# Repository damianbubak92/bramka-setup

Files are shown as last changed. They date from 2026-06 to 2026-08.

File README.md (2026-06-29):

# Bramka IoT - Setup & Development Repository

Repozytorium konfiguracji i kodu dla bramki IoT na AM62 SoC (SK-AM62B-P1 dev kit).

## Architektura

- **SoC**: TI AM62 (Cortex-A53 quad + Cortex-M4F + Cortex-R5F)
- **Linux**: Arago 2025.01 (kernel 6.18.13-ti, ARM64)
- **Komunikacja**: Linux ↔ M4F przez RPMsg (binary protocol z CRC16)
- **Język aplikacji Linux**: Go 1.23.x (instalowany przez `Gateway/Setup/modules/04-go.sh`)
- **Firmware M4F**: TI MCU+ SDK 12.00, NoRTOS

## Struktura repo

> Ten README opisuje **wczesny stan (sama bramka, RPMsg)**. Projekt urósł do
> **monorepo `SmartHome`** (engine M4F, CC1310 RF, nody, apka Android) — pełny
> aktualny stan, konwencje i Session Log w **`CLAUDE.md`**. (Repo na GitHub wciąż
> nazwany `bramka-setup`; może zostać przemianowany na `SmartHome`.)

```
SmartHome/                (zmigrowane z bramka-setup 2026-06-29)
├── Gateway/              # bramka (A53 Linux + M4F + CC1310 RF)
│   ├── Software/         #   Go: rpmsg-service (RPMsg bridge + HTTP/WS API, cgo)
│   ├── Firmware/         #   CCS: M4F (gateway_m4f) + CC1310 (gateway_cc1310)
│   ├── Setup/            #   setup.sh, modules/, systemd/, tools/, config.sh
│   └── Hardware/         #   carrier board (TODO)
├── Nodes/                # TempHumNode/{Firmware = temphum_node, Hardware}, Light/Solar (szkielety)
├── Apps/                 # MobileApp/AndroidApp/SmartHomeV2 (Android Studio); iOS/, WebApp/ (TODO)
├── Shared/               # Protocol/ (node_protocol.h, protocol.h, spi_frame.h — SINGLE SOURCE), KiCadLib/
└── Docs/
```

## Quick start

### 1. Instalacja bramki (od zera)
```bash
# 1. Świeży flash karty SD (Etcher)
# 2. SSH do bramki:
git clone https://github.com/damianbubak92/bramka-setup
cd bramka-setup/Gateway/Setup
sudo ./setup.sh    # network + tools + m4f firmware backup + GO INSTALL
reboot
# 3. Z laptopa:
Deploy-M4F                                            # custom M4F firmware
Deploy-Go -ServiceName rpmsg-service -Build           # build Go binary
Install-GoService -ServiceName rpmsg-service          # systemd unit
```

### 2. Workflow developerski

**M4F firmware** (z laptopa, PowerShell):
```powershell
# Build w CCS Theia (Ctrl+Shift+B)
Deploy-M4F                         # 5s logów
Deploy-M4F -LogForever             # logi do Ctrl+C
Deploy-M4F -NoLogs                 # bez logów
```
> `m4f-reload` (woła go `Deploy-M4F`) sam zatrzymuje `rpmsg-service` przed
> `echo stop` M4F i restartuje po starcie. Bez tego serwis wykryłby zniknięcie
> `/dev/rpmsg` jako PEER DEAD i zrobił reboot bramki w trakcie podmiany firmware.

**Go service** (z laptopa, PowerShell):
```powershell
Deploy-Go -ServiceName protocol-test -Build -Run
```

### 3. Monitor

```bash
ssh root@bramka-01
m4f-watch                          # live M4F trace
```

## Status (v5)

- ✅ Setup script (Linux configuration, network, tools, M4F firmware)
- ✅ M4F graceful shutdown handler (hot-swap firmware bez reboot)
- ✅ Go runtime (cgo działa, łączy się z shared C header)
- ✅ Binary protocol (CRC16-CCITT, packed wire format, big-endian)
- ✅ HELLO/HELLO_ACK exchange w binary protocol
- ✅ State machine: DISCONNECTED → HELLO_SENT → CONNECTED → DEAD
- ✅ Reliable DATA delivery (ACK + 3 retries z 1s timeout)
- ✅ Idempotency check (duplicate detection w M4F)
- ✅ EVENT (M4F→Linux autonomous events z ACK + retry)
- ✅ Bidirectional reliable messaging w pełni działa (~5ms RTT)
- ✅ **Warstwa A**: systemd watchdog dla Go service (`Restart=on-failure` + `StartLimitBurst=3`)
- ⏸️ **Warstwa B**: M4F self-watchdog (RTI) - skipped, do later
- ⏳ **Warstwa C**: M4F → Linux reset via DMSC
- ✅ **Warstwa D**: Linux HW watchdog (`/dev/watchdog` via systemd, `RuntimeWatchdogSec=30`) - konfigurowany przez `modules/05-watchdog.sh` (był zgubiony przy re-flashu, przywrócony 15.06.2026)
- ✅ **panic_on_oops=1** (`modules/06-kernel-panic.sh`): oops → pełny panic → łapie Warstwa D. Domyka lukę "oops kaleczy kernel ale systemd dalej klepie watchdog → nic nie łapie"
- ✅ **Boot accounting** (`modules/07-boot-accounting.sh`): licznik bootów + atrybucja przyczyny (breadcrumb Go / kernel panic / clean-shutdown / hard reset) + alarm reboot-storm (sparametryzowany `/etc/bramka/boot-accounting.conf`, default >3/24h). Persistent journald (50M). Podgląd: `bramka-reboots`
- ✅ **Non-root hardening** (`modules/08-hardening.sh`): `rpmsg-service` jako user `bramka` (zero capabilities). Device przez udev (grupa `bramka`), reboot przez path-unit (`bramka-reboot.path/.service`, bez roota/polkit). Binarka w `/opt/bramka` (Deploy-Go: cel `/opt/bramka`)
- ✅ **Heartbeat jednokierunkowy Linux→M4F**: Go pinguje M4F co 5s idle; brak odpowiedzi (~9s) = M4F martwy → **clean reboot** (`recoverByReboot`). M4F-initiated heartbeat usunięty (opcja A). Brak per-core reset M4F na AM62 - jedyna recovery to pełny reset SoC.
- ✅ **Cold-boot race fix**: serwis czeka na `/dev/rpmsg*` (`waitForM4FChrdev`) zamiast paść gdy M4F jeszcze się podnosi
- ⏳ Yocto build - later

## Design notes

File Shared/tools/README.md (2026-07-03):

# Shared/tools

Dev-laptop helpers (PowerShell), wersjonowane dla odtwarzalności / disaster-recovery.

## `Microsoft.PowerShell_profile.ps1`

Snapshot profilu PowerShell z laptopa deweloperskiego. **To kopia** — żywy plik
to `$PROFILE` (`C:\Users\<user>\Documents\WindowsPowerShell\Microsoft.PowerShell_profile.ps1`).
Po zmianach w profilu odśwież tę kopię (`cp $PROFILE Shared/tools/`).

Zawiera:
- **Bramka deploy helpers**: `Deploy-Go`, `Deploy-M4F`, `Install-GoService`,
  `Watch-M4F`, `Test-Rpmsg`, `Connect-Bramka`, `Get-M4FState` (`$BRAMKA_HOST = root@192.168.2.170`).
- **KiCad**: `Add-LcscPart` (alias `lcsc`) — pobiera część z LCSC przez
  `easyeda2kicad` i wpina do bibliotek `Shared/KiCadLib` (symbol z auto-footprintem,
  footprint → `SmartHome.pretty`, model 3D → `3dmodels`). Idempotentny
  (wykrywa po property `"LCSC Part"`); `lcsc <id> -Force` = odśwież.
  Wymaga `pip install easyeda2kicad`.

### Przywrócenie na nowym laptopie
```powershell
mkdir (Split-Path $PROFILE) -Force
Copy-Item Shared/tools/Microsoft.PowerShell_profile.ps1 $PROFILE -Force
pip install easyeda2kicad   # dla helpera KiCad
. $PROFILE
```

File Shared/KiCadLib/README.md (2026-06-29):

# Shared/KiCadLib — współdzielona biblioteka KiCad (SmartHome)

Wspólne **custom / vendor** symbole, footprinty i modele 3D dla wszystkich projektów
hardware w monorepo (`Gateway/Hardware`, `Nodes/*/Hardware`).

## Co tu trzymamy (a czego NIE)
- ✅ Części **niestandardowe / vendor / specyficzne**: CC1310 (QFN RGZ 7×7), balun,
  holder 18500, MCP73123 / TPS63900 / MCP3421, nietypowe złącza, antena.
- ❌ **Generyczne pasywy** (R/C/L SMD, diody ESD, generyczny QFN) — bierz z
  **wbudowanych bibliotek KiCada** (`Resistor_SMD`, `Capacitor_SMD`,
  `Package_DFN_QFN`…). Nie kopiuj ich tutaj — biblioteka ma być chuda.

## Struktura
```
Shared/KiCadLib/
├── SmartHome.pretty/      # footprinty (1 plik .kicad_mod = 1 footprint)
├── SmartHome.kicad_sym    # symbole (utwórz w Symbol Editor → New Library, gdy rysujesz własne)
└── 3dmodels/              # modele 3D (.step / .wrl)
```

## Rejestracja w KiCad (raz na maszynę)
1. **Preferences → Configure Paths** → dodaj zmienną:
   - `SMARTHOME_LIB` = `C:/SmartHome/Shared/KiCadLib`
2. **Preferences → Manage Footprint Libraries → Project Specific Libraries** → **Add**:
   - Nickname: `SmartHome`
   - Path: `${SMARTHOME_LIB}/SmartHome.pretty`
3. (Symbole, jeśli są) **Manage Symbol Libraries → Project Specific** → **Add**:
   - Nickname: `SmartHome`
   - Path: `${SMARTHOME_LIB}/SmartHome.kicad_sym`

> Zakładka **Project Specific** = tabela (`fp-lib-table` / `sym-lib-table`) jedzie z repo
> → odtwarzalne. Każda nowa maszyna ustawia tylko `SMARTHOME_LIB` (krok 1) i działa.
> Modele 3D w `.kicad_mod` referencjonuj przez `${SMARTHOME_LIB}/3dmodels/...`.

## Użycie
Przy przypisywaniu footprintu/symbolu wybierasz bibliotekę **`SmartHome:`**
(np. `SmartHome:CC1310_RGZ_VQFN48`).

## Git
- `.kicad_mod` / `.kicad_sym` / `.pretty` = tekst → commituj normalnie.
- `.step` / `.wrl` = binarne → commituj jeśli małe; duże/pobieralne lepiej pominąć.

## Uwaga RF (CC1310 QFN)
Sprawdź land-pattern z datasheet TI — **thermal pad + raster vias pod padem masy**
są krytyczne dla RF i termiki. Generyczny `QFN-48-1EP_7x7mm_P0.5mm` może wystarczyć,
ale porównaj z zaleceniem TI; jak się różni → zrób custom footprint tutaj.

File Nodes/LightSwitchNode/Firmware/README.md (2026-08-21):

## Example Summary

Application that toggles an LED(s) using a GPIO pin interrupt.

## Peripherals & Pin Assignments

When this project is built, the SysConfig tool will generate the TI-Driver
configurations into the __ti_drivers_config.c__ and __ti_drivers_config.h__
files. Information on pins and resources used is present in both generated
files. Additionally, the System Configuration file (\*.syscfg) present in the
project may be opened with SysConfig's graphical user interface to determine
pins and resources used.

* `CONFIG_GPIO_LED_0` - Indicates that the board was initialized within
  `mainThread()` also toggled by `CONFIG_GPIO_BUTTON_0`
* `CONFIG_GPIO_LED_1` - Toggled by `CONFIG_GPIO_BUTTON_1`
* `CONFIG_GPIO_BUTTON_0` - Toggles `CONFIG_GPIO_LED_0`
* `CONFIG_GPIO_BUTTON_1` - Toggles `CONFIG_GPIO_LED_1`

## BoosterPacks, Board Resources & Jumper Settings

For board specific jumper settings, resources and BoosterPack modifications,
refer to the __Board.html__ file.

> If you're using an IDE such as Code Composer Studio (CCS) or IAR, please
refer to Board.html in your project directory for resources used and
board-specific jumper settings.

The Board.html can also be found in your SDK installation:

```text
<SDK_INSTALL_DIR>/source/ti/boards/<BOARD>
```

## Example Usage

* Run the example. `CONFIG_GPIO_LED_0` turns ON to indicate driver
initialization is complete.

* `CONFIG_GPIO_LED_0` is toggled by pushing `CONFIG_GPIO_BUTTON_0`
* `CONFIG_GPIO_LED_1` is toggled by pushing `CONFIG_GPIO_BUTTON_1`

## Application Design Details

* The `gpioButtonFxn0`/`gpioButtonFxn1` functions are configured in the driver
  configuration file. These functions are called in the context of the GPIO
  interrupt.

* Not all boards have more than one button, so `CONFIG_GPIO_LED_1` may not be
toggled.

* There is no button de-bounce logic in the example.

TI-RTOS:

* When building in Code Composer Studio, the configuration project will be
imported along with the example. These projects can be found under
\<SDK_INSTALL_DIR>\/kernel/tirtos/builds/\<BOARD\>/(release|debug)/(ccs|gcc).
The configuration project is referenced by the example, so it
will be built first. The "release" configuration has many debug features
disabled. These features include assert checking, logging and runtime stack
checks. For a detailed difference between the "release" and "debug"
configurations, please refer to the TI-RTOS Kernel User's Guide.

FreeRTOS:

* Please view the `FreeRTOSConfig.h` header file for example configuration
information.

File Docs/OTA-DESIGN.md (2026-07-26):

# OTA-DESIGN.md — Over-The-Air updates (DESIGN, not yet implemented)

> **Status: ZAPROJEKTOWANE 2026-07-27, NIEzaimplementowane.** Wdrożyć gdy flota urośnie
> (dużo nodów, grupy tego samego typu — wtedy broadcast się opłaca). Ten plik trzyma
> pełny projekt na każdym poziomie. Powiązane: `NODE-MANAGEMENT.md` (§14 = kanał downlink),
> `CLAUDE.md` (long-term). [[nack-downlink-pending-commands]] [[near-term-roadmap]]

## 0. Zasady przekrojowe (każdy poziom)
- **A/B + rollback** wszędzie gdzie się da — nieudany update NIGDY nie brickuje, zwłaszcza zdalnego noda i bramki-huba.
- **Power-fail-safe + atomowo** — zapis do nieaktywnego slotu, atomowy flip wskaźnika.
- **Podpisane (ECDSA P-256)** — autentyczność; klucz prywatny na HSM, nigdy na urządzeniu.
- **Poufność end-to-end dla nodów** — obraz zaszyfrowany, deszyfrowany TYLKO wewnątrz noda → koniec sniffu RF → reverse-engineeringu.
- **Macierz kompatybilności** — protokół spina warstwy (§14 spina 4); bundle niesie wersje + reguły kolejności.
- **Bramka (Go) = orkiestrator** — ciągnie bundle, weryfikuje, aplikuje warstwa po warstwie.

---

## 1. OTA nodów (trudna część)

### 1.1 Układ: CC1312R (migracja z CC1310) — ZAKLEPANE
CC1310 (128 KB flash) **nie mieści A/B** (solar 73 KB, T&H 65 KB → 2×73 = 146 KB > 128 KB — zmierzone z map-plików). **CC1312R:** 352 KB flash, 80 KB RAM, Cortex-M4F, **HW AES-128/256 + ECC/RSA PKA + SHA2 + TRNG** (secure OAD w sprzęcie), **cap-sense + Sensor Controller** (idealne pod LightSwitch), **ten sam package 7×7 + layout RF** co CC1310, tańszy (~$3 vs $3.8), więcej stocku LCSC. Ten sam SimpleLink CC13x2 SDK; regeneracja `smartrf_settings` pod PHY bramki CC1310 → **mieszana flota** (CC1310 bramka + CC1310 stare nody + CC1312 nowe) gada. **R7 (704 KB) niepotrzebny** — R1 ma ogromny zapas. Nowe nody (switch, presence) = CC1312; stare CC1310 = bez field-OTA (rzadki reflash po kablu) albo rev na CC1312.

### 1.2 Layout flasha (352 KB)
`BIM (~30 KB, write-protected, root of trust)` + `Slot A (~130 KB)` + `Slot B (~130 KB)` + `NVS/metadata (~16 KB)` + `CCFG (ostatnia strona)`. ~306 KB użyte, ~46 KB zapasu.

### 1.3 Crypto + klucze
**Format obrazu (encrypt-then-sign):**
```
[ header: wersja, typ, rozmiar, flagi ]
[ ciphertext: AES-CCM(firmware) ]                        ← poufność + integralność per-blok
[ signature: ECDSA-P256(SHA256(header‖ciphertext)) ]     ← autentyczność producenta
```
Weryfikacja (ECDSA + hash) PRZED deszyfracją → fail-fast; weryfikator nie potrzebuje klucza deszyfrującego.

**Dwa klucze:**
- **Podpis (ECDSA):** para producenta. Publiczny wypalony w KAŻDYM nodzie (BIM). Prywatny na HSM, nigdy na urządzeniu.
- **Szyfr (AES): per-device root + klucz grupowy per-update** (wzorzec LoRaWAN FUOTA):
  - **Root per-device (stały):** `klucz = KDF(master_secret, factory_id)`. Master na HSM. Nod ma tylko swój; KDF jednokierunkowy → jedna kompromitacja ≠ master ≠ inne nody.
  - **Klucz GRUPOWY/sesji per-update (rotujący):** losowy na update, szyfruje broadcastowany obraz. Dostarczony każdemu nodowi **owinięty jego kluczem per-device** (malutki unicast). Nod odwija → deszyfruje broadcast.
  - Daje: broadcast (obraz raz) + rotujący klucz grupowy + bezpieczną rotację + ograniczoną szkodę. **Bramka trzyma ZERO sekretów** (relayuje ciphertext) → kompromitacja bramki nic nie wycieka.
- **Anti-rollback:** monotoniczny licznik wersji; nod odrzuca wersję ≤ aktualnej.

**Debug-lock (produkcja, OBOWIĄZKOWE — bez tego cała reszta fikcja):**
- CCFG: `CPU_DAP_ENABLE=0`, wszystkie test-TAP `=0`, `BOOTLOADER_ENABLE=0` → JTAG/cJTAG + ROM-bootloader zamknięte. Zablokowany chip: debugger nie odczyta, tylko mass-erase (kasuje sekret). Sektory BIM write-protected.
- **Uwaga:** CC13x2R = „secured MCU", NIE secure element. Zatrzymuje tanie ataki (JTAG dump, bootloader read). NIE zatrzymuje fault-injection / side-channel / decap-microprobe (flash niezaszyfrowany at-rest). Bardzo cenne IP → zewnętrzny SE (ATECC608/SE050). Per-device KDF ogranicza szkodę nawet fizycznego ataku (jeden nod, jeden update).

### 1.4 Transport (RF)
Trzy warstwy rozmiaru: chunk aplikacyjny (dowolny) / ramka RF (≤255 B, 1-bajtowa długość; realny limit z błędów bitowych + airtime) / ramka SPI (nasz wybór).
- **DECYZJA: podnieść ramkę SPI 128 B → 256 B** (stała) → RF (255 B) = SPI (256 B) **1:1** → M4F to czysty relay (bez składania), liczba ramek o połowę mniejsza (~325 vs 680 dla 73 KB). Koszt: +~1 ms SPI/mała wiadomość (pomijalne; podbić zegar SPI), **re-test stabilności collision-fixa**, +RAM. RF zostaje zmiennodługościowe (mała telemetria bez paddingu); tylko OAD używa pełnych 255 B.
- **ARQ: windowed broadcast** (burst okna ramek, bez ACK per ramka) + **poll każdego noda o bitmapę braków** (round-robin unicast, unika ACK-storm) + **retransmit UNII braków** + iteracja. Nod pisze każdą ramkę wprost do nieaktywnego slotu (flash = progres wznawiania). Deszyfracja per-blok AES-CCM przy odbiorze; **final ECDSA nad całym obrazem** przed swapem.
- **Broadcast floty:** obraz nadany RAZ dla N nodów tego typu → ~1,2-1,5× airtime jednego (nie N×). Maruder ze złym łączem → unicast-repair albo później.

### 1.5 Normy (EN 300 220, 868 MHz) — haczyk duty-cycle dla OAD
| Pasmo | Moc | Duty | TX/h |
|---|---|---|---|
| 868.0–868.6 (telemetria) | 25 mW | **1%** | ~36 s |
| **869.4–869.65 (OAD)** | **500 mW** | **10%** | **~360 s** |

OAD 73 KB = ~15-30 s TX bramki → **za ciasno na 1%** (wiele nodów/retry przekracza). **OAD → przełącz na 869.4-869.65 (10%)** — mieści się z zapasem. CC13xx przestraja trywialnie; „enter OAD" niesie kanał; retune → OAD → retune. Wymaga 2. `smartrf_settings` (kanał OAD). Alt: LBT+AFA. 500 mW wymaga **zewn. PA na bramce** (CC1312 sam = +14 dBm/25 mW) — opcjonalne (zasięg), nie konieczne dla 10% duty.

### 1.6 BIM + A/B (cykl życia per nod)
**BIM** = immutable root-of-trust (write-protected, **NIGDY nie OTA** — zrobić dobrze, zamrozić). Trzyma publiczny ECDSA + wybór slotu + verify. Na boocie: czyta nagłówki obu slotów, weryfikuje, wybiera valid+newest+confirmed, skacze (VTOR).
**Nagłówek slotu:** `{magic, wersja, rozmiar, SHA-256, podpis ECDSA, flagi VALID/CONFIRMED/PENDING, licznik prób}`.
**Cykl:** download→nieaktywny slot → verify (hash+podpis+wersja) → mark PENDING → reset → BIM bootuje PENDING (TRY, odnotowuje próbę) → nowy app self-check + **CONFIRM do bramki** → mark CONFIRMED → gotowe. Crash/no-confirm w oknie → **BIM wraca na drugi CONFIRMED slot**. Zero bricka.
**Uruchamianie z obu slotów:** (A) obraz relokowalny (BIM ustawia VTOR, jeden wariant) — elastyczne; lub **(B) dwa warianty A/B + lockstep** (broadcast wariantu pod nieaktywny slot, out-of-sync repair unicastem) — prostsze, pasuje do „flota update'owana razem". **Rekomendacja: B na teraz.**

### 1.7 Koordynacja broadcast + swap
Każdy nod swapuje **niezależnie** (jego BIM), ale bramka dyryguje w fazach:
1. **Dystrybucja:** broadcast + poll/retransmit aż WSZYSCY mają komplet (zweryfikowany, PENDING, nie zrebootowany).
2. **Commit:** bramka broadcastuje „commit/swap now" (ew. z timestampem) → wszyscy reboot ~razem → confirm.
3. **Maruderzy/porażki:** brak confirm → nod rolluje się sam (BIM); bramka retry indywidualnie albo zostawia na starym. **Rollback per-node.**
Nikt nie swapuje aż wszyscy MAJĄ obraz; minimalne okno mieszanych wersji; awaria jednego nie blokuje grupy.

---

## 2. OTA bramki (prostsza: osiągalna, zasobna, jedna sztuka)

### 2.1 Cała bramka = JEDNA jednostka RAUC
`rootfs + Go + M4F + gateway-CC1312` w JEDNYM podpisanym obrazie RAUC, po HTTPS (istniejąca infra + pinning). Swap całości (GB, ale download w tle w nocy). Bez broadcastu (jedna sztuka). Decyzje:
- **M4F: plik w rootfs, ładowany przez remoteproc** → jedzie z RAUC A/B. **Odrzucono OSPI A/B** (przerost formy; utrata niezależności M4F na zaplanowany reboot ~30-40 s (do 15-20 s po odchudzeniu) jest OK; recovery TI to i tak pełny reset).
- **Go: w rootfs** → A/B za darmo.
- Coupling Go↔M4F (`protocol.h`) rozwiązany: są w tym samym obrazie → atomowo.

### 2.2 RAUC A/B (rootfs)
Dwie partycje rootfs (A/B) + u-boot `bootcount`/`altbootcmd` (rollback). RAUC pisze nieaktywną → verify (hash+podpis) → try → reboot → zdrowy → `rauc mark-good` (health-check: Go serwuje, M4F żyje, CC RF up); N padów → `altbootcmd` wraca. **`/var/lib/bramka` (SQLite: config/nody/historia/klucze) na OSOBNEJ partycji** → przeżywa swap (NIE ruszać). Verdin: mechanizm Toradex (RAUC/Mender w BSP).

### 2.3 Gateway CC1312 — bundlowany, uproszczony (BIM + JEDEN slot, bez A/B)
W przeciwieństwie do zdalnych nodów, gateway CC jest **PO DRUCIE** (SPI z M4F) → **M4F jest jego recovery** (zawsze doflashuje) → **A/B niepotrzebne:**
- Gateway CC1312 = **BIM (immutable) + JEDEN slot app.** Golden image w rootfs (jak plik M4F) → wersja CC podąża za rootfs → **RAUC A/B na rootfs = rollback CC**.
- **Boot:** reboot w nowy rootfs → nowy M4F sprawdza wersję CC po SPI → mismatch → flashuje CC z golden w rootfs → CC BIM verify (podpis) → CC reboot → M4F confirm → serwuje → mark-good.
- **Rollback:** RAUC wraca na stary rootfs → stary M4F → CC mismatch → flashuje CC z powrotem na starą → spójny stary stack.
- **Power-fail w trakcie flashu CC:** slot app CC nieważny → BIM czeka → M4F doflashuje na następnym boocie. BIM immutable → brak bricka.
- **HW (carrier board): M4F GPIO → CC nRESET + boot-pin.**

### 2.4 Atomowy cutover
Stage wszystko (nowy rootfs z M4F+Go+CC-golden do nieaktywnej partycji, verify) → **jeden reboot flipuje cały stack** (u-boot → nowy rootfs → nowy M4F → flashuje CC pod siebie) → spójny nowy. Rollback flipuje wszystko z powrotem → spójny stary. **Bramka nigdy w niespójnym stanie protokołu.**

### 2.5 Poufność
Firmware bramki po HTTPS (szyfr w tranzycie) — **nie sniffowalny po RF** (obraz dla samej bramki, po IP). At-rest na eMMC opcjonalnie LUKS/dm-crypt (device-secret / AM62 key store) jeśli IP wrażliwe. Prościej niż nody. Ten sam podpis ECDSA weryfikuje bundle.

---

## 3. Orkiestracja + kolejność
Bramka (Go) dyryguje:
- **Stack bramki (rootfs+Go+M4F+gateway-CC) = jeden bundle RAUC, atomowy cutover.**
- **Nody = osobny RF OAD**, wg macierzy kompatybilności (bramka mówi wersją floty; wspiera N i N-1 podczas przejścia floty).
- Trigger: zaplanowany (noc) / z apki / auto z maintenance window.

---

## 4. Status + otwarte
- **Status: ZAPROJEKTOWANE, NIEzaimplementowane.** Wdrożyć gdy flota ma grupy same-type (broadcast się opłaca).
- **Otwarte decyzje (na czas implementacji):** relokowalny obraz vs dwa warianty (§1.6), rozmiar okna/bloku, dedykowany kanał OAD vs interleave, klucz-produktowy-MVP vs pełny per-device od startu (skłon: per-device), zewn. SE (tylko jeśli IP wymaga).
- **Prerekwizyt:** naprawa niezawodności radia CC1310/CC1312 („Kolizja/restart radia" backlog) — OAD amplifikuje problemy łącza.
- **Powiązany backlog:** szybki reset SAMEGO M4F (sekundy, bez pełnego reboota Linuxa) — optymalizacja na przyszłość, patrz CLAUDE.md.

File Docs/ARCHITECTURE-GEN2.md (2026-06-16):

# Architektura Gen2 — port silnika automatyzacji na AM62

> Żywy dokument projektowy. Bazuje na **sprawdzonej gen1** (CC3235 + CC1310, działa 2 lata
> bezawaryjnie). Gen2 przenosi role na AM62: silnik na M4F (RTOS), host/chmura/UI na A53/Linux,
> CC1310 zostaje jako radio sub-GHz. Kody gen1 (referencja): patrz pamięć `legacy-gateway-code`.

## 1. Podział ról

```
Node RF ──EasyLink──> CC1310 ──SPI──> M4F (RTOS)                 A53 / Linux
                       (radio)         ├─ NodesData (autorytatywny stan)
                                       ├─ ENGINE automatyzacji (deterministyczny)
                                       └─ akcje do nodów                ▲ RPMsg ▼
                                                                  ┌─────┴───────┐
                                                                  │ remote access (telefon/web)
                                                                  │ telemetria → chmura
                                                                  │ SQLite (config+reguły=źródło prawdy)
                                                                  │ NTP/czas
                                                                  └─────────────┘
```

- **CC1310** (slave SPI): koncentrator RF (EasyLink, ACK+retry). „Lean radiomodem" — buforuje pakiety, gada z M4F po SPI. RF bez zmian vs gen1.
- **M4F** (RTOS, SPI master): real-time hub. Odbiera dane nodów, trzyma `NodesData`, **ewaluuje reguły**, wysyła akcje. Raportuje w górę przez RPMsg. Trzyma aktywny zestaw reguł w RAM (cache).
- **A53 / Linux**: config/UI/chmura. SQLite = źródło prawdy (reguły+config). API dla telefonu (CRUD reguł, sterowanie, statystyki). Telemetria do chmury. NTP. **JSON parsowany TYLKO tutaj** — M4F dostaje reguły binarnie.

## 2. Decyzje architektoniczne (log)

| # | Decyzja | Uzasadnienie |
|---|---|---|
| D1 | Silnik na **M4F + RTOS** (FreeRTOS, MCU+ SDK) | Determinizm, brak round-tripa do Linuxa na każdą regułę. M4F = mocny dedykowany rdzeń. |
| D2 | **M4F = SPI master**, CC1310 = slave | Determinizm enginu (master włada timingiem; ISR od slave tylko flaguje), backpressure, multi-drop (drugi radiomodem na CS), lean CC1310. |
| D3 | **2 linie handshake** `MASTER_READY`/`SLAVE_READY` | Sterownik SPI wymaga uzbrojenia slave (`SPI_transfer`) ZANIM master taktuje. Sprawdzone w gen1 (zalecenie TI). |
| D4 | **JSON + persystencja na Linuxie**, M4F dostaje reguły binarnie przez RPMsg | M4F lean/deterministyczny; Linux ma zasoby na rosnące JSON-y i typy nodów (to powód gen2 — CC3235 by się zatkał). |
| D5 | Engine **event-driven** (nie polling 60s jak gen1) | Ewaluacja na napływ danych nodu + tick czasowy. Szybsza reakcja. |
| D6 | **Parytet najpierw**, generalizacja potem | `MessageStruct` jest domenowy (solar/bufor/pompa) — najpierw działać jak gen1, potem uogólnić model nodów. |
| D7 | `SPI FRAME_SIZE = 128 B` | Zapas na nowe typy nodów/pól. |
| D8 | `MAX_RULES = 100` | gen1=5 (limit FRAM). M4F RAM pozwala; realny smart-home. |
| D9 | Linux = źródło prawdy reguł; M4F = cache RAM, sync przez RPMsg | Atomic swap na M4F (wzór: FRAM dual-slot gen1). |

## 3. Protokół SPI — M4F (master) ↔ CC1310 (slave)

Mechanika identyczna jak gen1 (`spi_master_task.c` CC1310 + `spiTask.c` CC3235), role odwrócone.

### Linie GPIO (active-LOW, idle HIGH)
- `MASTER_READY`: M4F out → CC1310 in (IRQ falling) — „master chce nadać, slave uzbrój się".
- `SLAVE_READY`: CC1310 out → M4F in (IRQ falling) — „slave uzbroił `SPI_transfer()`, taktuj TERAZ" (uniwersalny sygnał *go*; też = request-to-send gdy CC1310 ma pakiet RF).

> Sedno (z kodu gen1): slave NAJPIERW woła `SPI_transfer()` (uzbraja bufory), DOPIERO POTEM ściąga
> `SLAVE_READY` w dół. Master taktuje na to zbocze. Bez `MASTER_READY` slave nie wie kiedy uzbroić
> się przy transferze inicjowanym przez mastera.

### Scenariusz A — M4F nadaje (komenda do nodu)
```
M4F:    assert MASTER_READY
CC1310: IRQ → SPI_transfer() [uzbroj] → assert SLAVE_READY
M4F:    IRQ na SLAVE_READY → SPI_transfer() [taktuje] → wymiana
oba:    deassert; M4F czeka na callback TRANSFER_DONE (timeout 300 ms)
```

### Scenariusz B — CC1310 ma pakiet RF (nadaje w górę)
```
CC1310: SPI_transfer() [uzbroj, TX=pakiet] → assert SLAVE_READY   (bez MASTER_READY)
M4F:    IRQ na SLAVE_READY → SPI_transfer() [taktuje] → odbiera pakiet → engine + RPMsg w górę
oba:    deassert
```

### Timeouty / retry (z gen1)
- Cykl: **300 ms**. Retry: **3×**. Potem zgłoszenie błędu (M4F → log/RPMsg).

### Ramka SPI (ulepszenie vs gen1: nagłówek + CRC + drenaż serii)
Stała ramka **128 B**:
```
[0]      magic 0xA5
[1]      type     (FRAME_NODE_DATA | FRAME_NODE_CMD | FRAME_ACK | FRAME_NOP)
[2]      seq
[3]      pending  ile JESZCZE ramek nadawca ma w kolejce → master drenuje aż 0
[4]      len      długość payloadu (≤ 120)
[5..6]   flags/reserved (0)
[7]      reserved (0)
[8..]    payload  (np. MessageStruct)
[126..127] CRC16-CCITT (jak w RPMsg, init 0xFFFF, poly 0x1021)
```
- `pending` rozwiązuje burst (wiele pakietów RF naraz) — kluczowe przy skalowaniu liczby nodów.
- CRC16 na poziomie ramki SPI — gen1 nie miał (polegał na CRC warstwy RF); to twardszy transport.

> **Parytet najpierw**: jak gen1, transfer traktujemy pół-dupleksowo per kierunek (strona „bierna"
> wysyła `FRAME_NOP`). Prawdziwy full-duplex piggyback (komenda M4F + pakiet CC1310 w jednej
> transakcji) = optymalizacja na później.

## 4. Protokół RPMsg — A53/Linux ↔ M4F

Rozszerza istniejący `shared/protocol.h` (sprawdzone: `[type][seq][len][payload][CRC16]` + ACK +
retry + heartbeat). Nowe typy (nie kolidują z 0x01–0x04, 0x10–0x11, 0x20, 0xF0–0xF1, 0xFF):

```c
/* Linux -> M4F (config / sterowanie) */
#define MSG_RULE_BEGIN     0x30u  /* payload: u16 ruleCount — start wgrywania zestawu */
#define MSG_RULE_ITEM      0x31u  /* payload: u16 index + AutomationRule (1 reguła/ramkę) */
#define MSG_RULE_COMMIT    0x32u  /* payload: u16 expectedCount + u32 crc32 — atomowy swap */
#define MSG_NODE_CMD       0x33u  /* payload: MessageStruct — komenda z telefonu → relay do nodu */

/* M4F -> Linux (telemetria / stany) */
#define MSG_NODE_TELEMETRY 0x40u  /* payload: MessageStruct — surowe dane nodu → chmura/DB */
#define MSG_NODE_STATE     0x41u  /* payload: NodesData snapshot — bieżące stany → telefon */
#define MSG_RULE_FIRED     0x42u  /* payload: u16 ruleIndex + RuleAction — audyt automatyzacji */
```
Reguła (~220 B) mieści się w jednej ramce RPMsg (`MAX_PAYLOAD_SIZE=480`). 1 reguła = 1 `RULE_ITEM`.

### Wgrywanie reguł (chunked, skalowalne, atomowe)
```
Linux: RULE_BEGIN(N) → RULE_ITEM(0) → … → RULE_ITEM(N-1) → RULE_COMMIT(N, crc32)
M4F:   buduje shadow-zestaw w RAM → na COMMIT (gdy count i crc32 OK) atomowy swap aktywnego zestawu
       → ACK. Częściowy/uszkodzony zestaw odrzucony (stary pozostaje aktywny).
```
Wzór niezawodności: gen1 FRAM dual-slot (nigdy nie zostajemy z połową zestawu).

### Synchronizacja przy starcie
Po `HELLO_ACK`: Linux czyta reguły z SQLite → `RULE_BEGIN..COMMIT` do M4F. **Linux = źródło prawdy**,
M4F = aktywny cache w RAM. (M4F po SoC reset wstaje szybciej niż Linux — czeka na push po HELLO.)

## 5. Struktury danych

Przeniesione z gen1 (`messageProtocol.h`, `automationRules.h`) — docelowo do `shared/` (wspólne dla
M4F C i Go cgo). **D6: parytet najpierw**, generalizacja modelu nodów później.

- `MessageStruct` (node↔gateway, ~49 B): `id, type, cmd, length, union{solarData|pumpData|buforData|textData}`.
- `NodesData` (snapshot stanów: T1..T4, Tin/Tout/Tcol, energyGain, flowRate, sBuforTemp, pumpState).
- `AutomationRule` (~220 B): `name[64], conditionCount, conditions[3], action`.
  - `RuleCondition`: TIME | PARAMETER (device.param OP threshold) | PARAMETER_DELTA (dev1.p1 − dev2.p2 OP delta). Do 3 warunków AND.
  - `RuleAction`: SET_RELAY (target, on/off) | SEND_MESSAGE (target, tekst).

## 6. Przepływy end-to-end

```
Telemetria:  node → RF → CC1310 → SPI(B) → M4F (NodesData+engine) → RPMsg NODE_TELEMETRY → Linux → chmura/SQLite
Automatyka:  M4F engine (event-driven: NODE_DATA + tick czasowy) → akcja → SPI(A) → CC1310 → RF → node
Edycja reguł: telefon → API Linux → SQLite → RPMsg RULE_BEGIN..COMMIT → M4F swap
Sterowanie:  telefon → API Linux → RPMsg NODE_CMD → M4F → SPI(A) → CC1310 → RF → node
```

## 7. Silnik na M4F (event-driven)

- Task RTOS „engine": czeka na (a) nowy `MessageStruct` z SPI (aktualizuje `NodesData`, ewaluuje),
  (b) tick czasowy (np. 1–10 s) dla warunków `CONDITION_TIME`.
- Ewaluator = port `evaluateAutomationRules()` (czysty C, bez zależności SDK). `getDeviceParameterValue()`
  czyta z `NodesData`. Czas z RTC M4F (źródło czasu TBD — z Linuxa przez RPMsg albo RTC na carrier).
- Akcja → `MessageStruct` → kolejka SPI do CC1310.
- Logika domenowa gen1 do zachowania (dedup pumpState, guard `sBuforTemp<0`) — przenieść lub uogólnić.

## 8. Mapowanie portu gen1 → gen2

| Gen1 (CC3235/CC1310) | Gen2 | Uwagi |
|---|---|---|
| `automationRules.c/.h` | **M4F** (RTOS task) | Port ~1:1, event-driven zamiast 60 s polling |
| `automationRulesJson.c/.h` | **Linux** | JSON tylko po stronie Linuxa |
| `coreTask.c` (orkiestracja) | **M4F** (routing nodów) + **Linux** (chmura/UI) | Rozdzielone |
| `spiTask.c` / `spi_master_task.c` | **M4F SPI master** + **CC1310 SPI slave** | Role odwrócone, mechanika gen1 |
| `wifiTask.c` (SimpleLink) | **Linux** (NetworkManager/wpa_supplicant lub modem) | Przepisać |
| `httpClientTask.c` (telemetria) | **Linux** | URL/api_key do refactoru (hardcoded gen1) |
| `httpsServerTask.c` (API telefonu) | **Linux** | Nowy stack remote access |
| `rulesFramStore.c` (FRAM) | **Linux SQLite** + M4F atomic swap | FRAM → DB; wzór dual-slot zostaje konceptualnie |
| `rtcControl.c` (NTP) | **Linux** (systemd-timesyncd) → czas do M4F | |
| `radio_task.c` / `rfWsnConcentrator.c` | **CC1310 bez zmian** | EasyLink RF zostaje |

## 9. Otwarte / przyszłość

- **Full-duplex piggyback SPI** — gdy ruch wzrośnie (na razie pół-duplex per kierunek, parytet).
- **Generalizacja modelu nodów** — `MessageStruct` domenowy → uogólniony (więcej typów nodów, pól).
- **Źródło czasu M4F** — RTC na carrier vs push z Linuxa przez RPMsg.
- **Warstwa C (DMSC reset)** — staje się realna, bo M4F trzyma żywe sterowanie (crash Linuxa nie może
  go zabić na ~70 s). Decyzja przy dojrzewaniu enginu.
- **Hardcoded gen1 do refactoru**: SSID/hasło Wi-Fi, URL+api_key chmury, auth token, adresy RF, strefa czasowa.
```

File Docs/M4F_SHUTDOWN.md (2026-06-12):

# M4F Graceful Shutdown Handler - REQUIRED for development workflow

## Why this matters

Linux remoteproc framework uses a handshake protocol to stop a remote core
(M4F in our case). When you run:

```bash
echo stop > /sys/class/remoteproc/remoteproc0/state
```

Linux:
1. Sends a mailbox notification (`IPC_NOTIFY_RP_MBOX_SHUTDOWN`) to M4F
2. Waits up to 10 seconds for M4F to send `IPC_NOTIFY_RP_MBOX_SHUTDOWN_ACK`
3. If no ACK arrives, returns `-EBUSY` (errno 16) and refuses to stop

**Without a shutdown handler in M4F firmware, every firmware deploy requires
a full system reboot.** This makes development painful and breaks OTA updates
in production.

## The bug we hit (and how we found the fix)

We initially tried the obvious order in our shutdown sequence:

```c
// WRONG ORDER - ACK never reaches Linux
Drivers_close();
IpcNotify_sendMsg(coreId, IPC_NOTIFY_CLIENT_ID_RP_MBOX,
                  IPC_NOTIFY_RP_MBOX_SHUTDOWN_ACK, 1u);
System_deinit();
__asm__ __volatile__ ("wfi" : : : "memory");
```

Result: M4F received shutdown notification, sent ACK, but Linux timed out
anyway. Mysterious - logs showed `Shutdown ACK sent to Linux` followed by
`notify_shutdown_rproc: timeout waiting for rproc completion event`.

The fix was found by reading the official SDK example
`ipc_rpmsg_echo_linux.c`. The correct order is:

```c
// CORRECT ORDER - matches SDK example
Drivers_close();
System_deinit();           // <-- BEFORE sending ACK
IpcNotify_sendMsg(coreId, IPC_NOTIFY_CLIENT_ID_RP_MBOX,
                  IPC_NOTIFY_RP_MBOX_SHUTDOWN_ACK, 1u);
__asm__ __volatile__ ("wfi" : : : "memory");
```

Hypothesis: `System_deinit()` resets internal SDK structures including
interrupt vectors and mailbox FIFO state. Sending ACK BEFORE deinit puts
the message into a buffer that subsequent cleanup might discard or route
incorrectly. Sending AFTER deinit ensures the message goes through the
"production" channel that Linux remoteproc is listening on.

This is undocumented but empirically verified.

## Required implementation in M4F firmware

### 1. Includes

```c
#include <drivers/ipc_notify.h>
#include <drivers/ipc_rpmsg.h>
#include <kernel/dpl/SystemP.h>
```

### 2. Shutdown state globals

```c
static volatile uint8_t gbShutdown = 0u;
static volatile uint8_t gbShutdownRemotecoreID = 0u;
```

### 3. Shutdown callback

Called by SDK when Linux sends shutdown notification.
**Keep it short** - it runs in interrupt context.

```c
static void ipc_rp_mbox_callback(uint16_t remoteCoreId, uint16_t clientId,
                                  uint32_t msgValue, void *args)
{
    if (clientId == IPC_NOTIFY_CLIENT_ID_RP_MBOX) {
        if (msgValue == IPC_NOTIFY_RP_MBOX_SHUTDOWN) {
            gbShutdown = 1u;
            gbShutdownRemotecoreID = (uint8_t)remoteCoreId;
            /* If using blocking RPMessage_recv elsewhere, call
             * RPMessage_unblock(&yourEndpoint) here to wake those tasks.
             * For callback-based RPMsg (no blocking recv), no unblock needed.
             */
        }
    }
}
```

### 4. Register callback (after `RPMessage_announce`)

```c
int32_t status = IpcNotify_registerClient(IPC_NOTIFY_CLIENT_ID_RP_MBOX,
                                           ipc_rp_mbox_callback,
                                           NULL);
DebugP_assert(status == SystemP_SUCCESS);
```

### 5. Modify main loop to exit on shutdown

```c
while (!gbShutdown) {
    /* your existing logic */
    ClockP_usleep(1000);
}

doShutdown();  /* never returns */
```

### 6. Shutdown sequence

**CRITICAL: order matters - System_deinit BEFORE sending ACK.**

```c
static void doShutdown(void)
{
    DebugP_log("[M4F] Shutdown requested by core %u\r\n",
                (unsigned int)gbShutdownRemotecoreID);
    DebugP_log("[M4F] Closing drivers, deinit system, sending ACK\r\n");
    
    Drivers_close();
    System_deinit();      /* MUST be before ACK send! */
    
    if (gbShutdownRemotecoreID != 0) {
        IpcNotify_sendMsg(gbShutdownRemotecoreID,
                          IPC_NOTIFY_CLIENT_ID_RP_MBOX,
                          IPC_NOTIFY_RP_MBOX_SHUTDOWN_ACK,
                          1u);
    }
    
    /* Halt CPU - wait for interrupt forever (none ever comes) */
    while (1) {
        __asm__ __volatile__ ("wfi" "\n\t": : : "memory");
    }
}
```

## Reference implementation

See `examples/m4f-baseline/ipc_rpmsg_echo.c` for a complete working firmware
with shutdown handler implemented correctly.

## Verifying shutdown handler works

After flashing firmware with shutdown handler, test by running deploy twice
without reboot:

```powershell
Deploy-M4F       # first deploy works (M4F was offline)
Deploy-M4F       # second deploy should ALSO work
Deploy-M4F       # and a third, fourth, etc.
```

If second deploy fails with `M4F won't stop (state: running)`, the firmware
lacks shutdown handler. Check the trace0 log:

```bash
cat /sys/kernel/debug/remoteproc/remoteproc0/trace0 | tail -10
```

You should see entries like:
```
[M4F] Shutdown requested by core 0
[M4F] Closing drivers, deinit system, sending ACK
```

If you see those but Linux still times out, check shutdown order - ACK must
come AFTER System_deinit, not before.

If you don't see those at all, the callback isn't being called - check
that `IpcNotify_registerClient` returned `SystemP_SUCCESS`.

## What NOT to do

### DON'T use unbind/bind as workaround

Tempting because it forces M4F to release without shutdown ACK:

```bash
# DON'T DO THIS
echo 5000000.m4fss > /sys/bus/platform/drivers/k3-m4-rproc/unbind
echo 5000000.m4fss > /sys/bus/platform/drivers/k3-m4-rproc/bind
```

**Problem**: Linux remoteproc never reuses numbers. After unbind/bind,
M4F moves from `remoteproc0` to `remoteproc4` (or higher). All scripts
hardcoding `remoteproc0` break, and the only way to restore is reboot.

### DON'T skip Drivers_close() / System_deinit()

If you skip these and just send ACK + WFI, the IPC infrastructure on M4F
isn't properly torn down. Next firmware load may inherit stale state and
crash mysteriously.

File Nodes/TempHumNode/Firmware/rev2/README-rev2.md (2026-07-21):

# rev-2 T&H sensor node — gen2 firmware

Firmware for the custom rev-2 climate sensor: **CC1310 + SHT35 (temp/hum) + MCP3421
(battery voltage → SoC) + LFP 18500 + USB charge**. A **sensor-only** gen2 node —
`capabilities = 0` (no actions; usable in automations only as a condition *source*,
e.g. feedback for a heating rule).

Reuses the proven gen2 mechanism from `SolarControllerNode` (JOIN / `'E'` frame /
factory_id / NVS address / ACK+retry). rev-1's SHT35 read is kept; **BQ35100 and
TPL5111 are gone** (rev-2 is rechargeable LFP with voltage-based SoC).

## Files here (add to the CCS project)

| File | Role |
|---|---|
| `node_identity.{c,h}` | FCFG factory_id + NVS address; `NODE_CAPABILITIES = 0` |
| `mcp3421.{c,h}` | MCP3421 18-bit ADC over I2C → battery µV/mV |
| `battery_soc.{c,h}` | LFP resting-voltage → SoC % LUT (**calibrate!**) |
| `th_sense.{c,h}` | I2C + PERIPH_EN facade: SHT35 + MCP3421 + SoC |
| `th_sensor_task.c` | app task: periodic sense + telemetry + JOIN downlinks |

Plus, **from `SolarControllerNode/Firmware`**, reuse: `rfEchoTx.c` (RF task), the
RF settings (`smartrf_settings`), the board file with the NVS internal region
(`Board_NVSINTERNAL`, `flashBuf @ 0x1A000`), and `main_tirtos.c`.

## Adapt `rfEchoTx.c` (3 edits)

1. **JOIN type** in `buttonCallback2`: `joinMsg.type = NODE_TH_SENSOR;` (6, not
   `SOLAR_CONTROLLER`). `joinData.capabilities = NODE_CAPABILITIES;` (already there;
   it resolves to 0 via this node's `node_identity.h`).
2. **Route RX to our task**: change the two externs it posts downlinks to —
   `solarControllerQueue → thNodeQueue`, `solarControllerEventHandle → thNodeEventHandle`
   (it already posts `EVENT_RECEIVE_CMD = (1<<1)`, which our task waits on).
3. Nothing else — the `'E'` framing, factory_id, ACK/retry and `PAYLOAD_LENGTH` are
   fine (thData telemetry is ~20 B, well under the frame).

`main_tirtos.c` order: `identity_init();` → RF task init → `thSensorTaskInit();`.

## Board file / SysConfig (rev-2 pin map — VERIFY against the final layout)

Schematic (2026-07-06): `SCL=DIO1, SDA=DIO2, UART_TX=DIO3, UART_RX=DIO4,
PERIPH_EN=DIO5, JOIN=DIO6, nCHRGSTAT=DIO7; JTAG TDO=DIO15, TDI=DIO16`.

- `Board_I2C0` → SDA/SCL (SHT35 `0x45`, MCP3421 `0x68`), 100 kHz.
- `Board_PERIPH_EN` (out) → DIO5 — gates the SHT35 rail (TPS22860) **and** the ADC
  divider MOSFET. Add to the GPIO table.
- `Board_nCHRGSTAT` (in, pull-up) → DIO7 — MCP73123 STAT (low = charging).
- `Board_GPTIMER2A` → the measure timer.
- `Board_NVSINTERNAL` → internal-flash region (already in the solar board file).
- JOIN button → DIO6 (rfEchoTx `buttonCallback2`; wake-from-standby later).

Bench-testing on a LaunchXL without the PERIPH_EN rail? Build with
`-DTH_NO_PERIPH_EN` (the gating calls become no-ops).

## Telemetry mapping (`thData`, type 6 — gateway already decodes this)

| field | rev-2 meaning |
|---|---|
| `temperature` | SHT35 °C |
| `humidity` | SHT35 %RH |
| `batt_mv` | LFP mV (MCP3421 × 1:2 divider × cal) |
| `soh_pct` | **repurposed as SoC %** (voltage LUT) |
| `acc_uah` | unused (0) |

Wire layout is unchanged, so the gateway decoder / DB / app need no changes. (A
dedicated `soc`/charging field can be added later if we want them distinct.)

## Bring-up plan (tomorrow)

1. Flash. On boot, unprovisioned → **silent** (no telemetry), only measuring.
   Check the UART log: `[TH] T=.. RH=..` each 60 s, `[TH] batt .. mV, SoC ..%`.
2. **Verify battery reading** against a multimeter on the cell. Adjust `MCP3421_CAL`
   (1-point cal) in `mcp3421.h` until `batt_mv` matches. Confirm the divider ratio.
3. **JOIN**: press the button → gateway shows a pending join (type 6, caps 0) → the
   app (or `approvejoin`) assigns an address → node adopts it (NVS), starts reporting.
   Confirm `node_param` gets temperature/humidity/batt_mv/soh_pct for the new node.
4. In the app, add an automation with a **condition** on this node (e.g.
   temperature < X) — it must appear as a condition source but **not** as an action
   target (caps 0).
5. **Calibrate the SoC LUT** (`battery_soc.c`): the table is a generic LFP curve.
   Replace with the real cell's resting points (coulomb-counted, not OCV-swept).

## Follow-ups (after telemetry is verified)

- Deep **standby**: RTC-wake period instead of a 60 s GPTimer awake loop; gate
  Display/UART; read battery pre-RF only. (Structure is already event-driven.)
- `TH_BATT_EVERY` is 5 for test convenience → raise for production (SoC moves slowly).
- Charging status (`th_sense_charging()`) is read but not yet sent — add a field if
  the app should show "charging".

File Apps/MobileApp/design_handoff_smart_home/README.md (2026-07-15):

# Handoff: Smart Home — Dashboard, System solarny, Czujnik klimatu

## Overview
Dashboard aplikacji do własnego systemu smart home (Android). Zawiera 3 okna:
1. **Dashboard** — ekran główny na żywo: szybkie sterowanie, kafle urządzeń „bez pokoju", pokoje, fotowoltaika.
2. **Czujnik klimatu** — szczegóły node'a bateryjnego mierzącego temperaturę i wilgotność (odczyty, wykresy 24 h / 7 dni / miesiąc / rok, ustawienie interwału pomiaru).
3. **System solarny** — schemat instalacji solarnej (kolektor + 2 zbiorniki + 2 pompy) z animacją pracy pomp oraz wykresy uzysku energii z zakresami dzień/miesiąc/rok/całkowite.

Docelowa platforma: **Android, Material Design**. Odbiorca: użytkownik domowy, każda grupa wiekowa.

## About the Design Files
Plik w tym pakiecie (`Smart Home App.dc.html`) to **referencja projektowa stworzona w HTML** — prototyp pokazujący docelowy wygląd i zachowanie, **a nie kod produkcyjny do skopiowania**. Zadaniem jest **odtworzenie tych ekranów w docelowym środowisku** (rekomendacja: Android + Jetpack Compose; alternatywnie Views/XML jeśli taka jest istniejąca apka) z użyciem natywnych komponentów i wzorców Material 3.

Mapa technologii (Compose): dolna nawigacja → `NavigationBar` + `NavHost`; karty → `Card`/`ElevatedCard` w `LazyColumn`/`LazyVerticalGrid`; wykresy → `Canvas` (opisane niżej — geometria gotowa) lub biblioteka typu Vico; schemat solarny → `Canvas` + animacja `rememberInfiniteTransition`; suwak → `Slider`; przełącznik → `Switch`; zapis ustawień → `DataStore`.

## Fidelity
**High-fidelity (hifi).** Finalne kolory, typografia, odstępy, animacje i interakcje. UI należy odtworzyć wiernie, używając bibliotek i wzorców docelowego kodu. Wartości liczbowe (temperatury, kWh, %) są przykładowe — docelowo pochodzą z bramki smart home / node'ów.

---

## Design Tokens

### Kolory — bazowe (ekran jasny / Dashboard)
| Rola | Hex |
|---|---|
| Tło aplikacji (ciepła biel) | `#F7F4EF` |
| Karta / powierzchnia | `#FFFFFF` |
| Tekst główny | `#201B13` |
| Tekst drugorzędny | `#6B675E` |
| Tekst wyciszony | `#8A857B` |
| Linia/separator | `#ECE6DA` |
| Aktywna pigułka nawigacji (tło) | `#FDECCB` |

### Kolory — semantyczne (kolor = charakter urządzenia)
| Domena | Akcent | Tło ikony (jasne) |
|---|---|---|
| System solarny / energia słońca | `#F6A21E` (głęboki `#E1850B`) | `#FDECCB` |
| Oświetlenie | `#C99400` (toggle ON `#E0A800`) | `#FBEFC7` |
| Ogrzewanie / termostat | `#D9542B` | `#FBE0D5` |
| Rolety | `#2F8F83` | `#D8ECE8` |
| Fotowoltaika (prąd) | `#2F6FB0` (na ciemnym `#6FA8DC`) | `#DCE9F6` |
| Klimat (temp+wilgotność) | `#0E7E95` | `#DBEEF4` |
| Status online / pompa pracuje | `#2E9E6B` | — |

### Kolory — ekrany szczegółów (pełny ekran, tekst biały `#FFFFFF`)
- **Czujnik klimatu**: tło jednolite `#0E7E95` (turkus). Kafel na dashboardzie: gradient `135deg, #22B0C6 → #0E7E95`.
- **System solarny**: tło jednolite `#E1850B` (pomarańcz). Kafel na dashboardzie: gradient `135deg, #F6A21E → #E1850B`.
- Na tych ekranach: separatory `rgba(255,255,255,.2)`; pigułka aktywna = białe tło + tekst w kolorze tła ekranu; elementy nieaktywne `rgba(255,255,255,.75)`; siatki wykresu `rgba(255,255,255,.16)`; etykiety osi `rgba(255,255,255,.7)`.

### Typografia
- Rodzina: **Roboto** (Google Font). Waga 200 i 300 dla dużych liczb, 400 tekst, 500/600 etykiety/nagłówki, 700 tytuły. `Roboto Mono` sporadycznie dla wartości technicznych.
- Duża wartość (np. `2,84 kW`, `21,8°C`): `font-weight 200`, `~46px`, `line-height 1`; jednostka `20px`, waga 400.
- Nagłówek ekranu (top bar): `500 20px`.
- Etykieta sekcji: `400 13px`, `opacity .8`.
- Wartość statystyki (runtime/yield): `300 26px`.
- Etykieta drugorzędna: `400 12–13px`.

### Promienie / cienie / odstępy
- Promienie: karty `20–26px`, mniejsze kafle `18–22px`, pigułki/taby `13–18px`, pełne pigułki/toggle `okrągłe`.
- Cień karty (jasny ekran): `0 2px 10px rgba(80,60,20,.06)`; hero/akcent: `0 14px 30px rgba(225,133,11,.32)` (solar) / `rgba(14,126,149,.30)` (klimat).
- Padding ekranu: `20–24px` po bokach. Odstępy między kartami: `12–14px`.
- Minimalny hit-target interaktywnych elementów: `44px`.

### Ramka urządzenia (tylko makieta)
Telefon: szerokość ekranu wewn. **398px**, wysokość **812px**, promień ~37px. Status bar: `20:34`, ikony + `51%`. Dolny pasek gestów (pigułka). W realnej apce to natywny chrome systemu — nie odwzorowywać.

---

## Screen 1 — Dashboard (ekran główny, tło `#F7F4EF`)

**Cel:** podgląd na żywo i szybkie sterowanie.

**Układ (pionowy scroll):**
1. **Nagłówek**: „Dzień dobry, Piotr" (`14px`, muted) + „Dom · Wszystko OK" (`500 26px`, `#201B13`); po prawej okrągły awatar 44px (tło `#EFE7D8`).
2. **Szybkie sterowanie** — 2 karty w rzędzie (`flex, gap 12`), każda białe tło, radius 22, padding 14:
   - **Światła**: ikona żarówki (`#C99400` na `#FBEFC7`, chip 40px r14), tytuł „Światła", podpis „3 włączone", **toggle ON** (tor `#E0A800`, 38×22).
   - **Rolety**: ikona (`#2F8F83` na `#D8ECE8`), „Rolety", „Otwarte 60%", **toggle OFF** (tor `#D9D3C7`).
3. **Sekcja „BEZ POKOJU"** (etykieta uppercase, muted) — urządzenia nieprzypisane do pokoju:
   - **Kafel „System solarny"** — gradient amber, biały tekst; badge „Sieć" (ikona wtyczki, tło `rgba(255,255,255,.2)`); duża wartość `23,7 kWh` + „Uzysk dzienny"; mini-wykres słupkowy (8 słupków, biały); wiersz: `73,2°C Zbiornik T4 · 62,3°C Bufor · 10h34 Praca pompy`. **Klik → ekran System solarny.**
   - **Kafel „Temperatura i wilgotność"** — gradient turkus, biały tekst; ikona termometr+kropla; badge baterii `87%`; dwie wartości: `21,8°C Temperatura`, `48% Wilgotność`; stopka „Pomiar 2 min temu · interwał 5 min". **Klik → ekran Czujnik klimatu.**
4. **„Pokoje"** — nagłówek + link „Wszystkie" (`#E1850B`); grid 2 kolumny:
   - **Salon**: ikona termostatu `#D9542B`, `22,4°`, „Grzeje · 3 światła".
   - **Sypialnia**: ikona termostatu `#D9542B`, `19,8°`, „Eco · rolety zam.".
5. **Pasek Fotowoltaiki** — ciemna karta (`#201B13`, radius 20): ikona pioruna `#6FA8DC` na `rgba(47,111,176,.20)`, „Fotowoltaika / Produkcja teraz"; po prawej `2,84 kW` (`#6FA8DC`) + „z 6,0 kWp".
6. **Dolna nawigacja** (białe tło, górna linia `#ECE6DA`): **Dashboard** (aktywny — ikona domu, pigułka `#FDECCB`), **Automatyzacje** (ikona pioruna), **Urządzenia** (ikona monitora). Etykiety `11px`. Pod nią pigułka gestów.

> Uwaga: „Automatyzacje" i „Urządzenia" to kolejne destynacje nawigacji (istnieją w prototypie, poza zakresem tego handoffu — do dokumentacji w następnej iteracji).

---

## Screen 2 — Czujnik klimatu (pełny ekran, tło `#0E7E95`, tekst biały)

Otwierany z kafla „Temperatura i wilgotność". Górny pasek: strzałka wstecz (←) + ikona termometr+kropla + „Czujnik klimatu" (`500 20px`). Status bar biały. Trzy sekcje oddzielone liniami `rgba(255,255,255,.2)`:

**Sekcja 1 — Aktualny pomiar**
- Etykieta „Aktualny pomiar" (`400 13px`, opacity .8); po prawej badge baterii `87%`.
- Dwie duże wartości obok siebie: `21,8°C` i `48%` (`font-weight 200, 46px`), pod nimi „Temperatura" / „Wilgotność".
- Stopka z ikoną zegara: „Pomiar 2 min temu · interwał {N} min" (N = aktualny zapisany interwał).

**Sekcja 2 — Dane historyczne**
- Segmentowany przełącznik metryki: **Temperatura | Wilgotność** (aktywny: białe tło, tekst `#0E7E95`).
- Pigułki zakresu: **24 h · 7 dni · Miesiąc · Rok** (aktywna biała).
- Wykres liniowy z wypełnieniem (area `rgba(255,255,255,.14)`, linia biała `2.5px`):
  - Oś Y: 3 etykiety (góra/środek/dół) z jednostką `°C` (temperatura) lub `%` (wilgotność).
  - Dla **temperatury**: pozioma **linia przerywana „zadana 22°C"** (`rgba(255,255,255,.55)`, dash `5 4`). Dla wilgotności ukryta.
  - Oś X: etykiety zależne od zakresu — 24 h: `0:00, 3:00 … 24:00`; 7 dni: `Pn…Nd`; miesiąc: `1,5,10…30`; rok: `Sty,Kwi,Lip,Paź,Gru`.
- Dane wykresu (przykładowe serie hardkodowane w prototypie): patrz `CH_DATA` w pliku.

**Sekcja 3 — Interwał pomiaru**
- Etykieta „Interwał pomiaru" + opis „Ustaw jak często dokonywać pomiaru".
- Duża wartość `{N}` + „min" (`200 44px`).
- **Slider** 1–5, krok 1 (biały uchwyt r14, tor białe wypełnienie do wartości, reszta `rgba(255,255,255,.28)`). Pod nim znaczniki `1 2 3 4 5`.
- **Przycisk „Zapisz interwał"** (białe tło, tekst `#0E7E95`) — **widoczny tylko gdy wartość zmieniona** względem zapisanej.
- Po zapisaniu: przycisk znika, pojawia się potwierdzenie „**Zapisano ✓**" (tło `rgba(255,255,255,.18)`), które **samo znika po ~2,6 s** z animacją fade (`@keyframes`: 0% opacity0/translateY6px → 12% widoczne → 78% widoczne → 100% opacity0).
- Wartość jest **trwała** (w prototypie `localStorage['climateInterval']`; docelowo `DataStore`).

---

## Screen 3 — System solarny (pełny ekran, tło `#E1850B`, tekst biały)

Otwierany z kafla „System solarny". Górny pasek: ← + ikona słońca + „System solarny". Dwie sekcje.

**Sekcja 1 — Aktualnie generowana moc + schemat**
- Wiersz: po lewej etykieta „Aktualnie generowana moc" + duża `2,84 kW` (`200 46px`); po prawej kolumna: podpis „Pompa dodatkowa", pod nim etykieta stanu **`ON`/`OFF`** (`600 14px`) + **duży przełącznik** (tor 64×36, uchwyt 28px; ON: biały tor + uchwyt `#E1850B`; OFF: tor `rgba(255,255,255,.30)` + biały uchwyt). Steruje drugą pompą (kolektor↔zbiornik / sBuf).
- **Schemat instalacji** (SVG, białe elementy na pomarańczowym). Układ poziomy, lewa→prawa:
  - **Kolektor słoneczny (heat-pipe)**: górny kolektor zbiorczy (belka), pod nią 10 pionowych rurek próżniowych, cienka dolna poprzeczka. Nad kolektorem wartość **Tcol `71,2°C`**, pod spodem podpis „Kolektor".
  - **Zbiornik główny** (duży, wyższy): 4 wartości temperatur od góry: `73,2°C, 64,1°C, 58,1°C, 51,5°C` (bez etykiet T1–T4 — pozycja = poziom). Podpis „Zbiornik główny".
  - **Zbiornik dodatkowy** (mniejszy): wartość `62,3°C`. Podpis „Zbiornik dodatkowy".
  - **Rury**: między kolektorem a zbiornikiem głównym oraz między głównym a dodatkowym — **po dwie rury** (górna „gorąca" = oś na wysokości kolektora zbiorczego; dolna „powrót" = oś na wysokości dolnej poprzeczki). Grubość ~5px, `rgba(255,255,255,.4)`.
  - **Pompy** (na górnych rurach): symbol inżynierski **trójkąt w kółku** (białe kółko, pomarańczowy trójkąt wpisany). **Praca = trójkąt obraca się wokół środka ciężkości** (`@keyframes spin`, ~1.15 s, `transform-box: fill-box`, `transform-origin` w centroidzie). Pompa kolektora: podpis „78%" (pompa o zmiennej prędkości), zawsze pracuje w tym stanie. Pompa dodatkowa: pracuje/stoi zależnie od przełącznika (stój = trójkąt nieruchomy, przygaszony `#C77D3A`).
  - Geometria SVG (viewBox `0 0 344 224`) jest w metodzie `buildSolarSchema()` — do przeniesienia na `Canvas`.

**Sekcja 2 — Uzyski energii**
- Etykieta sekcji „Uzyski energii".
- **Taby (wyśrodkowane)**: **Dzień · Miesiąc · Rok · Całkowite** (aktywny: biała pigułka, tekst `#E1850B`).
- **Nawigator okresu**: `‹` [etykieta okresu, np. „12 lip 2026"] `›` (okrągłe przyciski `rgba(255,255,255,.14)`). Zmienia oglądany dzień/miesiąc/rok w obrębie wybranego zakresu.
- **Wykres słupkowy** (słupki kremowe/białe `rgba(255,255,255,.72)`, najwyższy `#fff`; oś Y z jednostką kWh; oś X zależna od zakresu).
- **Podsumowanie** (górna linia separatora): po lewej „Czas pracy pompy" + wartość (`300 26px`); po prawej **wyrównane do prawej** „Uzysk energii" + wartość. **Oba synchronizują się z wybranym okresem** i zmieniają przy zmianie tabu/nawigacji.
- Dane per okres (przykładowe): patrz `SOLAR` w pliku (`day/month/year/total`, każdy z `bars`, `label`, `run`, `yield`).

---

## Interactions & Behavior
- **Nawigacja**: kafle „System solarny" i „Temperatura i wilgotność" na dashboardzie otwierają pełnoekranowe szczegóły; strzałka wstecz wraca. Dolna nawigacja przełącza Dashboard / Automatyzacje / Urządzenia (na ekranach szczegółów status bar jest biały, dolna nawigacja ukryta).
- **Toggle Pompa dodatkowa**: natychmiast zmienia stan pompy na schemacie (obrót/stop + kolor + etykieta ON/OFF).
- **Czujnik klimatu**: zmiana metryki/zakresu przerysowuje wykres; slider zmienia wartość na żywo; „Zapisz" pojawia się tylko po zmianie; po zapisie toast „Zapisano ✓" z auto-zanikiem ~2,6 s; wartość trwała.
- **System solarny**: taby + nawigator zmieniają wykres oraz zsynchronizowane „Czas pracy pompy" i „Uzysk energii".
- **Animacje**: obrót trójkątów pomp (spin, liniowy, ciągły); fade toastu; przejścia toggle/slider (`transition .2s`).

## State Management (stan potrzebny w apce)
- `activeTab`: dashboard | automatyzacje | urządzenia
- `openDetail`: none | climate | solar (który pełny ekran otwarty)
- Klimat: `metric` (temp|hum), `range` (24h|7d|month|year), `interval` (1–5), `savedInterval`, `toastVisible`
- Solar: `solarTab` (day|month|year|total), `periodIndex` (nawigator okresu), `sbufPumpOn` (bool)
- Dane realne (docelowo z bramki): temperatury zbiorników/kolektora, stany i % pomp, generowana moc, serie historyczne temp/wilgotności i uzysku, czas pracy pompy, uzysk per okres, stan baterii node'a i timestamp pomiaru.

## Assets
Brak plików graficznych. Wszystkie ikony i wykresy są rysowane inline (SVG/ścieżki) — w apce użyć **Material Symbols** / `Icons` i natywnego rysowania (`Canvas`). Ikony użyte: dom, piorun (PV/automatyzacje), monitor (urządzenia), żarówka, rolety, termometr, termometr+kropla, słońce, wtyczka, zegar, bateria, chevrony.

## Files
- `Smart Home App.dc.html` — kompletny prototyp wszystkich ekranów (+ nawigacja). Logika (dane wykresów `CH_DATA`, `SOLAR`, geometria schematu `buildSolarSchema`, wykresy `buildChart`/`buildBar`, automatyzacje `A_RULES`/`buildAuto`, urządzenia `A_DEVLIST`/`DEV_TYPES`/`buildDevices`) znajduje się w bloku `<script data-dc-script>` na końcu pliku — to najlepsze źródło dokładnych danych i geometrii.
- `NEXT_STEPS.md` — plan kolejnych iteracji (eksperyment z jednolitym motywem, stany puste, potwierdzanie usuwania).

---

## Screen 4 — Automatyzacje (lista, tło `#F7F4EF`)

Trzeci filar nawigacji. **Chrome neutralny (grafit `#201B13`)**; kolor akcentu dziedziczy się z **typu urządzenia docelowego** reguły.

**Lista:**
- Nagłówek „Automatyzacje" + wiersz statusu połączenia: **zielona kropka = „Połączono na żywo · N reguł, M aktywne"**, czerwona = „Brak połączenia z bramką" (dotknięcie w prototypie przełącza stan — realnie steruje tym WebSocket).
- Karta reguły: ikona akcji (kolor typu urządzenia docelowego), nazwa, streszczenie warunków, chip akcji „Urządzenie · Przekaźnik ON/OFF", przełącznik aktywności (**zielony = aktywna**, wyłączona = wyszarzona karta), akcje Edytuj / Usuń.
- Stan synchronizacji per reguła: spinner „Zapisywanie do bramki…" po zmianie; „Niezsynchronizowana · Ponów" (czerwony) gdy offline.
- **FAB „Nowa"** (grafit) → edytor.

**Model danych (3 typy warunków + 1 typ akcji, rozszerzalny):**
- Warunek **time**: `{ start, end }` (HH:MM).
- Warunek **param**: `{ device, param, op: gt|lt, value }`.
- Warunek **delta**: `{ device1, param1, device2, param2, op, min }` (różnica dwóch parametrów).
- Akcja: `{ target (urządzenie), type: relay, value: 0|1 }` (Ustaw przekaźnik ON/OFF).
- Reguła = wiele warunków połączonych logicznym **ORAZ** (wszystkie muszą być spełnione).

**Synchronizacja (WebSocket, realtime):** auto-zapis po zatwierdzeniu w edytorze i po przełączeniu — bez osobnego „Wyślij". Cykl: mutacja → `syncing`; ACK z bramki → `ok`; timeout/rozłączenie → `error`; reconnect → automatyczny retry wszystkich `error`. Optimistic UI.

## Screen 5 — Edytor automatyzacji (tło `#F7F4EF`)

- **Nazwa** (pole tekstowe).
- **Warunki** — lista kart, każda z segmentowanym przełącznikiem typu **Czas / Parametr / Delta** (aktywny = grafit); pola zależne od typu (time-pickery; wybory urządzenia/parametru przez bottom-sheet; operator Większe/Mniejsze niż; wartość/różnica liczbowa). Dodawanie/usuwanie warunków.
- **Walidacja**: błędny warunek → czerwona ramka + komunikat (pusta/niepoprawna wartość, ujemna różnica, identyczne parametry w Delcie, te same godziny). Zapis zablokowany (przycisk wyszarzony) dopóki są błędy.
- **Podgląd reguły** — jasna karta z osią **JEŚLI → TO**: warunki (z etykietą „ORAZ") i akcja z kolorową ikoną urządzenia + plakietka „Przekaźnik ON/OFF". Aktualizuje się na żywo.
- **Akcja**: urządzenie docelowe (bottom-sheet), typ „Ustaw przekaźnik", stan ON/OFF (segment).
- Footer: Anuluj / Zapisz.

## Screen 6 — Urządzenia (menadżer, tło `#F7F4EF`)

- Nagłówek + licznik „N urządzeń · M online".
- **Chipy filtra pokoi** (Wszystkie + istniejące pokoje; aktywny = grafit).
- Lista **pogrupowana po pokojach**; wiersz urządzenia: ikona w kolorze typu, nazwa, „Typ · online/offline", kropka statusu (zielona/czerwona), strzałka. Ten sam stan synchronizacji co reguły.
- **Dodawanie = przez JOIN**, nie z aplikacji: użytkownik wciska JOIN na urządzeniu → bramka przez WebSocket wypycha zdarzenie → aplikacja **sama otwiera edytor** z **typem wypełnionym i zablokowanym** (wykryty automatycznie, z kłódką). Użytkownik ustala tylko **nazwę** i opcjonalnie **pokój**; Zapisz / Odrzuć. (W prototypie odpala to przycisk „Symuluj urządzenie w trybie parowania (JOIN)".)
- **Edytor urządzenia**: podgląd ikony w kolorze typu, nazwa, typ (zablokowany), pokój (bottom-sheet), Usuń urządzenie (przy edycji).
- **Zarządzanie pokojami** — w bottom-sheet „Pokój": kosz przy każdym pokoju (poza stałym „Bez pokoju"), pole „Nazwa nowego pokoju" + „Dodaj". Usunięcie pokoju przenosi jego urządzenia do „Bez pokoju". Urządzenie „Bez pokoju" pokazuje się na Dashboardzie; przypisane do pokoju widać po wejściu w pokój.

## Typy urządzeń i kolory (semantyczne)
> **Aktualizacja motywu (najnowsza wersja):** apka używa **ciepłego** motywu — grafit = chrome (FAB, „Zapisz"), pomarańcz `#E1850B` oszczędnie na akcentach (aktywna pigułka nawigacji `#FDECCB`, aktywne segmenty tab-view = biała uniesiona pastylka z cieniem na torze `#E8E1D4`, segmenty ON/OFF), zielony `#2E9E6B` = przełączniki/status online. Karty reguł i podgląd czytają regułę jako pigułki: **JEŚLI** (Czas neutralny, parametry w kolorze urządzenia) „ORAZ" … **TO** pigułka akcji. Szczegóły i warianty (pomarańcz/turkus/grafit) w `NEXT_STEPS.md`.

Kolor = typ urządzenia (stała mapa w kodzie: `A_COLORS`):
- solar `#E1850B`, buffer `#A15C2B`, pv `#C0392B`, climate `#0E7E95`, light `#C99400`, blind `#2F8F83`, heating `#D9542B`, hub `#2E9E6B`.
Baza aplikacji: grafit `#201B13` (chrome/nawigacja/FAB/przyciski), zielony `#2E9E6B` (stany włącz/wyłącz, status online).

## Uwaga o kierunku wizualnym
Obecnie: **grafit = chrome, zielony = stany, kolor = typ urządzenia**. Pełnoekranowe ekrany szczegółów (Solar/Klimat) używają **motywu urządzenia** (całe tło w kolorze tożsamości, biała treść) — nazywane „color-flooded / device-themed surface" (NIE „hero"). Planowany eksperyment (patrz `NEXT_STEPS.md`): wariant z jednolitym motywem marki (pomarańcz lub turkus) do porównania.

## Nowy stan aplikacji (poza wcześniejszym)
- Auto: `rules[]` (z `_sync`), `autoView` (list|editor), `editing`, `picker`, `online`.
- Urządzenia: `devices[]` (z `_sync`), `rooms[]`, `devView` (list|editor), `devEditing`, `devFilter`.
- Wspólny: `confirm` (dialog usuwania: `{ title, msg, label, onOk }`).

## Stany puste (empty states)
- **Automatyzacje** — gdy brak reguł: ikona pioruna (bursztyn) + „Brak automatyzacji" + opis + przycisk „Nowa automatyzacja" (grafit).
- **Urządzenia** — gdy brak urządzeń: ikona + „Brak urządzeń" + podpowiedź o dodawaniu przez JOIN. Osobny stan gdy aktywny filtr pokoju nie ma urządzeń: „Brak urządzeń w tym pokoju" + „Pokaż wszystkie".

## Potwierdzanie usuwania (dialog)
Wspólny modal (backdrop `rgba(32,27,19,.45)` + biała karta wyśrodkowana): ikona kosza, tytuł, opis z nazwą obiektu, przyciski **Anuluj** (outline) / **Usuń** (czerwony `#C0392B`). Kliknięcie w tło = anuluj. Używany przy usuwaniu reguły automatyzacji (z listy) i urządzenia (z edytora). Usunięcie urządzenia ostrzega, że powiązane automatyzacje mogą przestać działać.

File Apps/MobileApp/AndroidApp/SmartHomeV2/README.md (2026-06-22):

# android-app — mirror apki sterującej (gen2)

Lustro **istotnych plików** aplikacji Android `GatewayCommunicatorGen2`. Tak jak
`cc1310-*firmware/` są kopią źródeł budowanych w CCS, tak ten katalog jest kopią
projektu Android Studio budowanego POZA repo:

```
C:\Users\damia\AndroidStudioProjects\GatewayCommunicatorGen2
```

To jest miejsce prawdy do **budowania** apki; tutaj trzymamy wersjonowane źródła
do przeglądu/historii. Po zmianach w Android Studio kopiujemy istotne pliki tutaj
(jak przy firmware).

## Co to za apka
Telefon ↔ bramka gen2 (AM62). `applicationId` / `namespace` =
`com.example.gatewaycommunicatorgen2` (w pełni oddzielone od gen1
`com.example.gatewaycommunicator`, żeby launcher ich nie mylił — patrz historia).
Transport: HTTPS **:9443** (POST komend) + **WebSocket `/ws`** (live), oba na tym
samym **pinningu cert + tokenie**.

## Kluczowe pliki
- `NetworkClient.java` — HTTP komendy (PUMP_ON/OFF, get/setrules, listjoins,
  approvejoin, listnodes, removenode) + wybór LAN/WAN + `baseWsUrl()`.
- `CertPin.java` — pinning leaf-certa po SHA-256 (factory + trust manager dla OkHttp).
- `GatewayWs.java` — singleton klient **WebSocket** (OkHttp + pinning), reconnect,
  parsuje zdarzenia `join_pending` / `node_status` / `telemetry`.
- `GatewayApp.java` — łączy/rozłącza WS wg foreground/background apki.
- `DevicesActivity.java` — ekran „Zarządzaj urządzeniami": lista nodów (live),
  provisioning event-driven (JOIN → okienko само), usuwanie (tap → dialog).
- `AutomationRules*` / `RulesAdapter` — CRUD reguł automatyzacji.
- `MainActivity.java` — ekran główny (pompa, reguły, urządzenia).

## Czego TU NIE MA (świadomie)
- `build/`, `.gradle/`, `.idea/`, `local.properties` (ścieżka SDK lokalna),
  Gradle wrapper (`gradlew*`, `gradle/wrapper/`).
- **`app/src/main/res/raw/cert.pem`** — cert pinowany przez apkę; dostarczany
  out-of-band (ten sam co `/etc/bramka/tls/cert.pem` na bramce). Zgodnie z
  `.gitignore` (`*.pem`) trzymany poza repo.
- `test/` / `androidTest/` (boilerplate).

## Build z tego mirrora (gdyby trzeba odtworzyć)
Skopiować do świeżego projektu AS, dodać Gradle wrapper, `local.properties` z
`sdk.dir`, oraz `app/src/main/res/raw/cert.pem`. Normalnie budujemy z katalogu
off-repo powyżej.

Kontrakt HTTP/WS po stronie bramki: `go-services/rpmsg-service/` (`httpapi.go`,
`wshub.go`, `nodecmd.go`).

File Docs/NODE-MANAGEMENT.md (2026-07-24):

# Zarządzanie nodami gen2 — model danych + kontrakt drutu

> Status: **SPEC ZATWIERDZONY** (19.07.2026, 5 decyzji przyklepane — §11). Kontrakt, na którym opieramy
> Go, firmware i apkę. Nic jeszcze nie zaimplementowane.
> Kolejność wdrożenia: (1) data model + migracja Go, (2) kontrakt drutu → firmware, (3) apka.

## 1. Cel i zasady

Profesjonalny cykl życia noda odporny na realne scenariusze: dodawanie, wymiana zepsutego chipa
z zachowaniem historii, usuwanie z możliwością odzysku, oraz „ożywający trup" nie robiący bałaganu
w eterze. Trzy zasady, z których wszystko wynika:

1. **Tożsamość logiczna ≠ adres ≠ chip.** Trzy osobne pojęcia (§2). Historia i automatyzacje wiszą
   na tożsamości logicznej, nie na adresie.
2. **Egzekwowanie tożsamości jest REAKTYWNE.** Bramka waliduje `(adres, factory_id)` przy KAŻDEJ
   telemetrii; nieznane wiązanie → odsyła „wypisz się i zamilcz". Poprawność nie zależy od dostarczenia
   żadnej komendy remove — system sam się leczy, gdy nod się odezwie.
3. **Kasowanie jest odwracalne w oknie czasu, ale tylko czasowo.** Bramka kasuje twardo (czysto),
   serwer trzyma w „koszu" przez retencję; trwałe usunięcie robi wyłącznie upływ czasu (żadnego
   ręcznego „opróżnij kosz" — dziecko z telefonem nie skasuje klientowi lat historii).

## 2. Tożsamość: `id` / `address` / `factory_id`

| pojęcie | co to | zmienność | gdzie |
|---|---|---|---|
| **`id`** | tożsamość LOGICZNA noda (kotwica historii i reguł) | **stała, NIGDY nie reużywana** (`AUTOINCREMENT`) | tylko baza bramki + mirror; **NIE na drucie** |
| **`address`** | adres RF do routingu (co leci na antenie) | reużywalny, może się zmienić, może być `NULL` (odłączony) | druk + baza |
| **`factory_id`** | aktualny fizyczny chip (CC1310 IEEE MAC z FCFG, 8B, globalnie unikalny) | zmienia się przy wymianie chipa, może być `NULL` | druk + baza |

**Dlaczego rozdzielone:** przywrócony z kosza nod czeka „bez adresu i bez chipa", a przy re-parowaniu
dostaje nowy wolny adres i nowy factory_id — historia trzyma się po `id`. Adresy zwalniają się od razu
przy kasowaniu (pula się nie zamraża). Automatyzacje po `id` przeżywają zmianę adresu.

**Limit `id`:** `INTEGER PRIMARY KEY AUTOINCREMENT` = 64-bit → max ~9,2×10¹⁸. Per bramka; w całym życiu
urządzenia zarejestrujesz setki nodów — granicy nie da się dojść. `AUTOINCREMENT` (nie goły rowid) jest
OBOWIĄZKOWY: gwarantuje, że id skasowanego noda nie wróci do nowego (inaczej kosz/restore by się rozsypał).

## 3. Schemat `node` + statusy

```sql
CREATE TABLE node (
  id             INTEGER PRIMARY KEY AUTOINCREMENT,  -- tożsamość logiczna, stała
  address        INTEGER,          -- 0x10-0xEF, NULL = odłączony; reużywalny
  factory_id     TEXT,             -- hex 8B, NULL = odłączony; unikalny wśród aktywnych
  node_type      INTEGER NOT NULL,
  name           TEXT,
  room           TEXT,
  status         TEXT NOT NULL,    -- pending_join | active | detached
  provisioned_at INTEGER,
  last_seen      INTEGER
);
-- adres i factory_id unikalne TAM GDZIE nie-NULL (nod może mieć naraz jeden adres/chip):
CREATE UNIQUE INDEX ux_node_addr    ON node(address)    WHERE address    IS NOT NULL;
CREATE UNIQUE INDEX ux_node_factory ON node(factory_id) WHERE factory_id IS NOT NULL;
```

**Statusy:**
- `pending_join` — przydzielono adres, czekamy aż nod potwierdzi (pierwsza telemetria pod nowym adresem+factory_id).
- `active` — potwierdzony, żywy (ma adres + factory_id).
- `detached` — przywrócony z kosza: ma `id` + historię, ale `address = NULL`, `factory_id = NULL`; czeka na sparowanie.
- `legacy` — nod gen1 podsłuchiwany (sniff), poza nowym modelem tożsamości — patrz §13. Też ma `factory_id = NULL`,
  ale to co innego niż `detached` (dlatego jawny status).

`pending_remove` **znika** — w modelu reaktywnym kasowanie jest natychmiastowe (hard-delete lokalnie + kosz
na serwerze), nie trzymamy wiersza czekając na potwierdzenie noda.

## 4. Kluczowanie historii i automatyzacji po `id`

Wszystkie tabele danych (`node_param`, `solar_history`, `solar_hourly/daily/monthly`, przyszłe per-typ)
kluczowane kolumną `node_id` = **`node.id`** (tożsamość logiczna), NIE adresem. Jeden komplet tabel per TYP,
wiele nodów tego typu współdzieli je przez `node_id` (nie per-node tabele — patrz decyzja niżej). Kasowanie
noda = `DELETE ... WHERE node_id = <id>` (kompaktowo, przez `dropSolarNode` uogólnione na wszystkie typy).

Reguły automatyzacji odwołują się do **`id`**. Silnik na M4F pracuje na ADRESACH (bo to jest na drucie);
Go mapuje `id → aktualny address` przy pushu reguł do M4F. Zmiana adresu (re-parowanie) → Go re-pushuje reguły
z nowym adresem → automatyzacja działa dalej bez ingerencji klienta.

## 5. Kontrakt drutu

### 5.1 factory_id w każdej ramce

Dziś ramka legitymuje się tylko adresem. **Dodajemy `factory_id[8]` na poziomie ramki** (poza
MessageStruct, żeby MessageStruct został 44B). Znaczenie: „nod, którego dotyczy ta ramka" —
nadawca przy uplinku (nod→bramka), adresat przy downlinku (bramka→nod).

Proponowana ramka (finalny layout dopinasz w firmware):
```
[ addr:1 ][ factory_id:8 ][ type:1 ][ MessageStruct:44 ][ seq:1 ][ crc:1 ]   // było bez factory_id
```
Koszt: +8B/ramkę. Dla noda co 2 min — airtime bez znaczenia; CC1310 sub-GHz mieści z zapasem.
(Rozważana lżejsza alternatywa — 1-bajtowy `epoch` per adres — ODRZUCONA: factory_id jest autorytatywny
i już istnieje, nie wymyślamy własnego licznika.)

### 5.2 Walidacja

- **Uplink (telemetria/JOIN/potwierdzenia):** bramka przyjmuje ramkę tylko gdy `(addr, factory_id)`
  = zarejestrowane aktywne wiązanie. Inaczej → `MSG_UNREGISTERED` w dół (§5.3). JOIN (addr=0xFF) jest
  wyjątkiem — zawsze akceptowany do rejestru pending (niesie factory_id w payloadzie, jak dziś). **Ramki
  legacy gen1** (stary format, bez factory_id) są zwolnione z tej walidacji — patrz §13.
- **Downlink (komendy):** nod wykonuje komendę tylko gdy `factory_id` w ramce = JEGO własne FCFG
  (nie sam adres). To zabija groźny przypadek: stary chip na reużytym adresie NIE wykona cudzej komendy.

### 5.3 Nowa komenda `MSG_UNREGISTERED` (bramka→nod)

Znaczenie: „nie jesteś zarejestrowany pod `(addr, factory_id)` — wykasuj przydzielony adres z NVS, wróć
do stanu fabrycznego, **zamilcz** i czekaj na JOIN". Zachowanie noda:
- Kasuje adres w NVS **raz** (idempotentnie), przechodzi w stan unprovisioned (adres 0xFF).
- **Przestaje nadawać telemetrię.** Nadaje wyłącznie JOIN po wciśnięciu przycisku.
- Gdyby komunikat zginął — nod ponowi telemetrię, dostanie `MSG_UNREGISTERED` znów (self-heal).

To utrzymuje porządek w eterze: żaden „trup" ani skasowany nod nie zapycha pasma niechcianymi danymi.

## 6. Przepływy cyklu życia

### 6.1 Dodaj nowe urządzenie
1. Przycisk JOIN na nodzie → `JOIN_REQUEST` (addr=0xFF, factory_id + typ w payloadzie).
2. Bramka → rejestr pending → apka: okienko „Dodaj nowe / Wymień istniejące".
3. User: **Utwórz nowe** → nazwa + pokój.
4. Bramka: nowy `node` (nowy `id`, `allocAddr`, `factory_id`=chip, `status=pending_join`) → `JOIN_ACCEPT`
   (target=factory_id, assigned address).
5. Nod: waliduje, że JOIN_ACCEPT jest dla jego factory_id → zapisuje adres w NVS → potwierdza (1. telemetria).
6. Bramka: na 1. poprawnej telemetrii → `status=active`.

### 6.2 Podepnij do istniejącego (= wymiana LUB re-parowanie przywróconego)
Jeden mechanizm, dwa wejścia. Apka ma DOKŁADNIE dwie opcje po JOIN: **„Utwórz nowe"** i **„Wymień istniejące"**.
„Wymień istniejące" → dropdown **kompatybilnych (ten sam typ) nodów logicznych**: aktywne (wymiana chipa)
ORAZ odłączone/`detached` (re-parowanie po restore). Pokazujemy nazwę + pokój + „ostatnio widziany".
1. Nowy chip → JOIN → apka „Wymień istniejące" → wybór noda `N`.
2. Bramka: `factory_id = nowy`; adres — jeśli `N` był aktywny, zostaje jego adres; jeśli `detached`,
   `allocAddr` nadaje nowy. `status=pending_join`. `JOIN_ACCEPT` (target=nowy factory_id, address).
3. Nowy chip potwierdza → `active`. **Historia pod `id` = `N` kontynuowana.**
4. Stary chip (jeśli żył): jego `(addr, stary factory_id)` ≠ wiązanie → `MSG_UNREGISTERED` → milknie.

### 6.3 Usuń urządzenie → kosz
1. Apka: „Usuń" → **twarde potwierdzenie** („to trwale usunie [nazwa] i X historii — wpisz nazwę").
2. Bramka: hard-delete `node` + jego historię lokalnie; **adres OD RAZU wolny** (`allocAddr` go odzyska).
   Do mirrora: `archive_node` (ustaw `archived_at`, **NIE kasuj** — kosz).
3. (Opcjonalnie best-effort) `MSG_UNREGISTERED` na ostatni adres `N`, żeby żywy chip zamilkł natychmiast.
4. Jak chip żywy a komunikat nie doszedł: odezwie się → `MSG_UNREGISTERED` → milknie (reaktywnie).

### 6.4 Przywróć z kosza
1. Apka: „Kosz" → lista archived w oknie retencji (nazwa, typ, „usunięto N dni temu", „trwałe za M dni").
2. „Przywróć" → bramka ściąga z mirrora dane noda (`id` + historia) → wstawia lokalnie z `address=NULL`,
   `factory_id=NULL`, `status=detached`. Mirror: czyści `archived_at`.
3. Nod widoczny w Urządzeniach jako „czeka na sparowanie".
4. Sparowanie: jak §6.2 (re-parowanie odłączonego) — nowy chip, nowy adres, historia dalej pod tym `id`.

### 6.5 Reaktywne „unregistered" (rdzeń odporności)
Każda telemetria z `(addr, factory_id)` nie pasującym do aktywnego wiązania → bramka odsyła
`MSG_UNREGISTERED` → nod kasuje adres, milknie. Pokrywa: ożywionego trupa, skasowanego offline-noda,
starego chipa po wymianie.

## 7. Alokacja adresów
`allocAddr` = najniższy wolny w puli 0x10-0xEF; „wolny" = brak `node` z tym `address` (nie-NULL).
Zwalniany OD RAZU przy kasowaniu (nod idzie do kosza z `id`, nie z adresem). `detached` mają `address=NULL`
→ nie trzymają adresu. Więc pula nie zamraża się przez kosz — twój kluczowy postulat.

## 8. Kosz, retencja, przywracanie (serwer)
- `gw_node` dostaje `archived_at BIGINT NULL`.
- `archive_node` (z bramki przy kasowaniu): `UPDATE gw_node SET archived_at=now WHERE id=?`. Historia
  (po `node_id`=id) zostaje — idzie za nodem.
- „Żywy" mirror = `archived_at IS NULL`. Przywracanie = bramka czyta archived noda → serwer czyści `archived_at`.
- **Cron na serwerze** kasuje fizycznie `node` + historię gdzie `archived_at < now - RETENCJA`
  (**60 dni**). **Wyłącznie czasowo**, zero ręcznego „opróżnij kosz".

## 9. Backup/mirror — zmiany
- Klucz mirrora `node_id` = `node.id` (stały) zamiast adresu. Triggery i restore bez zmian koncepcyjnie.
- Nowy kind `archive_node` (soft-delete) zamiast twardego `purge_node`. Trwały purge robi cron serwera.
- **Restore pojedynczego noda** (odzysk z kosza) — nowy endpoint/tryb: pull archived noda z mirrora do bramki.
- Pełny restore bramki (§disaster recovery) bez zmian — zaciąga aktywne nody (archived pomija).

## 10. Migracja z obecnego modelu (`node_id` = adres)
Dziś `node.node_id` = adres, historia kluczowana adresem. Jednorazowa migracja Go:
1. `node`: dodaj kolumny `id` (autoincrement), `address`; dla każdego istniejącego wiersza `address = stary
   node_id`, `id = kolejny autoincrement`.
2. Re-key historii: dla każdego noda `UPDATE <tabele> SET node_id = <new id> WHERE node_id = <stary adres>`.
3. Kilka nodów → trywialne. Mirror analogicznie (jednorazowy re-key albo świeży seed).

## 11. Decyzje — ZATWIERDZONE (19.07)
1. **Layout ramki**: `factory_id[8]` w **nagłówku ramki** (poza MessageStruct, zostaje 44B). Powód: zaraz po
   „wejściu" ramki do noda, potrzebne do sprawdzenia zgodności chipa przed dalszą obróbką. ✅
2. **Retencja kosza**: **60 dni**. ✅
3. **`pending_remove` usunięty** — kasowanie natychmiastowe + reaktywne. ✅
4. **Dokładnie dwie opcje w apce**: „Utwórz nowe" / „Wymień istniejące" (wymiana i re-parowanie pod jedną). ✅
5. **`MSG_UNREGISTERED` przy kasowaniu best-effort** (żywy chip milknie od razu) + reaktywny jako gwarancja. ✅

## 12. Kolejność wdrożenia
1. **Go + data model**: refaktor `node_id`→`id`+`address`, migracja, statusy, `allocAddr`, kosz/retencja/restore.
2. **Kontrakt drutu → firmware**: factory_id w ramce, walidacja, `MSG_UNREGISTERED`, zachowanie noda.
   (Node robisz raz — dlatego kontrakt PRZED firmware.)
3. **Apka**: dialog dodaj/wymień, dropdown kompatybilnych, kosz+przywracanie, confirm na usuwaniu.

## 13. Współistnienie z podsłuchem gen1 (legacy) — sniff ZOSTAJE

Nody gen1 (solar 0xF1, bufor 0xF2) są dalej podsłuchiwane (sniff bez ACK, [[provisioning-model]]) — nowy model
je **grandfathering'uje**, NIE wypadają z niego. Dlaczego się nie gryzą i jak to obsłużyć:

- **Rozłączność z natury**: adresy gen1 (0xF0+) są POZA pulą gen2 (0x10-0xEF); ramki gen1→0xF0, gen2→0x00;
  CC1310 rozróżnia je filtrem adresu (stąd log `SNIFF gen1`). gen2 pozostaje PASYWNY wobec gen1 (nie ACK-uje,
  nie odzywa się). Zero kolizji adresów, zero interakcji.
- **Ramki gen1 są w STARYM formacie — bez `factory_id`.** Więc ingest się rozgałęzia po obecności factory_id:
  - **Ramka legacy gen1** (bez factory_id) → routing po stałym adresie do noda `legacy`, zapis historii,
    **BEZ walidacji `(addr, factory_id)`, BEZ `MSG_UNREGISTERED`** (pasywnie, jak dziś).
  - **Ramka gen2** (z factory_id) → pełny nowy model (§5.2, §6.5).
- **W data modelu**: legacy nody = `id`(autoincrement) + `address`(0xF1/0xF2) + `factory_id = NULL` +
  **`status = legacy`**. Jawny status odróżnia je od `detached` (który też ma factory_id NULL, ale to
  przywrócony gen2 czekający na chip — co innego). Legacy nie przechodzą JOIN, nie są walidowane, nie dostają
  `MSG_UNREGISTERED`.
- **Reszta działa tak samo**: historia/agregaty/backup/restore po `id` (nody 241/242 już tak jadą).
- **Wygaszenie**: gdy user zdecyduje reflashować solar/bufor na firmware gen2 → JOIN → stają się pełnymi
  nodami gen2 (z factory_id) → sniff dla nich wypada. Do tego czasu współistnieją bezterminowo.

**Dla implementacji §12.1**: dodać status `legacy` do schematu; gałąź „legacy vs gen2" po obecności factory_id
w ramce (CC1310 taguje przy sniffie). Nie ruszać ścieżki sniff w `radio_task.c` — działa.

Powiązane: [[provisioning-model]], [[gen2-backup-mirror]], [[solar-aggregation-model]], `Docs/ARCHITECTURE-GEN2.md`.

## 14. Downlink przez NACK — dostarczanie komend nodom (pending-command) — DO IMPLEMENTACJI (zaprojektowane 24.07)

> **To DOPRECYZOWUJE dostarczanie z §5.3 / §6.4-6.5.** Wcześniejszy plan zakładał bezpośredni downlink
> `MSG_UNREGISTERED` na adres noda — ale **nod bateryjny śpi w STANDBY** (a always-on mógł być bez prądu),
> więc bezpośredni downlink trafia w próżnię. Rozwiązanie: bramka **nie pushuje** komendy — trzyma ją i
> **doręcza w odpowiedzi na najbliższy uplink noda**, w oknie ACK, jako **NACK niosący komendę**.
> **Uniwersalne dla WSZYSTKICH nodów** (śpioch / always-on / zombie / po reboocie bramki) — bez rozróżniania typu.

### 14.1 Dlaczego NACK (a nie osobne okno RX u noda)
CC1310 **ACK-uje autonomicznie na warstwie RF** (`radio_task.c`: buduje `[src]['A'][0x00][crc]` i `RF_postCmd`
NATYCHMIAST po odbiorze, DOPIERO POTEM forwarduje ramkę po SPI do M4F). Więc Go dowiaduje się o telemetrii długo
po zamknięciu ~50 ms okna ACK noda → **decyzja ACK-vs-NACK MUSI zapaść w CC1310**. Node i tak czeka na ACK po
każdym uplinku → doręczamy komendę w tym samym oknie = **zero dodatkowego poboru noda** (nie otwieramy nowego RX).

### 14.2 Mechanizm (pending-command z potwierdzeniem)
1. **CC1310 trzyma tabelę `{factory_id → cmd}`** (volatile RAM, ~16 wpisów). Klucz = **`factory_id`** (chip), NIE
   adres — adres jest reużywalny, więc kluczowanie po nim jest kruche (nowy nod na tym samym adresie dostałby cudzy
   NACK). Chip jest unikalny → nowy chip = inny factory_id → nigdy nie trafi w cudzy wpis.
2. Node (już `'E'`, z factory_id) wysyła uplink → CC1310: `factory_id` w tabeli?
   - **jest, a `msg.cmd == pending`** → to **confirm**: normalny ACK + **usuń wpis** (rozrywa pętlę „confirm też NACK") + forward do Go.
   - **jest, a `msg.cmd ≠ pending`** (zwykła telemetria) → **NACK** `[src]['N'][0x00][cmd]` zamiast ACK + forward.
   - **brak** → normalny ACK + forward.
3. Node w oknie ACK rozpoznaje `'N'` vs `'A'`, czyta `cmd` z bajtu [3] → **wykonuje** (np. `CMD_UNREGISTERED`: czyść
   NVS → shelf) → **odsyła confirm** (`'E'` z `cmd`=wykonana komenda) → Go dropuje wpis.
4. **Brak confirm** (przegapiony NACK / zgubiony confirm) → wpis zostaje → **kolejny uplink → kolejny NACK** → retry. Idempotentnie.

### 14.3 Dwupoziomowa odporność (rdzeń kuloodporności)
- **Tabela CC1310 = szybki cache (volatile).** Go uzbraja ją **proaktywnie** przy usunięciu → NACK już na PIERWSZEJ telemetrii (~4 min).
- **Rejestr Go (SQLite) = źródło prawdy durable.** Go uzbraja też **REAKTYWNIE**: każdy uplink `'E'`, którego
  `(addr, factory_id)` **nie pasuje do aktywnego bindingu** (usunięty / mismatch §5.2 / **ożywiony zombie**) → arm.
- **Reboot bramki / brak prądu**: tabela CC1310 (RAM) ginie — **nieważne**, bo po powrocie nod nada telemetrię, Go
  zobaczy „unregistered `factory_id`" w rejestrze → **znów uzbroi CC1310** → NACK przy najbliższej telemetrii (~4 min).
  **Nie persystujemy tabeli CC1310.**
- **Wniosek**: reaktywna ścieżka GWARANTUJE poprawność sama; proaktywne uzbrojenie to tylko przyspieszenie. Zastępuje
  to bezpośredni `SendRemove`/`SendUnregister` (który trafiał w próżnię do śpiącego noda) — **jedna droga: arm → NACK → confirm → drop.**

### 14.4 Kontrakt drutu (do dodania w `node_protocol.h` / `spi_frame.h`)
- **Odpowiedź RF** (4 B): `ACK=[src]['A'][0x00][echoed_crc]` (bez zmian) / **`NACK=[src]['N'][0x00][cmd]`** (nowa).
  `RF_REPLY_ACK 'A'`, `RF_REPLY_NACK 'N'`.
- **Telemetria T&H: `'D'` → `'E'`** (dokłada `factory_id[8]`). Bez tego CC1310 nie zna chipa nadawcy. Bonus: włącza §5.2 dla T&H.
- **Confirm**: zwykły uplink `'E'` z `msg.cmd` = wykonana komenda (np. `CMD_UNREGISTERED`).
- **Control-plane arm/disarm** (Go→M4F→CC1310):
  ```c
  #define SPI_FRAME_CTRL  0x04u   /* M4F -> CC1310: zarządzaj tabelą pending (payload = PendingCtrl) */
  #define CTRL_OP_ARM     1u
  #define CTRL_OP_DISARM  2u
  typedef struct {                 /* 10 B, bajtowo. RPMsg MSG_ARM_PENDING(0x35) i SPI_FRAME_CTRL */
      uint8_t op;                              /* CTRL_OP_* */
      uint8_t cmd;                             /* CMD_* do wysłania w NACK (ARM); 0 na DISARM */
      uint8_t factory_id[NODE_FACTORY_ID_LEN]; /* którego chipa dotyczy */
  } PendingCtrl;
  ```
  Nowy RPMsg `MSG_ARM_PENDING 0x35` (0x34=TIME_SYNC zajęty). ABI nietknięte: `MessageStruct`=44, `NodeFrame`=52, `PendingCtrl`=10.
- **CC1310**: `factory_id` już ekstrahowany (offset 3 w `'E'`), `msg.cmd` z offsetu 13 (dest+tag+src+factory_id[8]+2).

### 14.5 Uogólnienie na przyszłość (zakładka „Ustawienia")
Ten sam kanał doręcza **dowolną komendę** do noda, nie tylko unregister. Np. **interwał pomiaru**: apka → Go → arm
`{factory_id → SET_INTERVAL(X)}` → NACK przy najbliższej telemetrii → nod ustawia + confirm → drop. Dla komend
stanowych (nod dalej nadaje) confirm jest konieczny (inaczej Go re-armuje w kółko); dla unregister „ucichnięcie"
i tak potwierdza, ale jawny confirm zostaje dla jednolitości.

### 14.6 Kolejność implementacji (5 warstw)
1. **Protokół** (`node_protocol.h` + `spi_frame.h`): `'N'`/`'A'`, `PendingCtrl`, `SPI_FRAME_CTRL`, `MSG_ARM_PENDING`.
2. **Go**: arm proaktywny (remove) + reaktywny (uplink bez bindingu) + drop na confirm; `MSG_ARM_PENDING` po RPMsg; disarm przy (re)provisioningu chipa.
3. **M4F**: relay `MSG_ARM_PENDING` (RPMsg) → `SPI_FRAME_CTRL` (SPI).
4. **CC1310**: tabela `{factory_id→cmd}` + gałąź NACK/confirm w miejscu ACK-a.
5. **Node** (`radio.c`/`rfWsnNode.c`): telemetria `'E'`; rozpoznanie `'N'`+cmd w oknie ACK → wykonaj + confirm; `nvs_clear` → shelf.

Powiązane: [[provisioning-model]], [[rev2-th-node-bringup]], §5.3, §6.5.

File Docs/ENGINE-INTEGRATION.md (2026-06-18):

# Engine integration (M4F) — gen2 (FreeRTOS)

> Jak zbudować firmware M4F z silnikiem automatyzacji na **FreeRTOS** (MCU+ SDK
> 12.00). Bazuje na `docs/ARCHITECTURE-GEN2.md`. Decyzja: idziemy od razu na
> FreeRTOS + taski/kolejki (nie NoRTOS), żeby bieżące testy były adekwatne do
> docelowej architektury i nie było reworku przy wejściu SPI.

## Pliki i zależności

```
engine.c/.h         rdzeń: NodesData + ewaluator (port gen1) + atomic swap reguł.
                    RTOS-AGNOSTYCZNY (zero SDK/RTOS/RPMsg/SPI). Wspólny dla M4F i
                    Go (Go używa go automation.h przez cgo do enkodera reguł).
engine_rpmsg.c/.h   glue RPMsg: dekoduje RULE_*/NODE_CMD, reportery NODE_*/RULE_FIRED.
                    Decoupled wskaźnikami funkcji (tx_event / reply / tx_node).
ipc_rpmsg_echo.c    COMMS task + ENGINE task + kolejki (FreeRTOS). Setup, recovery,
                    heartbeat, retry — bez zmian względem zweryfikowanej wersji.
shared/automation.h     AutomationRule (196 B), warunki, akcje (kody jako #define).
shared/node_protocol.h  MessageStruct (44 B), NodesData (44 B).
shared/protocol.h       framing RPMsg + MSG_RULE_*/MSG_NODE_* (0x30–0x42).
```

**Do projektu CCS skopiuj płasko**: `engine.c/.h`, `engine_rpmsg.c/.h`,
`ipc_rpmsg_echo.c` + `shared/{automation.h,node_protocol.h,protocol.h}`.
(`m4f-firmware/protocol.h` to mirror `shared/protocol.h` — trzymaj zsynchronizowane.)

**Projekt musi być wariantem FreeRTOS** MCU+ SDK (kernel FreeRTOS w SysConfig).
Wymagane: `configSUPPORT_STATIC_ALLOCATION = 1` (używamy `xTaskCreateStatic` /
`xQueueCreateStatic` — bez sterty). Punkty do strojenia w `ipc_rpmsg_echo.c`:
`ENGINE_TASK_STACK_WORDS`, `ENGINE_TASK_PRIORITY` (ma być **niższy** niż task
comms, żeby RX/heartbeat/recovery nie były głodzone), `OUTBOX_DEPTH`, `NODEIN_DEPTH`.

### Dwie zmiany w projekcie CCS (zweryfikowane buildem 17.06)

1. **`linker.cmd` — zestaw reguł do DDR.** `g_rules[2][MAX_RULES]` to ~39 KB
   (MAX_RULES=100), a M4F DRAM ma tylko 64 KB → `.bss` się nie mieści. `g_rules`
   jest w sekcji `.bss.engine_rules` (atrybut w `engine.c`); dodaj do `SECTIONS`
   w `linker.cmd` mapowanie do DDR (obok `.bss.ipcctrl`):
   ```
   .bss.engine_rules (NOLOAD) : {} palign(8) > M4F_DDR
   ```
   Po zmianie (zweryfikowane): M4F_DRAM 46.5/64 KB, M4F_DDR 55.5/64 KB — z zapasem.
   ⚠️ Reguły są w DDR (czytane przez engine co ~1 s) — dla tej kadencji bez
   znaczenia; gdyby kiedyś trzeba twardego determinizmu, zmniejsz MAX_RULES i wróć
   do DRAM. Ten sam SoC w produkcji (Verdin AM62) → ten sam limit 64 KB DRAM.

2. **Debug UART w trybie CALLBACK.** Świeży `example.syscfg` ustawia
   `debug_log.uartLog.readCallbackFxn = "uart_echo_read_callback"`, więc
   `ti_drivers_open_close.c` odwołuje się do tego symbolu. `ipc_rpmsg_echo.c`
   dostarcza no-op stub (UART input nieużywany) — link się rozwiązuje. (Alternatywa:
   zmienić readMode na BLOCKING w SysConfig.)

### Build CLI (weryfikacja bez IDE)
Po skopiowaniu plików + `Refresh` w CCS makefile’e znają `engine.c`/`engine_rpmsg.c`.
Pełny link można sprawdzić z konsoli:
```
cd Debug && "C:/ti/ccs2051/ccs/utils/bin/gmake.exe" -j 8 all
```
Sukces → `Debug/*.appimage.hs_fs` ("Done !!!").

Lint lokalny (przenośne TU, bez CCS) — TI ARM clang z CCS:
```
tiarmclang -mcpu=cortex-m4 -mfloat-abi=hard -mfpu=fpv4-sp-d16 \
  -fsyntax-only -Wall -Wextra -I shared -I m4f-firmware engine.c engine_rpmsg.c
```
(`ipc_rpmsg_echo.c` ma zależności SDK+FreeRTOS — lint dopiero w CCS.)

## Architektura tasków (lock-free, wzór kolejek z gen1 coreTask)

```
                 RPMessage recvCallback (kontekst IPC RX)
                          | gRxBuffer.pending
                          v
   +----------------- COMMS task (= ipc_rpmsg_echo_main) -----------------+
   | JEDYNY właściciel RPMessage_send + gPendingAcks                      |
   |  - handleLinuxMessage(): HELLO/DATA/ACK/PING + engine_rpmsg_dispatch |
   |  - drainEngineOutbox(): report_rule_fired/telemetry + nodeTxSink     |
   |  - processEventRetries(), doPeriodicTick()                           |
   +----------^-------------------------------------------+--------------+
              | gOutboxQueue (engine->comms)              | gNodeInQueue (SPI->engine; pusta do czasu SPI)
              |                                           v
   +----------+---------------- ENGINE task -------------------------------+
   |  loop: xQueueReceive(qNodeIn, timeout=do najbliższej :00)            |
   |    dane nodu  -> engine_update_node + outbox(TELEMETRY)              |
   |               -> engine_evaluate(ENGINE_EVAL_NODE)  [reguły danych]  |
   |    timeout    -> engine_evaluate(ENGINE_EVAL_TIME)  [reguły czasowe] |
   |  akcja reguły -> engineActionSink -> outbox(RULE_FIRED)   (bez send!)|
   +---------------------------------------------------------------------+
```

## Kadencja ewaluacji (hybryda)

Reguły są **kubełkowane po warunkach** — każdy trigger dotyka tylko reguł, na
które może wpłynąć (bez marnowania CPU):

- **Reguły czasowe** (`COND_TIME`, też puste „always") → ewaluacja na **tick
  minutowy wyrównany do `:00`**. Timeout `xQueueReceive` liczony jako
  `engine_ms_to_next_minute()` (w **milisekundach**, sub-sekundowo — całe sekundy
  jitterują na granicy minuty: tik o włos przed `:00` → mikro-sen 1s → podwójny
  fire), przeliczany co pętlę → wiadomość od noda w pół minuty NIE przesuwa ticku
  (determinizm `:00`).
- **Reguły danych** (`COND_PARAMETER`/`_DELTA`) → ewaluacja **event-driven** na
  napływ danych nodu z `gNodeInQueue`.
- Reguła z czasem **i** danymi jest w obu kubełkach.

**Level-trigger, nie edge**: reguła odpala co przebieg dopóki warunek prawdziwy.
Anty-spam = **sprzężenie zwrotne ze stanu noda** (akcja pomijana, gdy node już
raportuje pożądany stan — guard solar `pumpState`), NIE zatrzask zboczowy: zgubiona
pierwsza komenda jest retransmitowana aż node potwierdzi. Uogólnienie feedbacku na
inne akcje stanowe ląduje z SPI (jedyny realny stan dziś to `pumpState`).
`SEND_MESSAGE` nie ma stanu noda → na razie leci co tick (decyzja odłożona do
remote-access — realne alerty będą param-driven).

**Zegar M4F**: `engine_set_time(h,m,s)` (z `MSG_TIME_SYNC`) ustawia ścianę czasu;
engine **dolicza** upływ z monotonicznego `EngineClockFn` (`ClockP_getTimeUsec`),
więc `COND_TIME` jest dokładny między syncami i tick trzyma się `:00`. Dryf
koryguje okresowy re-sync z Linuxa (NTP — remote-access).

**Wybudzanie przy time-syncu**: COMMS task po `MSG_TIME_SYNC` wrzuca na `gNodeInQueue`
sentinel `ENGINE_NODEIN_TIME_RESYNC` (wartość poza zakresem `NODE_*`, nigdy na drucie).
ENGINE task budzi się, robi `EVAL_TIME` od razu i **przelicza timeout z nowego zegara
→ wyrównanie do `:00` natychmiast** (bez sentinela pierwszy tick po syncu byłby skośny:
czekałby do końca trwającego snu). Dotyczy też re-syncu dryfu.

**Dlaczego bez mutexów** (jak w CC3235): jedyne kanały między taskami to kolejki.
- `RPMessage_send` + `gPendingAcks` dotyka **wyłącznie** COMMS task. ENGINE task
  nigdy nie woła send — wrzuca `outbox_item_t` na `gOutboxQueue`, comms drenuje.
- Aktywny zestaw reguł: lock-free przez konstrukcję — `engine_rules_commit()`
  podmienia indeks aktywnego bufora atomowo, a `engine_evaluate()` czyta go raz
  do lokalnej zmiennej → push w trakcie ewaluacji nie psuje bieżącego przebiegu.
- `gNodeInQueue` / `gOutboxQueue`: pojedynczy producent/konsument przez kolejkę.

## Przepływ wiadomości

```
Linux -> M4F (RULE_*/NODE_CMD):  COMMS recvCallback -> handleLinuxMessage
                                 -> engine_rpmsg_dispatch -> engine_rules_*/nodeTxSink
                                 -> reply MSG_ACK lub MSG_ERROR (echo seq)
Reguła fired (ENGINE):           engineActionSink -> gOutboxQueue
                                 -> COMMS drainEngineOutbox -> report_rule_fired
                                    (audyt do Linuxa) + nodeTxSink (SPI TODO)
Dane nodu (SPI, później):        SPI ISR/task -> gNodeInQueue -> ENGINE
                                 -> engine_update_node + outbox(TELEMETRY)
                                 -> COMMS -> report_telemetry (do Linuxa/chmury)
```

## Sygnalizacja wyniku rule-push (ważne)

- Sukces RULE_BEGIN/ITEM/COMMIT → M4F `sendReply(MSG_ACK, seq)` (echo seq).
- Odrzucenie (zły count/CRC/za duże/za wcześnie) → `sendReply(MSG_ERROR, seq)`.
  Go koreluje po seq i **natychmiast** zwraca błąd (bez czekania na retry/giveup).
  MSG_ERROR jest fire-and-forget (bez retry), echo-seq odrzuconej wiadomości.
- COMMIT robi atomic swap tylko gdy count i CRC32 się zgadzają; inaczej stary
  zestaw zostaje aktywny (wzór gen1 FRAM dual-slot).

## Strona Go (Linux) — enkoder rule-push

`go-services/rpmsg-service/rules.go`:
- Model reguł (Rule/Condition/Action) + `encodeRule()` budujący **bajtowo
  identyczny** obraz `AutomationRule` przez **cgo** (layout własności kompilatora
  C z `automation.h` — zero ryzyka rozjazdu offsetów Go↔C).
- `PushRules()`: `RULE_BEGIN(N)` → `RULE_ITEM(0..N-1)` → `RULE_COMMIT(N, crc32_ieee)`
  (każda reliable, ACK+retry). CRC32 = `hash/crc32.ChecksumIEEE` po obrazach reguł
  w kolejności indeksów = `crc32_calc` na M4F po tablicy shadow.
- `init()` sprawdza rozmiary ABI (`unsafe.Sizeof(C.AutomationRule)` == 196 itd.);
  rozjazd → `abiOK=false` → `PushRules` odmawia (korupcja gorsza niż brak funkcji).
- Test: `rpmsg-service -test push-rules` (przykładowe reguły = gen1 initExampleRules).

⚠️ **Deploy-Go musi kopiować `automation.h`** (poza dotychczasowym `protocol.h`) —
inaczej cgo w `rules.go` się nie zbuduje na bramce. `node_protocol.h` dorzuć, gdy
Go zacznie parsować payloady `NODE_*`.

## Co jest STUB / TODO

- **SPI → CC1310**: `nodeTxSink` tylko loguje; `gNodeInQueue` nikt nie zasila.
  Realne: SPI task (master + 2-linie handshake, ARCHITECTURE-GEN2 §3) →
  `gNodeInQueue` (dane nodu) i drenaż akcji do nodów (`qNodeOut`). Odblokowuje
  realne reguły danych + uogólnione sprzężenie zwrotne dla akcji stanowych.
- **Źródło czasu**: `MSG_TIME_SYNC` (h,m,s) → `engine_set_time` działa. Produkcyjnie:
  okresowy re-sync z NTP Linuxa (korekta dryfu) lub RTC carrier — §9 architektury.

## Testowalny milestone DZIŚ (bez SPI/CC1310)

1. CCS: projekt FreeRTOS z powyższymi plikami → build → `Deploy-M4F`.
   M4F log po starcie: `Engine initialized (0 rules); engine task spawned` +
   `Engine task started`.
2. Linux: `Deploy-Go -Build` (z `automation.h` w kopiowaniu!) →
   `rpmsg-service -test push-rules`.
3. Oczekiwane: każda `RULE_*` z ACK; `RULE_COMMIT` → atomic swap → ACK;
   `[rules] pushed 3 rules ... M4F committed`. `m4f-watch` pokazuje dispatch.
   - Firing reguł `COND_TIME`: `rpmsg-service -test fire-smoke` — time-sync
     12:00:50 + reguła w oknie 10–14h → pierwsze `RULE_FIRED` ~10s (wyrównanie
     do `:00`), potem co minutę. Reguły danych czekają na SPI (`gNodeInQueue`).

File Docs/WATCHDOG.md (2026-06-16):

# Watchdog Architecture

Bramka ma wielowarstwowy stack watchdog dla maksymalnej niezawodności
24/7 production. Każda warstwa łapie inny typ awarii.

## Stack overview

| Warstwa | Mechanizm | Wykrywa | Reakcja | Status |
|---|---|---|---|---|
| **A** | systemd Type=notify + WatchdogSec | Go service crash/hang | Auto-restart procesu (~2-3s) | ✅ |
| **B** | M4F RTI peripheral | M4F infinite loop/fault | Reset M4F core, remoteproc reload | ⏸️ |
| **C** | M4F→DMSC reset | Linux kernel hang (no kicks) | Reset main domain | ⏳ |
| **D** | Linux RTI HW watchdog | Total system freeze | HW reset całego SoC (60s timeout) | ✅ |

## Warstwa A: systemd watchdog (Go service)

### Mechanizm

Go service używa systemd protocol `sd_notify` przez `$NOTIFY_SOCKET`.

- Wysyła `READY=1` po starcie
- Wysyła `WATCHDOG=1` co `WATCHDOG_USEC/2` (5s w naszym przypadku)
- Wysyła `STOPPING=1` przed shutdown

systemd unit:
- `Type=notify` - czeka na `READY=1`
- `WatchdogSec=10s` - kill po brak 2 kicks
- `Restart=on-failure` - auto-restart po crash/timeout (NIGDY `always` - patrz CLAUDE.md NEVER VIOLATE)
- `RestartSec=2s` - opóźnienie między restartami
- `StartLimitBurst=3` / `StartLimitIntervalSec=60` - safety net przed restart-loop

### Detection

| Awaria | Detection method | Time to detect |
|---|---|---|
| `kill -9` | Process exit signal | ~natychmiast |
| segfault/panic | Process exit | ~natychmiast |
| Hang/deadlock | Brak `WATCHDOG=1` przez 10s | 10s |

### Recovery

systemd SIGABRT (dla watchdog timeout) lub kontekst exit (dla crash),
potem `Restart=always` triggers nowy start.

End-to-end: ~2-3s (RestartSec=2 + bootup time).

### Implementacja

- `systemd_notify.go` - minimalna sd_notify implementation
- `watchdogKicker()` goroutine w main.go - klepie co 5s
- `debugDisableWatchdog` flag dla testing (test mode `hang`)

## Warstwa D: Linux HW watchdog (/dev/watchdog)

### Mechanizm

Kernel driver `ti,j7-rti-wdt` exposes `/dev/watchdog0` jako character device.
Hardware peripheral counts down. systemd (PID 1) pisze do device co 30s,
reset countdown. Jeśli przestanie - po 60s **sprzętowy reset całego SoC**.

### Konfiguracja

W `/etc/systemd/system.conf`:
RuntimeWatchdogSec=30
Bez tego, `/dev/watchdog` jest aktywny po boot (kernel auto-start)
ale **nikt nie klepie** → bramka resetuje się co 60s!

**Konfigurowane automatycznie** przez `modules/05-watchdog.sh` w `setup.sh`
(idempotentne). Aktywacja wymaga reboota - PID 1 otwiera `/dev/watchdog0`
przy starcie. UWAGA (15.06.2026): wcześniej `system/configure-watchdog.sh`
nie był wołany przez setup → świeży obraz miał Warstwę D WYŁĄCZONĄ. Naprawione
modułem 05.

### Detection

| Awaria | Detection method | Time to detect |
|---|---|---|
| Kernel panic | systemd nie żyje, brak kick | ~60s |
| Total freeze | Brak jakichkolwiek kick | ~60s |
| systemd crash (PID 1) | Brak kick | ~60s |

### Recovery

**Hardware reset całego SoC**. U-Boot ładuje kernel od nowa,
systemd startuje, services wstają, M4F firmware loaded.

End-to-end: ~60-90s (60s timeout + 30s boot).

### Test verification

```bash
# Sprawdź czy systemd trzyma watchdog:
lsof /dev/watchdog0
# Powinno pokazać: systemd PID 1

# Symulacja kernel panic (UWAGA: resetuje bramkę!):
echo c > /proc/sysrq-trigger
# Czekaj ~60s, bramka się zrestartuje automatycznie
```

### panic_on_oops=1 — domknięcie luki "oops bez panic"

Warstwa D łapie tylko sytuacje, w których systemd PRZESTAJE klepać watchdog
(pełny panic, total freeze). Ale kernel **oops** (NULL deref, BUG()) domyślnie
(`panic_on_oops=0`) NIE jest pełnym panic - kernel ubija winny wątek i jedzie
dalej, często w niespójnym stanie. systemd żyje → dalej klepie /dev/watchdog0
→ **Warstwa D nie zadziała**, a bramka jest "żywa" ale faktycznie pokaleczona.

`modules/06-kernel-panic.sh` ustawia `kernel.panic_on_oops=1` (drop-in
`/etc/sysctl.d/60-bramka-panic.conf`), więc każdy oops → pełny panic → łapie
Warstwa D. Fail-fast: lepiej szybko paść i wstać niż cicho gnić.

NIE ruszamy `kernel.panic` (delay auto-reboota po panic) - recovery jest
zweryfikowane na ścieżce panic→HW watchdog (panic=0). Opcja na przyszłość:
`kernel.panic = 10` w tym samym drop-inie (szybszy reboot, HW watchdog backup).

## Recovery śmierci M4F: clean reboot (nie remoteproc stop!)

Osobny od warstw watchdog: gdy **M4F umrze/zawiesi się**, Go wykrywa to przez
heartbeat (PING co 5s idle, brak ACK po retry = ~9s) i emituje PEER DEAD.

**Akcja recovery = clean `reboot`** (`recoverByReboot` w `main.go`):
`syscall.Sync()` + `systemctl reboot` (fallback: kernel reboot). NIE robimy
`remoteproc stop/start`.

### Dlaczego nie remoteproc reload?

Test `silent-hang` (15.06.2026) udowodnił: na AM62 **nie ma per-core reset
M4F**. Zapis `stop` do `/sys/class/remoteproc/remoteproc0/state` na zawieszonym
M4F (interrupts disabled) **wiesza cały SoC** - bramka nieosiągalna, wymaga
ręcznego power cycle. Jedyna poprawna reakcja na martwy M4F to **pełny reset
SoC**. Clean reboot jest SD-friendly (robi sync); Warstwa D to backup gdyby
reboot się zawiesił.

(crash-m4f to inna ścieżka: M4F sam robi `SOC_generateSwWarmResetMcuDomain` w
hardfault handlerze - czysty reset TI, bez udziału Linuxa.)

## Lessons learned

### `nowayout` = nie ma odwrotu

AM62 watchdog ma flag `nowayout` w kernel - po starcie nie można
zatrzymać. Plus device jest tworzony automatycznie przy boot
(`/dev/watchdog0`). Czyli:

1. Bramka boot up
2. Watchdog hardware countdown rozpoczyna (60s)
3. **Jeśli nikt nie klepie → reset za 60s**

To powodowało nasze losowe reboot'y które wcześniej obwinialiśmy
o "niestabilność" - to był po prostu **właściwie działający
watchdog bez kicker'a**.

### systemd ma wbudowany kicker

Wystarczy `RuntimeWatchdogSec=N` w `/etc/systemd/system.conf`.
PID 1 sam klepie /dev/watchdog0. **Zero kodu** do napisania.

Bonus: jeśli PID 1 (systemd) padnie, watchdog wybucha → reset SoC.
Ostatnia linia obrony.

### Layered defense - dlaczego nie jedna warstwa

Każda warstwa wykrywa **inną klasę** awarii:

- Go service hang (deadlock, infinite loop) - **A wykrywa**, D nie
  (bo Linux żyje, klepie watchdog, ale aplikacja zawiesiła się)
- Linux kernel panic - **D wykrywa**, A nie (bo systemd też nie żyje)
- M4F infinite loop / death - **Go heartbeat wykrywa** (~9s) → clean reboot
  (`recoverByReboot`). Warstwa B (M4F RTI) to przyszła redundancja.

Warstwy są ortogonalne - razem dają ~95% pokrycia.

### Watchdog MUSI być w setup (nie ad-hoc)

15.06.2026: Warstwa D była skonfigurowana ad-hoc w jednej sesji, ale nie w
`setup.sh`. Po re-flashu karty SD + `setup.sh` watchdog **nie został włączony**
→ silent-hang położył bramkę bez ostatniej linii obrony. Lekcja: każda warstwa
niezawodności musi być w idempotentnym module setup (`modules/05-watchdog.sh`),
inaczej znika przy disaster recovery. To samo dotyczy każdej konfiguracji
robionej "ręcznie na żywo".

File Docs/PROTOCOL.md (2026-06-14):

# Binary Protocol - Linux ↔ M4F Communication

## Cel

Niezawodna komunikacja między userspace na Linux (Go service) a firmware M4F
(NoRTOS) przez RPMsg. Single source of truth: `shared/protocol.h`.

## Wire format

Każda wiadomość ma stałe nagłówki, payload zmiennej długości, CRC16 na końcu:
[1 byte: TYPE] [2 bytes: SEQ] [2 bytes: PAYLOAD_LEN] [N bytes: PAYLOAD] [2 bytes: CRC16]

Wszystkie pola wielobajtowe w **big-endian** (network byte order).
Header struct ma `__attribute__((packed))` — zero padding.
Total overhead: 7 bajtów (5 header + 2 CRC).
Max total message: 487 bajtów (480 payload + 7 overhead).

## CRC16

Polynomial: `0x1021` (CRC16-CCITT, XMODEM variant)
Initial value: `0xFFFF`
Bez reflection, bez xorout.
Pokrywa **header + payload** (nie CRC field).

Test vector: `crc16("123456789") == 0x29B1`.

## Typy wiadomości

| Hex | Nazwa | Kierunek | ACK? | Opis |
|-----|---|---|---|---|
| 0x01 | HELLO | L→M | TAK | Connection request |
| 0x02 | HELLO_ACK | M→L | NIE | Connection accepted |
| 0x03 | PING | Bidir | NIE | Heartbeat probe |
| 0x04 | PONG | Bidir | NIE | Heartbeat reply |
| 0x10 | DATA | Bidir | TAK | Application data |
| 0x11 | ACK | Bidir | NIE | Acknowledge DATA seq=N |
| 0x20 | EVENT | M→L | TAK | Async event from M4F |
| 0xFF | ERROR | Bidir | NIE | Protocol error notification |

## Limity i timeouty

- `MAX_PAYLOAD_SIZE`: 480 bajtów
- `MAX_PENDING_ACKS`: 8 (per direction)
- `MAX_RETRIES`: 3
- `ACK_TIMEOUT_MS`: 1000ms
- `HEARTBEAT_IDLE_MS`: 5000ms (wyślij PING jeśli idle)
- `HEARTBEAT_DEAD_MS`: 15000ms (uznaj connection dead)

## Connection lifecycle
Linux startuje                      M4F już lecący
|                                   |
| --- HELLO(seq=1) -----------►     |
|   "Linux v1 ready"                |
|                                   |
|   ◄---- HELLO_ACK(seq=1) ----     |
|        "M4F v1 ready"             |
|                                   |
| === CONNECTED ===                 |
|                                   |
| --- DATA(seq=2, payload) -----►   |
|   ◄---- ACK(seq=2) ----           |
|                                   |
|   ◄---- EVENT(seq=42, ...) ----   |
| --- ACK(seq=42) -----►            |

## Sequence numbers

- Każda strona ma swój counter (mySeq) - osobny dla TX i RX
- Wrap-around: po 0xFFFF wraca do 0x0001 (0x0000 reserved jako "invalid")
- Idempotency: jeśli RX seq <= lastSeq, ponowny ACK bez re-process

## Smart heartbeat (keepalive on idle)

- Każda wiadomość (DATA, ACK, EVENT, etc.) **resetuje** idle timer
- Jeśli idle > 5s → wyślij PING
- Jeśli idle > 15s (3 missed heartbeats) → mark connection DEAD
- Reconnect: nowy HELLO

## Implementacja

### Single source of truth: `shared/protocol.h`

Plik zawiera:
- Stałe (typy, limity, timeouty)
- `msg_header_t` struct (packed)
- `protocol_crc16()` inline function
- `protocol_encode()` inline function
- `protocol_decode()` inline function
- Big-endian helpers
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

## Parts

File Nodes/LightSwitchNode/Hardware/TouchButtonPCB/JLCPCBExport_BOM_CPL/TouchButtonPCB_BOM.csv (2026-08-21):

Comment | Designator | Footprint | LCSC Part #
0.1uF | C4,C5,C16,C18,C20,C21 | SmartHome:C_0402 | C60474
100pF | C6,C13 | SmartHome:C_0402 | C77177
3pF | C7 | SmartHome:C_0402 | C88891
6.2pF | C8 | SmartHome:C_0402 | C41744
12pF | C9,C14 | SmartHome:C_0402 | C76948
2.7pF | C10 | SmartHome:C_0402 | C76963
3.6pF | C11,C12 | SmartHome:C_0402 | C913745
1uF | C15 | SmartHome:C_0402 | C29266
22uF | C17,C19 | SmartHome:C_0603 | C86295
2.2nF 50V | C25 | SmartHome:C_0402 | C106861
XL-3806SURUBC | D1 | SmartHome:LED-SMD_4P-L3.8-W1.0_XL-3806RGBC-4L | C5349972
BX-PZ2.0-2-3PUW | H1 | SmartHome:HDR-SMD_6P-P2.00-V-M-R2-C3-LS6.5 | C49326165
CC1312R1F3RGZR | IC1 | SmartHome:CC1310_VQFN-48 | C543014
TPD6E004RSER | IC2 | SmartHome:TPD6E004RSER | C1973052
U.FL-R-SMT-1 | JP1 | SmartHome:RF-SMD_FRF05002-JSS103M | C88374
6.8nH | L3,L4 | SmartHome:L_Polarized_0402 | C77110
7.5nH | L5,L7 | SmartHome:L_Polarized_0402 | C98001
27nH | L6 | SmartHome:L_Polarized_0402 | C12669
BLM18HE152SN1D | L8 | SmartHome:L0603 | C82155
MLZ2012N6R8LT000 | L11 | SmartHome:IND-SMD_L2.0-W1.3 | C82157
BC847B_C181140 | Q1,Q2,Q3 | SmartHome:SOT-23-3_L2.9-W1.3-P1.90-LS2.4-TL | C181140
0 | R1,R2 | SmartHome:R_0402 | C106231
220 | R4 | SmartHome:R_0805 | C843981
2k | R5 | SmartHome:R_0402 | C114762
10k | R6 | SmartHome:R_0402 | C60490
20k | R8 | SmartHome:R_0402 | C93942
2k | R9,R10,R11,R12 | SmartHome:R_0402 | C60488
47.5k | R13 | SmartHome:R_0402 | C25896
1.2M | R14 | SmartHome:R_0402 | C60488
48.0000MHZ | U7 | SmartHome:CRYSTAL-SMD_4P-L3.2-W2.5-BL | C6732653
FC-135R | X1 | SmartHome:OSC-SMD_L3.2-W1.5 | C94276

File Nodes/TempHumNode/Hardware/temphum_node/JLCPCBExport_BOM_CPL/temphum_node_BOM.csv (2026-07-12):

Comment | Designator | Footprint | LCSC Part #
2.2nF | C1 | SmartHome:C_0603 | C86023
4.7uF | C2,C23 | SmartHome:C_0603 | C86016
100nF | C3,C27,C28 | SmartHome:C_0402 | C60474
0.1uF | C4,C5,C16,C18,C20,C21 | SmartHome:C_0402 | C60474
100pF | C6,C13 | SmartHome:C_0402 | C77177
3pF | C7 | SmartHome:C_0402 | C88891
6.2pF | C8 | SmartHome:C_0402 | C41744
12pF | C9,C14 | SmartHome:C_0402 | C76948
2.7pF | C10 | SmartHome:C_0402 | C76963
3.6pF | C11,C12 | SmartHome:C_0402 | C913745
1uF | C15 | SmartHome:C_0402 | C29266
22uF | C17,C19,C26 | SmartHome:C_0603 | C86295
100nF | C22 | SmartHome:C_0603 | C1591
10uF | C24 | SmartHome:C_0603 | C91606
2.2nF 50V | C25 | SmartHome:C_0402 | C106861
10nF | C29 | SmartHome:C_0402 | C77019
USBLC6-2SC6 | D1 | SmartHome:SOT-23-6_L2.9-W1.6-P0.95-LS2.8-BL | C7519
RED | D2 | SmartHome:LED0603-RD_RED | C965799
CC1310F128RGZR | IC1 | SmartHome:CC1310_VQFN-48 | C84353
TPD6E004RSER | IC2 | SmartHome:TPD6E004RSER | C1973052
TL3301AF160QG | KEY1 | SmartHome:KEY-SMD_4P-L6.0-W6.0-P4.50-LS10.0 | C273519
8.2nH | L1 | SmartHome:L_Polarized_0402 | C98003
6.8nH | L2,L3,L4 | SmartHome:L_Polarized_0402 | C77110
7.5nH | L5,L7 | SmartHome:L_Polarized_0402 | C98001
27nH | L6 | SmartHome:L_Polarized_0402 | C12669
BLM18HE152SN1D | L8 | SmartHome:L0603 | C82155
DFE252012PD | L10 | SmartHome:L1008 | C237482
MLZ2012N6R8LT000 | L11 | SmartHome:IND-SMD_L2.0-W1.3 | C82157
47,5k | R1 | SmartHome:R_0603 | C23061
5.1k | R2,R6 | SmartHome:R_0603 | C2907044
10k | R3,R4,R5 | SmartHome:R_0603 | C844918
3k | R7 | SmartHome:R_0603 | C2907033
100k | R8 | SmartHome:R_0603 | C2906980
1k | R9 | SmartHome:R_0603 | C2907002
36.5k | R10 | SmartHome:R_0603 | C23029
1M 0.1% | R11,R12 | SmartHome:R_0603 | C4250208
47.5k | R13 | SmartHome:R_0402 | C25896
MCP73123-22SI/MF | U1 | SmartHome:DFN-10_L3.0-W3.0-P0.50-BL-EP | C88544
SHT35-DIS-B | U2 | SmartHome:DFN-8_L2.5-W2.5-P0.50-TL-EP | C90161
TPS22860DBVR | U3,U6 | SmartHome:SOT-23-6_L2.9-W1.6-P0.95-LS2.8-BR | C132005
TPS63900DSKR | U4 | SmartHome:WSON-10_L2.5-W2.5-W0.50-TL-EP | C1518762
MCP3421A0T-E/CH | U5 | SmartHome:SOT-23-6_L2.9-W1.6-P0.95-LS2.8-BR | C29454
ECS-240-9-33B-CWN-TR | U7 | SmartHome:CRYSTAL-SMD_4P-L3.2-W2.5-BL | C2450735
TYPE-C 16PIN 2MD | USB1 | SmartHome:USB-C-SMD_TYPE-C-16PIN-2MD-073 | C2765186
FC-135R | X1 | SmartHome:OSC-SMD_L3.2-W1.5 | C94276

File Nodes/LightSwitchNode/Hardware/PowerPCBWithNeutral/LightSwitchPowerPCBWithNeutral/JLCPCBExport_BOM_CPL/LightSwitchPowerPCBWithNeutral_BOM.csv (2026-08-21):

Comment | Designator | Footprint | LCSC Part #
1uF | C1,C2 | SmartHome:C0805 | C28323
330 | R2,R3 | SmartHome:R1206 | C2078683
TPS7A2033PDBVR | U1 | SmartHome:SOT-23-5_L2.9-W1.6-P0.95-LS2.8-BR | C2862740
IRM-01-5 | U2 | SmartHome:PWRM-TH_L33.7-W22.2_IRM-01-12 | C5656515
BX-PM2.0-2-3PUW | U3 | SmartHome:HDR-SMD_6P-P2.00-V-F-R2-C3-S6.5 | C49326122
MOC3063S-TA1 | U4 | SmartHome:SMD-6_L7.3-W6.5-P2.54-LS10.2-BL | C77950

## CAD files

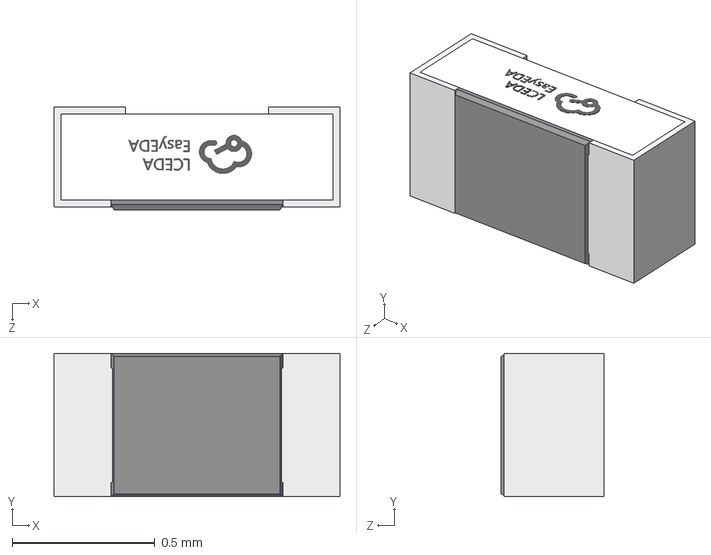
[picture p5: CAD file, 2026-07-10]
Shared/KiCadLib/3dmodels/R0402_L1.0-W0.5-H0.4.step
1.00 x 0.501 x 0.36 mm

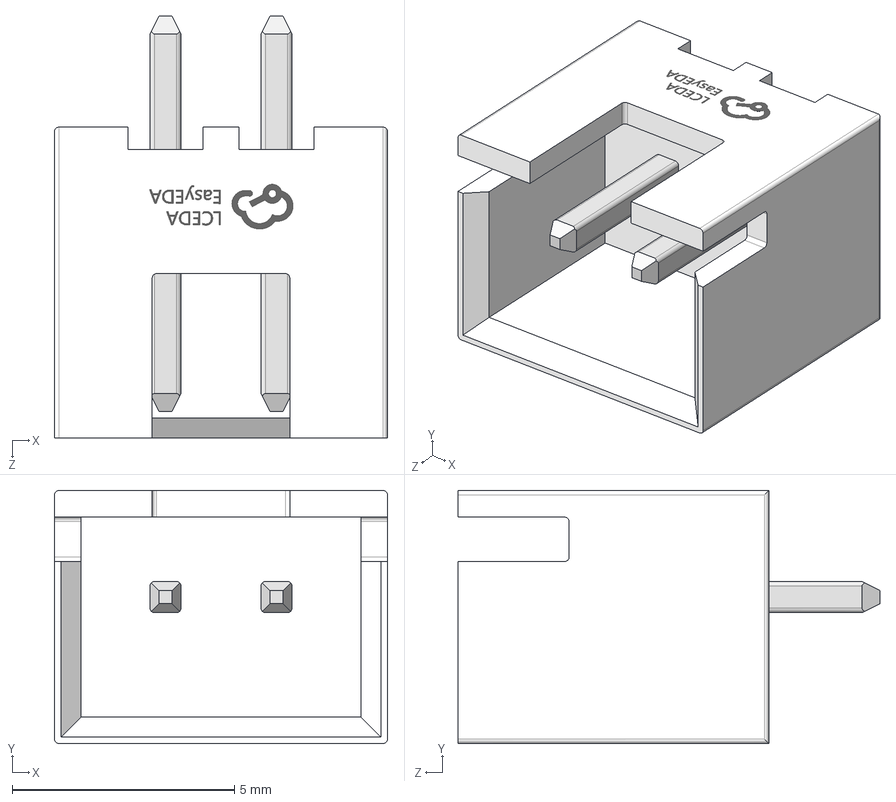
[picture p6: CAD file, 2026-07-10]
Shared/KiCadLib/3dmodels/XH2.5-2A.step
7.50 x 5.70 x 9.50 mm

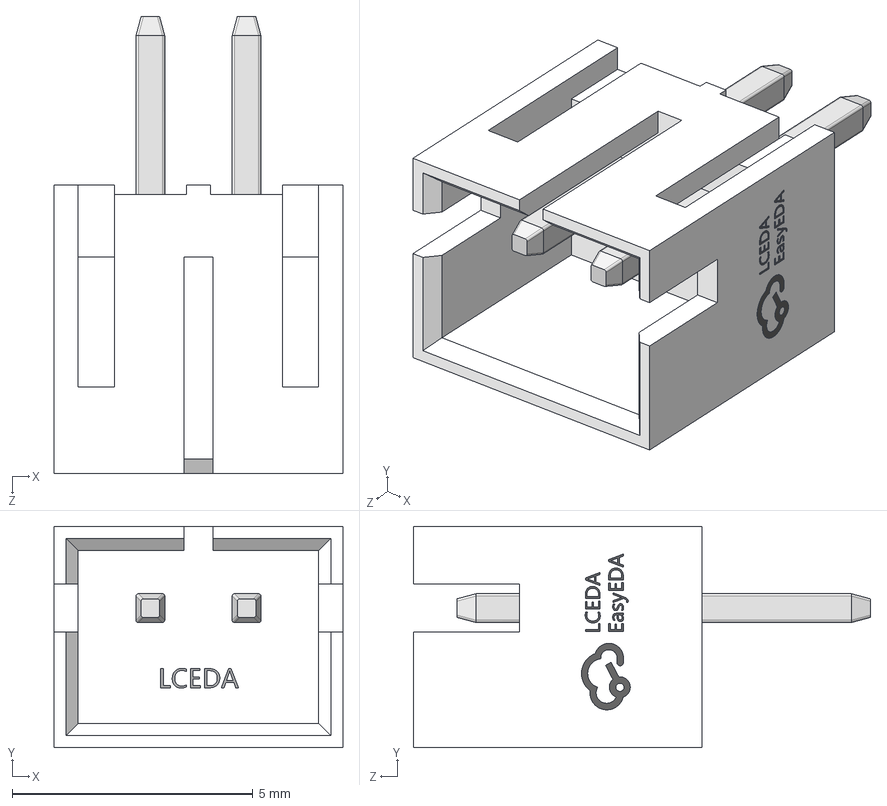
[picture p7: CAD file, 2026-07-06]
Shared/KiCadLib/3dmodels/CONN-TH_PH2.00-LI-2P.step
6.00 x 4.60 x 9.50 mm

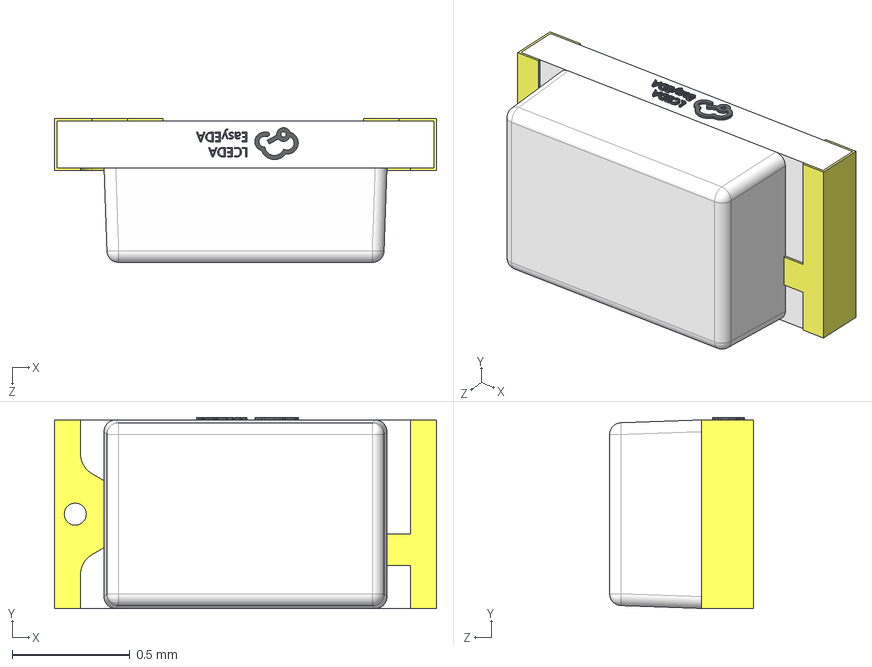
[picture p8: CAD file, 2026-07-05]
Shared/KiCadLib/3dmodels/LED0603-RD_RED.step
1.62 x 0.81 x 0.61 mm

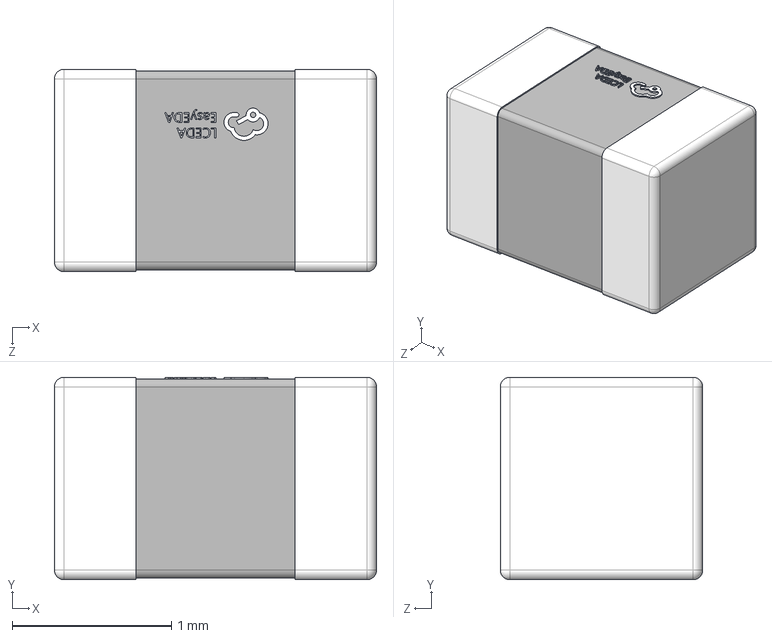
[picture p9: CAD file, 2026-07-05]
Shared/KiCadLib/3dmodels/C0805-SMD_L2.0-W1.25.step
2.02 x 1.27 x 1.27 mm

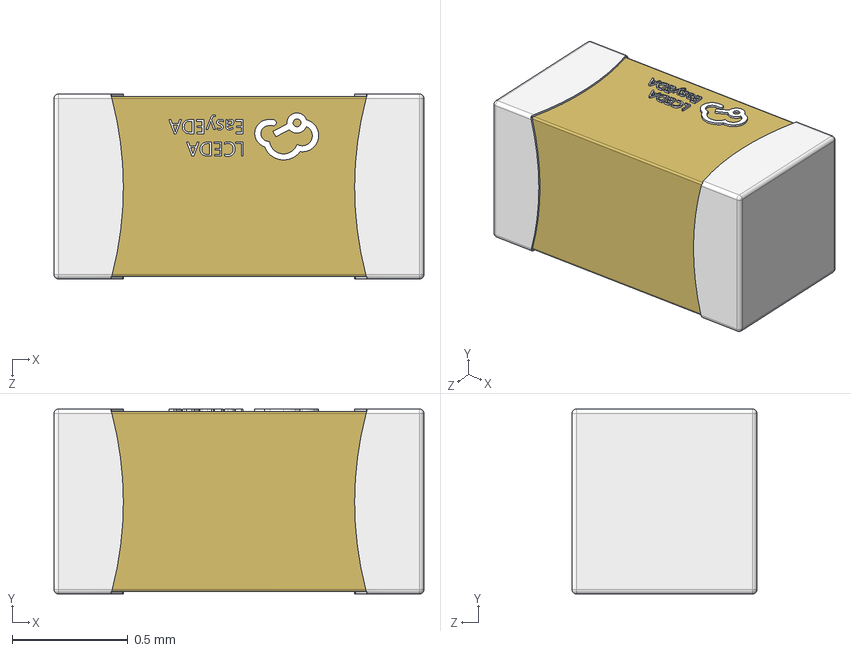
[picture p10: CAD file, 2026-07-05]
Shared/KiCadLib/3dmodels/C0603_L1.6-W0.8-H0.8.step
1.60 x 0.8 x 0.8 mm

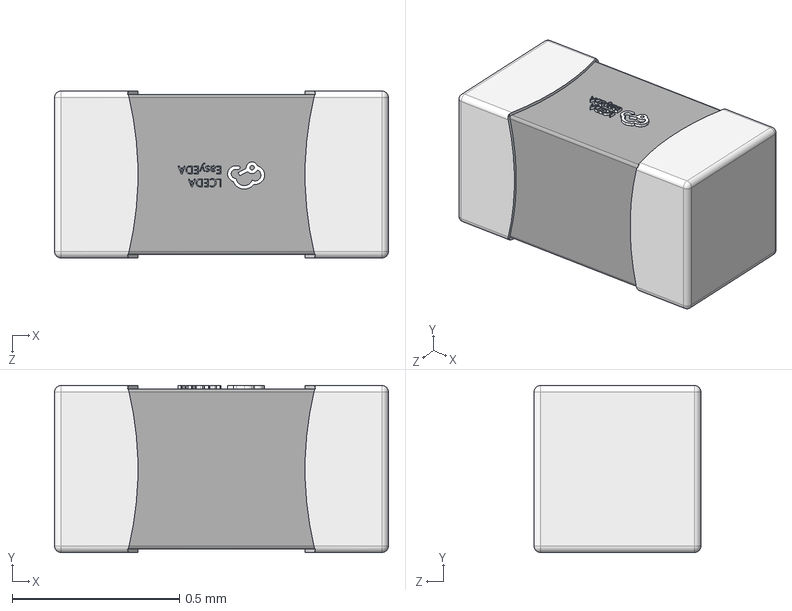
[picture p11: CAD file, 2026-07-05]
Shared/KiCadLib/3dmodels/L0402_L1.0-W0.5-H0.5_BEAD.step
1.00 x 0.5 x 0.5 mm

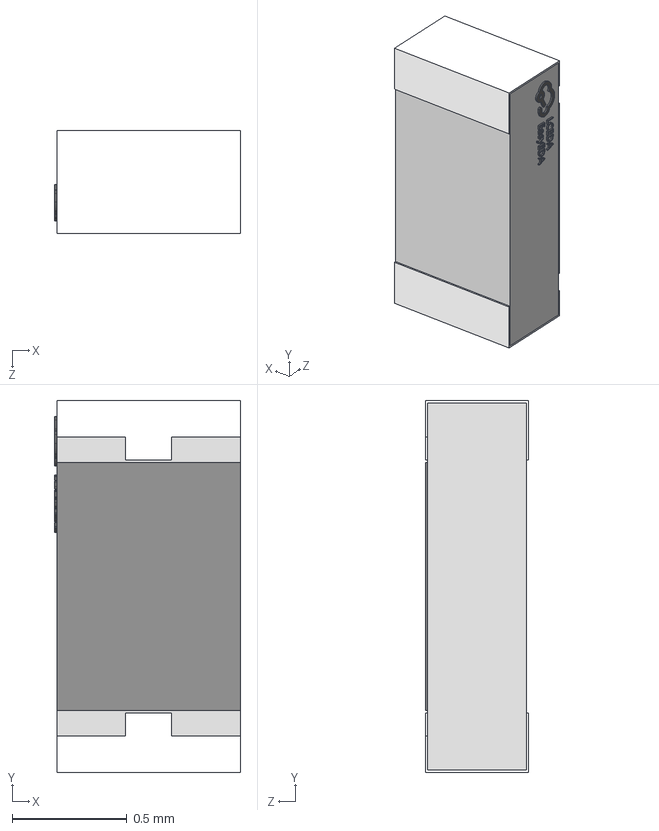
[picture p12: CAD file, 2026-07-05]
Shared/KiCadLib/3dmodels/R0603.step
0.81 x 1.62 x 0.45 mm

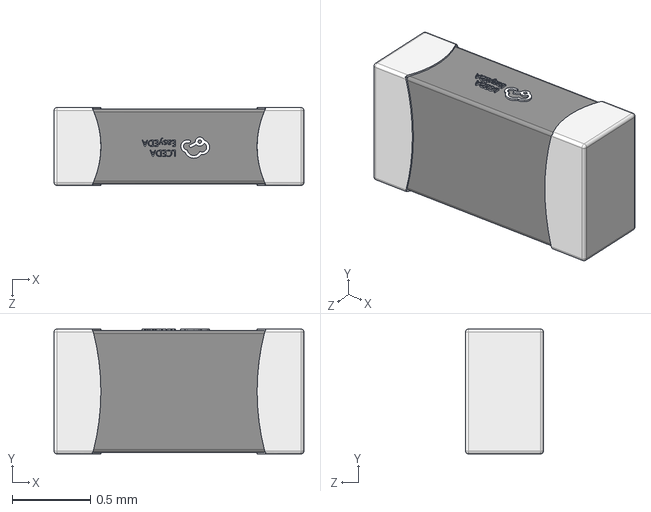
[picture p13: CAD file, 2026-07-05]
Shared/KiCadLib/3dmodels/L0603_L1.6-W0.8-H0.5_BEAD.step
1.60 x 0.8 x 0.5 mm

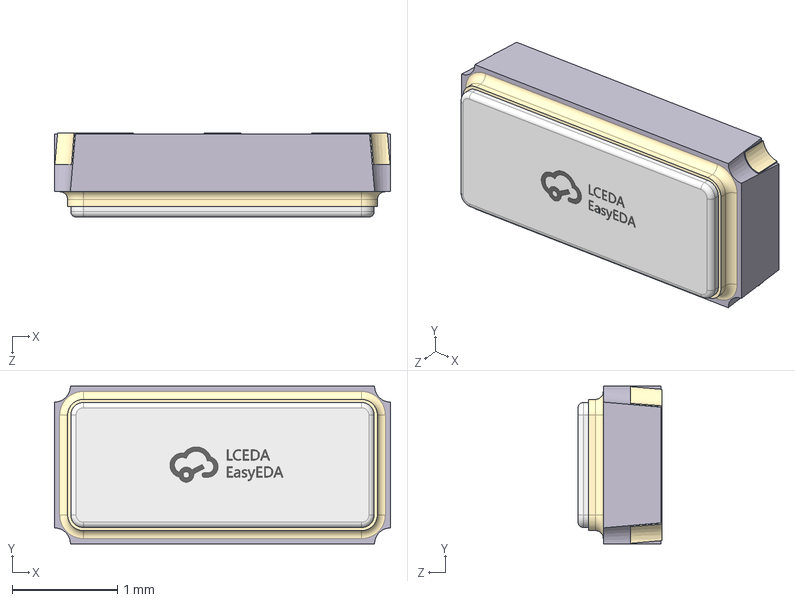
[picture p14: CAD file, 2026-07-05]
Shared/KiCadLib/3dmodels/OSC-SMD_L3.2-W1.5-H0.8.step
3.20 x 1.50 x 0.801 mm

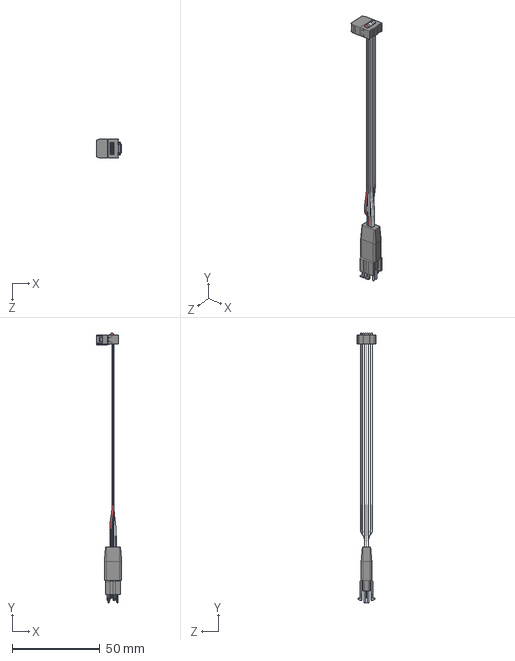
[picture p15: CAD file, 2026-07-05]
Shared/KiCadLib/3dmodels/TC2030-IDC.step
14.5 x 153.6 x 10.7 mm

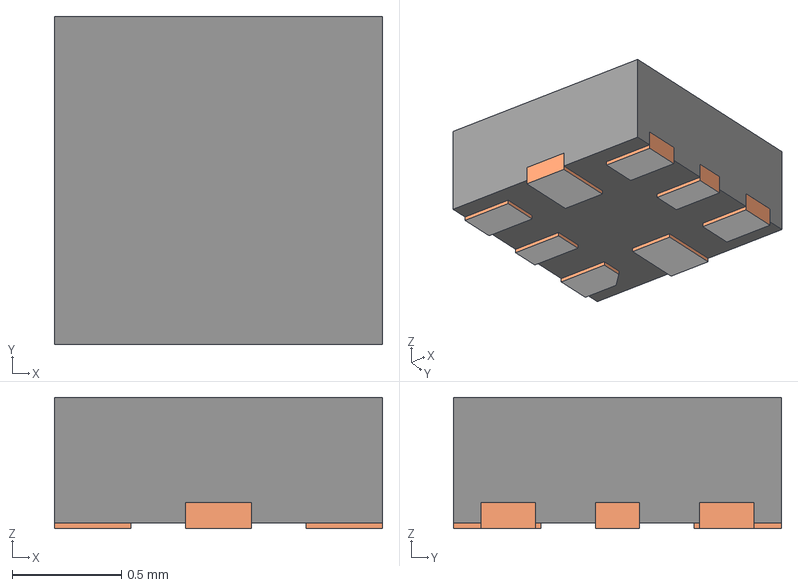
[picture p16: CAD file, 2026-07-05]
Shared/KiCadLib/3dmodels/TPD6E004RSER.stp
1.50 x 1.50 x 0.6 mm
FRAME-RSE0008A
BODY-QFN
PIN1-ID

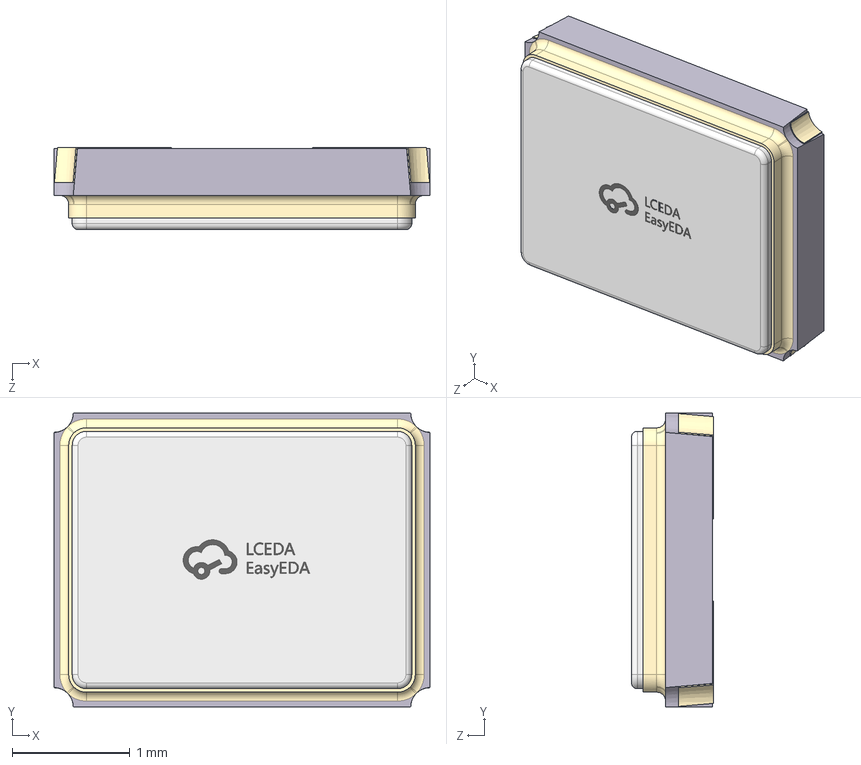
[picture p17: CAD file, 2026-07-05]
Shared/KiCadLib/3dmodels/CRYSTAL-SMD_4P-L3.2-W2.5-BL.step
3.20 x 2.50 x 0.701 mm

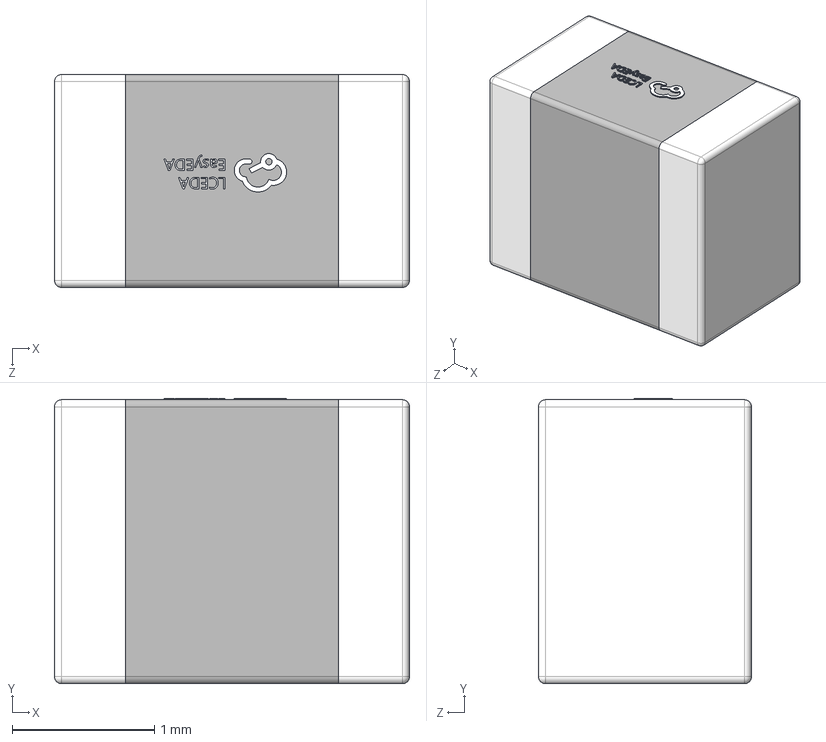
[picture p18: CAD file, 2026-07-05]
Shared/KiCadLib/3dmodels/L1008.step
2.50 x 2.01 x 1.50 mm

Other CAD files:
Shared/KiCadLib/3dmodels/C0805_L2.0-W1.3-H1.3.step
Shared/KiCadLib/3dmodels/C0402_L1.0-W0.5-H0.5.step
Shared/KiCadLib/3dmodels/KEY-SMD_4P-L6.0-W6.0-P4.50-LS10.0.step
Shared/KiCadLib/3dmodels/WSON-10_L2.5-W2.5-W0.50-TL-EP.step
Shared/KiCadLib/3dmodels/CC1310F128RGZR.step
Shared/KiCadLib/3dmodels/DFN-10_L3.0-W3.0-H0.9-P0.50.step
Shared/KiCadLib/3dmodels/DFN-8_L2.5-W2.5-H1.0-P0.50.step
Shared/KiCadLib/3dmodels/SOT-23-6_L2.9-W1.6-H1.5-LS2.8-P0.95.step
Shared/KiCadLib/3dmodels/USB-C-SMD_TYPE-C-6PIN-2MD-073.step

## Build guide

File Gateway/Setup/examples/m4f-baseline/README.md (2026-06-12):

# M4F Baseline Firmware Template

Working M4F firmware showing recommended patterns for AM62 bramka development.

## What this template demonstrates

- **Async RPMsg communication** with Linux via callback pattern (no blocking recv)
- **Autonomous 1Hz tick** showing M4F doing work independently of Linux
- **Command parsing** (`ping`, `status`, generic echo)
- **Graceful shutdown handler** - REQUIRED for hot-reload workflow without reboot
- **Production-quality structure** with separated concerns and clear comments

## How to use this template

### Option A: New project from scratch

1. In CCS Theia, create new project from SDK example `ipc_rpmsg_echo`
2. Select board: `AM62X-SK`, core: `m4fss0-0`, runtime: `noRTOS`
3. Replace the generated `ipc_rpmsg_echo.c` with this file
4. Configure SysConfig (see below)
5. Build (Ctrl+Shift+B)

### Option B: Modify existing project

1. Backup your current `ipc_rpmsg_echo.c` (or whichever file has `main` function)
2. Copy this file content over
3. Adjust application logic in:
   - `handleLinuxMessage()` - command handling
   - `doPeriodicTick()` - your periodic work
   - Add new functions for sensors, control loops, etc.

## Required SysConfig configuration

In `example.syscfg`:

### IPC -> RPMessage with Linux
- Enable: **yes**
- Endpoint: `14` (matches `LINUX_CHRDEV_ENDPOINT` in code)
- Service name: `rpmsg_chrdev`
- Buffer size: `512` bytes
- Number of buffers: `256`

### TI Driver Porting Layer -> Debug Log
Enable these sinks:
- Error Zone ✓
- Warning Zone ✓
- **Info Zone ✓** (REQUIRED - without this, DebugP_log won't appear in trace0)
- Remote Core Trace ✓
- CCS Log ✓ (optional, for JTAG debug)
- UART Log ✓ (optional, MCU_USART0 @ 115200)

## Deploy workflow

After building:

```powershell
# From PowerShell with profile loaded (Deploy-M4F function):
Deploy-M4F
```

Or manually:
```bash
# From bramka SSH session:
m4f-reload [path_to_firmware.out]
```

## Verifying it works

After first deploy, check `/sys/kernel/debug/remoteproc/remoteproc0/trace0` should show:

```
[m4f0-0] 0.004631s : [M4F] Application starting...
[m4f0-0] 0.004868s : [M4F] Waiting for Linux ready...
[m4f0-0] 0.011548s : [M4F] Linux ready!
[m4f0-0] 0.011721s : [M4F] Endpoint 'rpmsg_chrdev' announced on EP 14
[m4f0-0] 0.014700s : [M4F] Shutdown handler registered    <-- key line
[m4f0-0] 0.017733s : [M4F] Ready for messages
[m4f0-0] 1.020837s : [M4F] Tick #1
```

The **"Shutdown handler registered"** line confirms our handler is in place.

Then test commands from Linux:
```bash
rpmsg_char_simple -r 9 -n 3
# Output should include "M4F got: hello there 0!" etc.

# Test ping command (requires consumer process for response):
cat /dev/rpmsg0 &        # background reader
echo -n "ping" > /dev/rpmsg0
# Should see "pong from M4F (tick=N)" in the cat output
```

## Critical test: hot reload without reboot

After flashing this firmware once, try running `Deploy-M4F` 5 times in a row.
**Every deploy should succeed**, no reboot needed between them.

If second deploy fails with `M4F won't stop`, the shutdown handler isn't
working correctly. Check `docs/M4F_SHUTDOWN.md` for diagnostic steps.

## Architecture notes

### Why callback pattern instead of blocking RPMessage_recv

This template uses `RPMessage_construct(...recvCallback...)` with a callback
function. Messages arrive asynchronously and main loop polls a flag.

Alternative pattern (used in SDK example) is blocking `RPMessage_recv` in a
dedicated FreeRTOS task. That requires FreeRTOS overhead. For noRTOS, callbacks
are simpler and more efficient.

### Why M4F sends ticks only to trace, not RPMsg by default

The commented `RPMessage_send` in `doPeriodicTick()` would push tick messages
to Linux every second. Currently commented because:

1. Without a Linux consumer reading `/dev/rpmsg0`, send may block or drop
2. For development, trace0 logs are easier to inspect

When you have a Go service running that consumes the rpmsg channel, uncomment
that block to test true server-push from M4F.

### Why uint8_t for gbShutdownRemotecoreID

To match official SDK example exactly. The cast `(uint8_t)remoteCoreId` in
the callback narrows from uint16_t but core IDs fit in 8 bits (max value
~7 for AM62X family).

### Why DebugP_log uses \r\n not \n

TI's DebugP works with both UART and trace0 sinks. UART terminals expect
CR+LF for proper line break. Just `\n` may render as continuation on same line.

## Extending this template

Common additions:

### Add a sensor sampling task

```c
static void sampleSensors(void)
{
    static uint64_t lastSample = 0;
    uint64_t now = ClockP_getTimeUsec();
    
    /* Sample every 100 ms */
    if ((now - lastSample) >= 100000ULL) {
        lastSample = now;
        /* Read I2C/SPI/ADC sensors here */
        /* Update sensor state */
    }
}
```

Then in main loop:
```c
while (!gbShutdown) {
    if (gRxBuffer.pending) handleLinuxMessage();
    doPeriodicTick();
    sampleSensors();          /* <-- added */
    ClockP_usleep(1000);
}
```

### Add control loop (e.g. PID)

```c
static void runControlLoop(void)
{
    static uint64_t lastIter = 0;
    uint64_t now = ClockP_getTimeUsec();
    
    /* Run control loop at fixed 1 kHz */
    if ((now - lastIter) >= 1000ULL) {
        lastIter = now;
        /* PID iteration here */
        /* Update PWM outputs */
    }
}
```

### Add asynchronous notification to Linux

```c
/* Triggered by sensor reading, alarm, etc. */
static void sendAlarmToLinux(const char *alarm)
{
    int len = strlen(alarm) + 1;
    RPMessage_send(alarm, len,
                   LINUX_CORE_ID, LINUX_CHRDEV_ENDPOINT,
                   RPMessage_getLocalEndPt(&gRecvMsgObject),
                   100);  /* 100 ms timeout */
}
```

Note: requires Linux side to be reading `/dev/rpmsg0` (e.g. via Go service)
otherwise message will be buffered and may block sender.

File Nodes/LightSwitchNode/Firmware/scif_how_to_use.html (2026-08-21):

# Sensor Controller Studio

## SCIF Driver - How to Use

Introduction

This guide describes how to use the Sensor Controller Interface driver (SCIF) generated from the following Sensor Controller project:

- Project name: Capacitive Touch for ULPSENSE
- Project file: C:/SmartHome/Nodes/LightSwitchNode/Firmware/SensorController/CapacitiveTouch.scp
- Operating system: TI-RTOS
- Target chip: CC1312R1F3, package QFN48 7x7 RGZ, revision E (2.1) or F (3.0)

The guide is tailored for this project, and contains code snippets that you can copy and paste directly into your application.

Preparation

Sensor Controller task code cannot be debugged from the application IDE (IAR EWARM or CCS).

Use Task Testing, Task Debugging and/or Run-Time Logging in Sensor Controller Studio to make sure that your Sensor Controller task(s) work as expected, before you start integrating the SCIF driver into the application.

Getting Started

Follow these steps to start integrating the SCIF driver into your application:

- Add the generated SCIF driver to the application project
- Include the SCIF driver header file
- Add callback functions
- Initialize the SCIF driver
- Start Sensor Controller tasks (simplified)
- Access Sensor Controller data structures from the application
- Handle Sensor Controller ALERT interrupts

Further Integration

These sections cover additional SCIF driver features and other information that can be helpful when integrating the SCIF driver:

- Task control
  - Wait for the previous task control operation to finish
  - Start or restart Sensor Controller tasks
  - Stop Sensor Controller tasks
  - Run Sensor Controller tasks once
  - Trigger the execution code block manually
- Trigger an event handler code block manually
- Share I/O pins between the Sensor Controller and the application
- Use project specific definitions in the application
- Uninitialize the SCIF driver
- Run the Sensor Controller Studio code generator in the application pre-build step
- Generate Doxygen documentation for the SCIF driver

Getting Started

This section describes how to add and start integrating the SCIF driver into an existing System CPU application.

It is assumed that all the code snippets below go into one C source file, in the same directory as the SCIF driver. Otherwise you may have to change #include paths, and add function prototypes.

If you do not have an existing application, please take a look at some of the examples in Sensor Controller Studio.

Add the Generated SCIF Driver to the Application Project

You must add these files to your application project:

- scif.c
- scif_framework.c

You can optionally add these files to the application project:

- scif.h
- scif_framework.h
- scif_osal_tirtos.c (this source file is mostly for internal use, and is included by scif_framework.c)
- scif_osal_tirtos.h

IAR EWARM

- Right-click in the project tree
- Click Add -> Add Files ...
- Select the files to be added

CCS

- Right-click on the project in the project tree
- Click Add Files ...
- Select the files to be added
- Select the Link to files option (this allows Sensor Controller Studio to update the SCIF driver files)

Include the SCIF Driver Header File

Add the following code to include the SCIF driver main header file:

#include "scif.h"

Add SCIF Driver Callback Functions

Add these SCIF driver callback functions to the application:

// SCIF driver callback: Task control interface ready (non-blocking task control operation completed)
void scCtrlReadyCallback(void) {

}

// SCIF driver callback: Sensor Controller task code has generated an alert interrupt
void scTaskAlertCallback(void) {

}

Initialize the SCIF Driver

Add the following code to initialize the SCIF driver. You can do this:

- In your application's main() function, immediately before the operating system (RTOS) task scheduler is started
- At the start of an RTOS task, which has a main loop that handles the Sensor Controller:

// Initialize the SCIF operating system abstraction layer
scifOsalInit();
scifOsalRegisterCtrlReadyCallback(scCtrlReadyCallback);
scifOsalRegisterTaskAlertCallback(scTaskAlertCallback);

// Initialize the SCIF driver
scifInit(&scifDriverSetup);

I/O Pin Configuration

The scifInit() call initializes all I/O pins used by the Sensor Controller. Do not configure these I/O pins in the application.

Start Sensor Controller Tasks (Simplified)

The SCIF driver uses the task control interface to start and stop Sensor Controller tasks, and perform other task control operations. The Task Control section describes how to use the task control functions correctly, but for now we will only perform one operation that starts the Sensor Controller task.

To start the "Capacitive Touch" task:

// Start the "Capacitive Touch" Sensor Controller task
scifStartTasksNbl(1 << SCIF_CAPACITIVE_TOUCH_TASK_ID);

Access Sensor Controller Data Structures from the Application

The application can directly access the Sensor Controller's cfg, input, output and state data structures, which are located in the AUX RAM. This is the one and only mechanism for exchanging data between the Sensor Controller and the application.

Resource-specified data structure members should not be accessed directly, but rather through the resource provided API.

Capacitive Touch

The application will typically write to the cfg data structure before the task is started:

scifTaskData.capacitiveTouch.cfg.isrcCurrent = ...;
scifTaskData.capacitiveTouch.cfg.maxSmplPeriod = ...;
scifTaskData.capacitiveTouch.cfg.minSmplPeriod = ...;

The application will typically read from the output data structure while the task is running. You have selected multi-buffered output data exchange with 3 buffers:

// For each available output buffer ...
while (scifGetTaskIoStructAvailCount(SCIF_CAPACITIVE_TOUCH_TASK_ID, SCIF_STRUCT_OUTPUT) > 0) {
    SCIF_CAPACITIVE_TOUCH_OUTPUT_T* pOutput = scifGetTaskStruct(SCIF_CAPACITIVE_TOUCH_TASK_ID, SCIF_STRUCT_OUTPUT);

    // Read output
    ... = pOutput->bvTdcTimeout;
    ... = pOutput->bvTdcValueOverflow;
    for (int n = 0; n < SCIF_CAPACITIVE_TOUCH_PIN_COUNT; n++) {
        ... = pOutput->pBaselineValue[n];
    }
    for (int n = 0; n < SCIF_CAPACITIVE_TOUCH_PIN_COUNT; n++) {
        ... = pOutput->pHighValue[n];
    }
    for (int n = 0; n < SCIF_CAPACITIVE_TOUCH_PIN_COUNT; n++) {
        ... = pOutput->pTdcSmplWindowMean[n];
    }
    for (int n = 0; n < SCIF_CAPACITIVE_TOUCH_PIN_COUNT; n++) {
        ... = pOutput->pTdcValueRaw[n];
    }
    for (int n = 0; n < SCIF_CAPACITIVE_TOUCH_PIN_COUNT; n++) {
        ... = pOutput->pThresValue[n];
    }
    for (int n = 0; n < SCIF_CAPACITIVE_TOUCH_PIN_COUNT; n++) {
        ... = pOutput->pTouchDet[n];
    }

    // Hand the buffer back to the Sensor Controller
    scifHandoffTaskStruct(SCIF_CAPACITIVE_TOUCH_TASK_ID, SCIF_STRUCT_OUTPUT);
}

The state data structure is normally for internal use by the Sensor Controller, but can also be used for data exchange during operation or for observation:

... = scifTaskData.capacitiveTouch.state.bvTdcTimeout;
... = scifTaskData.capacitiveTouch.state.bvTdcValueOverflow;
... = scifTaskData.capacitiveTouch.state.genOutput;
for (int n = 0; n < SCIF_CAPACITIVE_TOUCH_PIN_COUNT; n++) {
    ... = scifTaskData.capacitiveTouch.state.pBaselineValue[n];
}
for (int n = 0; n < SCIF_CAPACITIVE_TOUCH_PIN_COUNT; n++) {
    ... = scifTaskData.capacitiveTouch.state.pHighValue[n];
}
for (int n = 0; n < SCIF_CAPACITIVE_TOUCH_PIN_COUNT; n++) {
    ... = scifTaskData.capacitiveTouch.state.pLowMeanIirFilter[n];
}
for (int n = 0; n < SCIF_CAPACITIVE_TOUCH_LOW_MEAN_WINDOW_TOTAL; n++) {
    ... = scifTaskData.capacitiveTouch.state.pLowMeanWindow[n];
}
for (int n = 0; n < SCIF_CAPACITIVE_TOUCH_PIN_COUNT; n++) {
    ... = scifTaskData.capacitiveTouch.state.pTdcSmplLowCount[n];
}
for (int n = 0; n < SCIF_CAPACITIVE_TOUCH_TDC_SMPL_WINDOW_TOTAL; n++) {
    ... = scifTaskData.capacitiveTouch.state.pTdcSmplWindow[n];
}
for (int n = 0; n < SCIF_CAPACITIVE_TOUCH_PIN_COUNT; n++) {
    ... = scifTaskData.capacitiveTouch.state.pTdcTimeoutCount[n];
}
for (int n = 0; n < SCIF_CAPACITIVE_TOUCH_PIN_COUNT; n++) {
    ... = scifTaskData.capacitiveTouch.state.pTouchDet[n];
}
for (int n = 0; n < SCIF_CAPACITIVE_TOUCH_PIN_COUNT; n++) {
    ... = scifTaskData.capacitiveTouch.state.pTouchHoldCount[n];
}
... = scifTaskData.capacitiveTouch.state.smplPeriod;
... = scifTaskData.capacitiveTouch.state.startupIterCount;

scifTaskData.capacitiveTouch.state.bvTdcTimeout = ...;
scifTaskData.capacitiveTouch.state.bvTdcValueOverflow = ...;
scifTaskData.capacitiveTouch.state.genOutput = ...;
for (int n = 0; n < SCIF_CAPACITIVE_TOUCH_PIN_COUNT; n++) {
    scifTaskData.capacitiveTouch.state.pBaselineValue[n] = ...;
}
for (int n = 0; n < SCIF_CAPACITIVE_TOUCH_PIN_COUNT; n++) {
    scifTaskData.capacitiveTouch.state.pHighValue[n] = ...;
}
for (int n = 0; n < SCIF_CAPACITIVE_TOUCH_PIN_COUNT; n++) {
    scifTaskData.capacitiveTouch.state.pLowMeanIirFilter[n] = ...;
}
for (int n = 0; n < SCIF_CAPACITIVE_TOUCH_LOW_MEAN_WINDOW_TOTAL; n++) {
    scifTaskData.capacitiveTouch.state.pLowMeanWindow[n] = ...;
}
for (int n = 0; n < SCIF_CAPACITIVE_TOUCH_PIN_COUNT; n++) {
    scifTaskData.capacitiveTouch.state.pTdcSmplLowCount[n] = ...;
}
for (int n = 0; n < SCIF_CAPACITIVE_TOUCH_TDC_SMPL_WINDOW_TOTAL; n++) {
    scifTaskData.capacitiveTouch.state.pTdcSmplWindow[n] = ...;
}
for (int n = 0; n < SCIF_CAPACITIVE_TOUCH_PIN_COUNT; n++) {
    scifTaskData.capacitiveTouch.state.pTdcTimeoutCount[n] = ...;
}
for (int n = 0; n < SCIF_CAPACITIVE_TOUCH_PIN_COUNT; n++) {
    scifTaskData.capacitiveTouch.state.pTouchDet[n] = ...;
}
for (int n = 0; n < SCIF_CAPACITIVE_TOUCH_PIN_COUNT; n++) {
    scifTaskData.capacitiveTouch.state.pTouchHoldCount[n] = ...;
}
scifTaskData.capacitiveTouch.state.smplPeriod = ...;
scifTaskData.capacitiveTouch.state.startupIterCount = ...;

Handle Sensor Controller ALERT interrupts

You can handle Sensor Controller ALERT events at any desired priority level, for example:

- In interrupt context, that is, in scTaskAlertCallback()
- In RTOS task context, using scTaskAlertCallback() to unblock the task by posting a semaphore or similar

// Clear the ALERT interrupt source
scifClearAlertIntSource();

... Access Sensor Controller task data structures here ...

// Acknowledge the ALERT event
scifAckAlertEvents();

Further Integration

This section describes task control in more detail, additional SCIF driver features, and other useful information.

Task Control

Task control operations are used to start and stop Sensor Controller tasks, and to trigger manual execution of task code blocks.

The task control interface can perform one operation at a time, and it is busy until the Sensor Controller has completed the operation. The task control functions are, however, non-blocking (hence the Nbl suffix), and return immediately. This means that you must wait for each task control operation to finish before performing another operation.

You can wait either before or after each task control operation. Normally it makes sense to wait before each operation since this reduces the waiting time. If your application performs task control from multiple threads of execution, you must ensure that this is done atomically:

1. Enter critical section
2. Wait for the previous task control operation to finish
3. Perform task control operation, for example start Sensor Controller tasks
4. Leave critical section

Wait for the Previous Task Control Operation to Finish

This code waits until the previous task control operation has finished, with a timeout in microseconds. The timeout is application specific. The function returns immediately if task control interface already is ready.

// Wait with 20 millisecond timeout
if (scifWaitOnNbl(20000) != SCIF_SUCCESS) {
    ... Handle timeout or usage error (see the function documentation) ...
} else {
    ... Perform the next task control operation, for example start Sensor Controller tasks ...
}

Start or Restart Sensor Controller Tasks

Starting a Sensor Controller task triggers the Initialization code. The task is then active.

After a Sensor Controller task has been stopped (see below), you must reset the task's data structures before it can be restarted. The scifResetTaskStructs() function will always reset the state data structure. You can optionally also reset the cfg, input and output data structures.

Do the following to (re)start a Sensor Controller task:

- To start or restart the "Capacitive Touch" task:

// Reset all data structures except configuration
scifResetTaskStructs(1 << SCIF_CAPACITIVE_TOUCH_TASK_ID, (1 << SCIF_STRUCT_INPUT) | (1 << SCIF_STRUCT_OUTPUT));

// (Re)start the "Capacitive Touch" Sensor Controller task
if (scifWaitOnNbl(20000) != SCIF_SUCCESS) {
    ... Handle timeout or usage error ...
} else if (scifStartTasksNbl(1 << SCIF_CAPACITIVE_TOUCH_TASK_ID) != SCIF_SUCCESS) {
    ... Handle usage error ...
}

Stop Sensor Controller Tasks

Stopping a Sensor Controller task triggers the Termination code. The task is then inactive.

Do the following to stop a Sensor Controller task:

- To stop the "Capacitive Touch" task:

// Stop the "Capacitive Touch" Sensor Controller task
if (scifWaitOnNbl(20000) != SCIF_SUCCESS) {
    ... Handle timeout or usage error ...
} else if (scifStopTasksNbl(1 << SCIF_CAPACITIVE_TOUCH_TASK_ID) != SCIF_SUCCESS) {
    ... Handle usage error ...
}

Run Sensor Controller Tasks Once

Running a Sensor Controller task once triggers the Initialization Code, the Execution Code (one time), and the Termination Code.

Do the following to run a Sensor Controller task once:

- To run the "Capacitive Touch" task:

// Run the "Capacitive Touch" Sensor Controller task
if (scifWaitOnNbl(20000) != SCIF_SUCCESS) {
    ... Handle timeout or usage error ...
} else if (scifExecuteTasksOnceNbl(1 << SCIF_CAPACITIVE_TOUCH_TASK_ID) != SCIF_SUCCESS) {
    ... Handle usage error ...
}

Trigger the Execution Code Block Manually

For an active task, it is possible to trigger the Execution Code manually.

Do the following to trigger a single iteration of the Execution Code:

- To run the "Capacitive Touch" task's Execution Code:

// Run the "Capacitive Touch" Execution Code
if (scifWaitOnNbl(20000) != SCIF_SUCCESS) {
    ... Handle timeout or usage error ...
} else if (scifSwTriggerExecutionCodeNbl(1 << SCIF_CAPACITIVE_TOUCH_TASK_ID) != SCIF_SUCCESS) {
    ... Handle usage error ...
}

Trigger an Event Handler Code Block Manually

For an active task, it is possible to trigger the Event Handler Code manually.

This code generates event trigger index 0 for task Capacitive Touch:

// Generate the event trigger 0 for Capacitive Touch
if (scifSwTriggerEventHandlerCode(SCIF_CAPACITIVE_TOUCH_TASK_ID, 0) != SCIF_SUCCESS) {
    ... Handle usage error (see below) ...
}

Note that this does not use the task control interface. The scifSwTriggerEventHandlerCode() call triggers code on the Sensor Controller that generates the event trigger. The function fails with return value SCIF_NOT_READY if called again before the last scifSwTriggerEventHandlerCode() operation has finished on the Sensor Controller.

Share I/O Pins Between the Sensor Controller and the Application

In some applications you may want to transfer ownership of I/O pins between the Sensor Controller and MCU domain peripherals, for example when:

- The Sensor Controller and the application need to access different I2C devices over the same SCL and SDA lines
- The Sensor Controller and the application need to access different SPI devices over the same SCLK, MOSI and MISO lines, but with different chip select pins

To transfer I/O pins from Sensor Controller task(s) to the application:

- Stop the Sensor Controller task(s) that are currently using the I/O pins
- You can now open the TI driver(s) that require the I/O pins. An additional step is required for regular GPIO functions:
  - For the TI GPIO driver: The I/O pins transferred from the Sensor Controller will be mapped to the AUX domain I/O controller, and must be reconfigured before the application uses them through the GPIO hardware module. Call GPIO_resetConfig() or GPIO_setConfig() to map each I/O pin back to the MCU domain I/O controller and the GPIO hardware module.
  - For the TI PIN driver: The PIN driver assumes that closed I/O pins are mapped to the GPIO hardware module, but the I/O pins transferred from the Sensor Controller will instead be mapped to the AUX domain I/O controller. Add the following code after the I/O pin(s) have been opened with the PIN driver:

// For each I/O pin:
PINCC26XX_setMux(pinHandle, pin, PINCC26XX_MUX_GPIO);

To transfer I/O pins from the application back to Sensor Controller tasks:

- Close the TI driver(s) that are currently using the I/O pins
- Move I/O pin ownership back to the Sensor Controller task(s):
  - For the Capacitive Touch task, call:

scifReinitTaskIo(1 << SCIF_CAPACITIVE_TOUCH_TASK_ID);
- You can now restart the Sensor Controller task(s)

Use Project Specific Definitions in the Application

The SCIF Driver provides these definitions for use in the application:

- Target chip identification
  - SCIF_TARGET_CHIP_NAME_CC1312R1F3 (no value)
  - SCIF_TARGET_CHIP_PACKAGE_QFN48_7X7_RGZ (no value)
- Number of tasks
  - SCIF_TASK_COUNT
- Task IDs
  - SCIF_CAPACITIVE_TOUCH_TASK_ID
- User-specified constants
  - SCIF_CAPACITIVE_TOUCH_BASELINE_UPDATE_PERIOD
  - SCIF_CAPACITIVE_TOUCH_D_ISRC_CURRENT
  - SCIF_CAPACITIVE_TOUCH_D_MAX_SMPL_PERIOD
  - SCIF_CAPACITIVE_TOUCH_D_MIN_SMPL_PERIOD
  - SCIF_CAPACITIVE_TOUCH_LOW_MEAN_IIR_DIV_EXP
  - SCIF_CAPACITIVE_TOUCH_LOW_MEAN_IIR_UPDATE_PERIOD
  - SCIF_CAPACITIVE_TOUCH_LOW_MEAN_WINDOW_EXP
  - SCIF_CAPACITIVE_TOUCH_LOW_MEAN_WINDOW_SIZE
  - SCIF_CAPACITIVE_TOUCH_LOW_MEAN_WINDOW_TOTAL
  - SCIF_CAPACITIVE_TOUCH_MAX_TDC_TIMEOUTS
  - SCIF_CAPACITIVE_TOUCH_MAX_TOUCH_ITERATIONS
  - SCIF_CAPACITIVE_TOUCH_PIN_COUNT
  - SCIF_CAPACITIVE_TOUCH_TDC_SMPL_WINDOW_EXP
  - SCIF_CAPACITIVE_TOUCH_TDC_SMPL_WINDOW_SIZE
  - SCIF_CAPACITIVE_TOUCH_TDC_SMPL_WINDOW_TOTAL
  - SCIF_CAPACITIVE_TOUCH_TOUCH_DETECT_OFFSET
  - SCIF_CAPACITIVE_TOUCH_TOUCH_RELEASE_OFFSET
- I/O mapping
  - SCIF_CAPACITIVE_TOUCH_DIO_AXD_CAP_TOUCH
  - SCIF_CAPACITIVE_TOUCH_DIO_AXS_CAP_TOUCH_REF

Uninitialize the SCIF Driver

It is possible to include multiple SCIF driver setups (that is, outputs from multiple Sensor Controller projects) in one application.

To switch driver setup, first stop using and uninitialize this SCIF driver:

// Stop all Sensor Controller tasks
if (scifWaitOnNbl(20000) != SCIF_SUCCESS) {
    ... Handle error...
} else if (scifStopTasksNbl((1 << SCIF_CAPACITIVE_TOUCH_TASK_ID)) != SCIF_SUCCESS) {
    ... Handle error...
} else if (scifWaitOnNbl(20000) != SCIF_SUCCESS) {
    ... Handle error...

} else {
    // All tasks have been stopped successfully

    // Uninitialize the SCIF driver (includes I/O configuration)
    scifUninit();
}

Then initialize the other SCIF driver, as described in its "How to Use" guide.

I/O Pin Configuration

The scifUninit() call uninitializes all Sensor Controller I/O pins. The I/O pins will be reverted to regular GPIO inputs, with pull as configured in the Sensor Controller Studio task panel(s).

Run Sensor Controller Studio Code Generator During Application Pre-Build Step

Use the Sensor Controller Studio command line interface (CLI) to ensure that the generated SCIF driver is up-to-date.

The -s parameter prevents file output when existing files already are up-to-date.

IAR EWARM

- Right-click on the project in the project tree
- Click Options...
- Select Build Actions
- Add the following to the pre-build step (you may need to create a batch file if you have multiple pre-build steps):

"C:\Program Files (x86)\Texas Instruments\Sensor Controller Studio\bin\sensor_controller_studio_cli.exe" -g "C:/SmartHome/Nodes/LightSwitchNode/Firmware/SensorController/CapacitiveTouch.scp" -s -q

CCS

- Right-click on the project in the project tree
- Click Options...
- Select Build
- Add the following to the pre-build steps:

"C:/Program Files (x86)/Texas Instruments/Sensor Controller Studio/bin/sensor_controller_studio_cli.exe" -g "C:/SmartHome/Nodes/LightSwitchNode/Firmware/SensorController/CapacitiveTouch.scp" -s -q

Generate Doxygen HTML Documentation for the SCIF Driver

Doxygen generates HTML documentation based on specially formatted comments in source code. Download Doxygen from http://www.doxygen.org/.

Set the path to doxygen.exe in the Preferences panel if needed. The current path is C:/Program Files/doxygen/bin/doxygen.exe.

To create or update the HTML documentation, run scif_run_doxygen.bat. The generated documentation can then be found here: scif_dox/index.html

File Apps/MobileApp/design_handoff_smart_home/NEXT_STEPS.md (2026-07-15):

# Notatka — plan i stan projektu

## Stan aktualny (najnowsza sesja) — wersja rozwijana dalej
Motyw **ciepły** ustalony jako główny (plik `Smart Home App.dc.html`):
- **Baza:** grafit `#201B13` = chrome (FAB, przycisk „Zapisz"), krem/biel = tła.
- **Pomarańcz `#E1850B`** używany oszczędnie tam, gdzie pasuje: aktywna pigułka nawigacji (lekki `#FDECCB`), aktywne segmenty tab-view (biała uniesiona pastylka z cieniem na ciemniejszym torze `#E8E1D4`), segmenty ON/OFF.
- **Zielony `#2E9E6B`** = przełączniki włącz/wyłącz + status online.
- **Kolor = typ urządzenia** (semantyczny akcent na kartach, pigułkach warunków/akcji).
- FAB grafitowy (pomarańczowy zbyt raził); „Zapisz" zawsze grafitowy; tab-view nie na wypełniony pomarańcz, tylko biała pastylka z cieniem.

### Dashboard
- Usunięte szybkie karty Światła/Rolety. Kolejność: najpierw **Bez pokoju** (System solarny, Czujnik klimatu, Fotowoltaika), potem **Pokoje**.
- Karta System solarny pod linią: **71,2°C Kolektor** (Tcol), **73,2°C Zbiornik główny** (T4), **62,3°C Zbiornik dodatkowy** (sBuforTemp).
- Fotowoltaika = pełna **czerwona** karta (bez czarnego tła), jako 3. w „Bez pokoju".

### Automatyzacje — karty reguł i podgląd
- Reguła czytana jako: **JEŚLI** + pigułki warunków (Czas = neutralny szary; parametr/delta = kolor urządzenia źródłowego) rozdzielone **„ORAZ"**, potem **TO** + pigułka akcji w kolorze urządzenia docelowego („Urządzenie · Przekaźnik ON/OFF").
- Podgląd reguły w edytorze używa tej samej konwencji pigułek (jasna karta, oś JEŚLI→TO).

## Warianty kolorystyczne (kopie w projekcie)
- `Smart Home App (pomarancz).dc.html` — pełny pomarańcz na akcentach chrome.
- `Smart Home App (turkus).dc.html` — turkus.
- `Smart Home App (grafit).dc.html` — czysta baza grafitowa (przed motywem ciepłym).
Zmiana motywu = podmiana jednej stałej koloru w skrypcie (proste).

## Do zrobienia dalej
- Ewentualne dostrojenie palety typów urządzeń (solar vs bufor mają zbliżony ciepły odcień — rozważyć mocniejsze rozróżnienie).
- Kolejne typy akcji automatyzacji (na razie tylko „Ustaw przekaźnik ON/OFF") i warunków — model jest rozszerzalny (`A_DEVICES`, `A_PARAMS`, `A_COLORS`, `DEV_TYPES`).

## Zrobione wcześniej
- **Stany puste** — Automatyzacje (ikona + tekst + „Nowa automatyzacja"); Urządzenia (brak urządzeń → podpowiedź JOIN; pusty filtr pokoju → „Pokaż wszystkie").
- **Potwierdzanie usuwania** — wspólny dialog (backdrop + karta) dla reguł i urządzeń.
- Ekrany: Dashboard, Czujnik klimatu (motyw turkus), System solarny (motyw pomarańcz, schemat instalacji + wykresy), Automatyzacje (lista + edytor + walidacja + podgląd + synchronizacja z bramką/offline), Menadżer urządzeń (JOIN, pokoje).

## Nazewnictwo
Pełnoekranowy kolorowy ekran urządzenia = „motyw urządzenia / color-flooded surface" (NIE „hero").

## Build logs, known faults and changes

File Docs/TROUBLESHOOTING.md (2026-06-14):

# Troubleshooting

Real issues encountered during AM62 bramka development, with diagnosis and fixes.

## Network / SSH issues

### MAC address changes on every boot (DHCP reservation broken)

**Symptom**: Router gives different IP each boot despite DHCP reservation.

**Cause**: AM62 SK board has no EEPROM at I2C 0x50/0x51, so kernel generates
random MAC on each boot (see dmesg: `EEPROM not available at 0x50`).

**Fix**: Persistent MAC via systemd-networkd `.link` unit (done by `01-network.sh`).
Match by hardware path, not interface name (which can be unstable):

```ini
[Match]
Path=platform-8000000.ethernet
OriginalName=eth*

[Link]
MACAddressPolicy=none
MACAddress=22:F4:99:37:A5:12
NamePolicy=
Name=eth1
```

After applying, reboot and verify with `ip link show eth1`.

### SSH connection refused after fresh image

**Symptom**: `ssh root@<ip>` fails with "Connection refused".

**Cause**: SSH daemon not running yet, or empty root password disabled.

**Fix** via UART console:
```bash
systemctl status sshd
systemctl enable sshd
systemctl start sshd
# If still refused: passwd root, then set a password
```

## M4F development issues

### `echo stop > .../state` returns "Device or resource busy"

**Symptom**:
```
-sh: echo: write error: Device or resource busy
```

dmesg shows:
```
k3-m4-rproc 5000000.m4fss: notify_shutdown_rproc: timeout waiting for rproc completion event
remoteproc remoteproc0: can't stop rproc: -16
```

**Cause**: M4F firmware lacks graceful shutdown handler. Linux sends shutdown
notification, waits 10s for ACK, times out.

**Fix**: Add shutdown handler to firmware code. See `docs/M4F_SHUTDOWN.md`
for complete implementation.

**Temporary workaround** (forces reboot but doesn't break remoteproc numbering):
```bash
# Disable auto-load on next boot:
mv /lib/firmware/ti-ipc/am62xx/ipc_echo_test_mcu2_0_release_strip.xer5f /tmp/fw_bak.out
sync && reboot
# After reboot, M4F is 'offline' - then m4f-reload works for first deploy
```

### After unbind/bind, M4F is at remoteproc4 instead of remoteproc0

**Symptom**: All scripts hardcoding `remoteproc0` break. `ls /sys/class/remoteproc/`
shows `remoteproc1, 2, 3, 4` with M4F at `remoteproc4`.

**Cause**: Linux remoteproc never reuses numbers after unbind. Each bind
creates a new entry with the next available number.

**Fix**: Reboot. This restores deterministic device tree enumeration order
(M4F always at remoteproc0 after fresh boot).

**Prevention**: Don't use unbind/bind. Use `m4f-reload` which relies on
proper graceful shutdown.

### M4F shutdown handler sends ACK but Linux still times out

**Symptom**: trace0 shows shutdown was handled by M4F:
```
[M4F] Shutdown requested by core 0
[M4F] Shutdown ACK sent to Linux, going to WFI
```

But Linux dmesg shows:
```
notify_shutdown_rproc: timeout waiting for rproc completion event
```

**Cause**: Wrong order of operations in shutdown sequence. ACK was sent
BEFORE `System_deinit()`, but SDK requires it AFTER.

**Fix**: Correct order is `Drivers_close()` → `System_deinit()` → `IpcNotify_sendMsg(ACK)` → WFI.
See `docs/M4F_SHUTDOWN.md` for details.

## Linux watch / log issues

### `tail -f trace0` doesn't show new entries

**Symptom**: `tail -f /sys/kernel/debug/remoteproc/remoteproc0/trace0` displays
existing buffer but never shows new lines as M4F logs them.

**Cause**: `trace0` is a debugfs file, not a regular file:
1. No inotify support - `tail -f` watches for filesystem events that never fire
2. Circular buffer in shared memory - `tail` optimizes by seeking to end and
   reading back, which doesn't work on debugfs (returns garbage)

**Fix**: Use the `m4f-watch` script (installed by `02-tools.sh`) which uses
smart polling with deduplication based on microsecond timestamps extracted
from log lines.

### Trace buffer shows old entries mixed with new (circular wrap)

**Symptom**: After running for a long time, `cat trace0` shows entries with
timestamps that don't go in order - some old, some new, intermixed.

**Cause**: Trace buffer is a fixed 4KB circular buffer (~96 entries).
When full, new writes overwrite oldest entries. Physical position in file
doesn't match logical time order.

**Fix**: `m4f-watch` script extracts timestamps and sorts numerically,
showing only entries newer than last shown. Buffer wrap is handled correctly.

To get longer history, increase trace buffer in M4F SysConfig:
`TI Driver Porting Layer -> Debug Log -> Memory Log Size` (default 4096,
try 16384 for ~6 minutes history at 1 tick/sec).

## Build / firmware issues

### CCS Theia warns about SysConfig version mismatch

**Symptom**:
```
Product SysConfig v1.26.2 is not currently installed.
A compatible version 1.27.1 will be used.
```

**Cause**: SDK was tested with v1.26.2, but CCS Theia ships with v1.27.1.
The "compatible" path uses newer version which works in most cases.

**Fix** (optional): Install matching version via CCS Help -> Manage Packages -> SysConfig.

For now, this is a warning, not an error - builds should still work.

### Firmware loads but no logs appear in trace0

**Symptom**: `cat /sys/class/remoteproc/remoteproc0/state` shows `running`
but `cat /sys/kernel/debug/remoteproc/remoteproc0/trace0` is empty.

**Cause**: SysConfig log configuration missing "Info Zone" enable.

**Fix**: In SysConfig:
1. Open `example.syscfg`
2. Navigate to `TI Driver Porting Layer -> Debug Log`
3. Enable Sinks: Error Zone ✓, Warning Zone ✓, **Info Zone ✓** (required!),
   Remote Core Trace ✓, CCS Log ✓
4. Save, rebuild, redeploy

## SD card / image issues

### Etcher fails to flash image (corrupted)

**Symptom**: Etcher hangs at "Decompressing" or flashes but card doesn't boot.

**Cause**: Etcher has known bugs with streaming `.xz` decompression on
large images.

**Fix**: Manually decompress before flashing:
1. Extract `tisdk-default-image-am62xx-evm.wic.xz` with 7-Zip or WinRAR
2. Get `.wic` file
3. Flash that with Etcher

### Card boots but partitions are tiny

**Symptom**: After boot, `df -h /` shows rootfs ~150MB but card is 64GB.

**Cause**: First-boot resize hasn't run yet, or `growpart` is missing.

**Fix**: TI Arago Linux includes `cloud-init`-style first-boot resize.
After first reboot, partition should fill the card. If not, manually:
```bash
growpart /dev/mmcblk0 2
resize2fs /dev/mmcblk0p2
```
## RPMsg na AM62 - Niedeterministyczna numeracja virtio busów

### Problem

`/dev/rpmsg_ctrl0` i `/dev/rpmsg_ctrl1` mogą wskazywać na **różne**
remote core'y (M4F lub R5F) między bootami. Hardcoded ścieżki **nie działają**.

### Rozwiązanie

Autodetect przez sysfs:

```c
for (int i = 0; ; i++) {
    snprintf(path, "/sys/class/rpmsg/rpmsg_ctrl%d/device", i);
    if (readlink(path, real_path) < 0) break;
    if (strstr(real_path, "5000000.m4fss")) {
        // To jest M4F ctrl
    }
}
```

Po stronie Go: `findM4FChrdev()` w `protocol-test/main.go`.

### Identyfikatory hardware AM62

- M4F: `5000000.m4fss`
- R5F: `78000000.r5f`

## /dev/rpmsg0 - loopback gdy wskazuje na R5F

### Problem

Pisanie do `/dev/rpmsg0` powodowało **loopback** w kernelu (RX = TX bajtowo).

### Przyczyna

`/dev/rpmsg0` w niektórych boot'ach to **R5F chrdev** (default firmware z TI demo
robi local loopback). My chcemy M4F.

### Rozwiązanie

`findM4FChrdev()` szuka:
1. `/sys/class/rpmsg/rpmsg[0-9]*` symlink wskazuje na `5000000.m4fss` (M4F)
2. AND nazwa zawiera `rpmsg_chrdev` (nie `rpmsg-client-sample` ani inny custom endpoint)

## Go service zombie process po SSH disconnect

### Problem

`ssh root@bramka "./protocol-test"` w PowerShell. Po Ctrl+C w PowerShell,
proces wciąż żyje na bramce. Kolejny run → "resource busy" na `/dev/rpmsg0`.

### Przyczyna

Standardowe `ssh` nie alokuje pseudo-TTY → SIGINT nie propaguje do remote process.

### Rozwiązanie

`ssh -t root@bramka "./protocol-test"` — flag `-t` wymusza PTY allocation.
Plus w `Deploy-Go` dodajemy `pkill -f $ServiceName` przed startem (cleanup
po ewentualnych poprzednich zombie).

## Volatile vs const uint8_t* w protocol_decode

### Problem

`gRxBuffer.data` to `volatile char[]`. `protocol_decode` przyjmuje `const uint8_t*`.
Compiler warning: "discards qualifiers".

### Rozwiązanie tymczasowe

Explicit cast: `(const uint8_t *)gRxBuffer.data`.

### Rozwiązanie docelowe (later)

Lokalna kopia bufora w `handleLinuxMessage` - pozwala wcześniej zwolnić `pending`
flag i uniknąć volatile concerns.

## Binary protocol - lessons z implementacji

### CRC compatibility wymaga DOKŁADNIE tej samej implementacji

Init value 0xFFFF, poly 0x1021, no reflect, no xorout. Wszystkie cztery muszą się zgadzać.
Test vector `crc16("123456789") == 0x29B1` - standard XMODEM.

### Struct packing krytyczne

`__attribute__((packed))` na `msg_header_t`. Bez tego compiler doda padding
i wire format M4F ≠ Go.

### Big-endian wire format

Mimo że obie strony są little-endian (ARM Cortex-M4 i Cortex-A53),
wire format **BE** dla portability. Helper functions `protocol_get_u16_be`
i `protocol_put_u16_be` w header. **Nigdy nie polegaj na memcpy bezpośrednio
ze struct'a do wire.**

### Single source of truth z cgo

Jeden `protocol.h` w `shared/`. Kopiowany do:
- M4F project folder (CCS workspace)
- Go service folder (przez Deploy-Go)

Go używa cgo: `#include "protocol.h"` + `import "C"`.
Stałe dostępne jako `C.MSG_HELLO`, etc.
Inline functions z header **automatycznie** dostępne w Go bez extra linkowania.

## Reader spam gdy M4F crashes

### Problem

Gdy M4F zostanie zatrzymany (np. `echo stop > /sys/.../state`), `/dev/rpmsg0`
przestaje istnieć ale Go reader nadal próbuje `Read()`. Wynik: spam errorów
"broken pipe" / "not pollable" co 100ms.

### Rozwiązanie

W `transport.go` reader rozpoznaje **fatal errors** i kończy się zamiast retry:

```go
if strings.Contains(errStr, "broken pipe") || 
   strings.Contains(errStr, "not pollable") ||
   strings.Contains(errStr, "no such device") {
    log.Printf("[Transport] FATAL: device disappeared - exiting reader")
    return
}
```

To rozróżnia "transient error" (retry OK) od "device gone" (must exit).

## Symulacja retransmisji - dlaczego "echo stop" nie wystarczy

### Problem  

Test retry musimy zasymulować scenariusz "ACK się zgubił". Naturalne odruchowo: zatrzymać M4F.
Ale `echo stop > /sys/.../state` **niszczy device file** - Linux dostaje EPIPE
natychmiast, retry timer w ogóle się nie odpala.

### Rozwiązanie - drop simulation w Go

Dodanie `debugDropAcks` counter w Protocol layer. Reader normalnie odbiera ACK
od M4F, ale dispatcher **ignoruje** pierwsze N ACK (decrementing counter).
M4F nic nie wie, Linux protocol layer udaje "nie dostałem".

To **lepsze testowanie**:
- Testuje **całą ścieżkę** retry (timer, retransmit, idempotency po stronie M4F)
- Nie wymaga grzebania w M4F żeby symulować awarie
- Pełna kontrola nad ile ACK zignorować (1 → success after retry, 100 → giveup)

## Pending ACKs - dlaczego statyczna tablica w M4F

### Problem

Tradycyjne Go: `map[uint16]*pendingAck` - dynamic, automatic.
M4F (embedded, NoRTOS): brak malloc bezpieczny, każda alokacja to potencjalny leak.

### Rozwiązanie

`pending_ack_t gPendingAcks[MAX_PENDING_ACKS]` - statyczna tablica.
Każdy slot ma `in_use` flag, linear search po seq (MAX_PENDING_ACKS=8, więc szybko).

Tradeoff: max 8 jednoczesnych unacked messages. W praktyce wystarczy bo:
- ACK_TIMEOUT_MS = 1000ms
- Typowo 1-2 inflight, retry zwalnia szybko
- Aplikacja może rate-limit'ować jeśli więcej potrzebuje

## Bramka resetuje się losowo co minutę

### Objawy

Bramka działa, robisz operacje, nagle reset. Boot, ssh, normalne działanie,
za chwilę znów reset. Cykl ~60s.

### Przyczyna

AM62 ma **aktywny watchdog hardware** (`/dev/watchdog0`) z **nowayout** flag.
Jeśli nikt go nie klepie userspace, **resetuje SoC po 60 sekundach**.

Domyślny Linux install nie aktywuje systemd kicker'a:
$ grep -i watchdog /etc/systemd/system.conf
#RuntimeWatchdogSec=off    ← OFF!
### Diagnoza

```bash
# Watchdog aktywny:
ls -la /dev/watchdog*
wdctl /dev/watchdog
# Identity: K3 RTI Watchdog, Timeout: 60s

# Kto klepie:
lsof /dev/watchdog0
# Pusty = nikt = będzie reset

# Countdown:
wdctl /dev/watchdog | grep Timeleft
sleep 5
wdctl /dev/watchdog | grep Timeleft
# Drugi pomiar niższy = NIKT NIE KLEPIE
# Drugi pomiar równy/wyższy = OK, ktoś klepie
```

### Rozwiązanie

Włącz systemd runtime watchdog:

```bash
sed -i 's/#RuntimeWatchdogSec=off/RuntimeWatchdogSec=30/' /etc/systemd/system.conf
reboot
```

Po reboot:
```bash
lsof /dev/watchdog0
# COMMAND PID USER ... NAME
# systemd  1  root ... /dev/watchdog0
```

Teraz systemd klepie co 30s, watchdog timeout 60s = healthy margin.

### Emergency kicker (gdy nie możesz zrobić reboot zaraz)

Trzymaj bramkę żyjącą bez reboot:

```bash
nohup sh -c 'while true; do echo 1 > /dev/watchdog; sleep 20; done' \
    > /tmp/wdkick.log 2>&1 &
```

To kicker w tle co 20s. Zatrzyma resety **do następnego reboot** (potem
trzeba albo znów go uruchomić, albo skonfigurować systemd).

## systemd_notify socket error

### Problem

Go service nie wysyła `WATCHDOG=1` lub loguje:
[systemd] notify dial failed: dial unix /run/systemd/notify: connect: no such file or directory
### Przyczyny + naprawa

**A**: Uruchamiasz service **ręcznie** (nie przez systemd):
- `NOTIFY_SOCKET` env var nie jest ustawione
- Solution: to OK, sd_notify będzie cicho ignorować
- Production: zawsze uruchamiaj przez `systemctl start rpmsg-service`

**B**: Unit file ma `Type=simple` zamiast `Type=notify`:
- systemd nie tworzy `NOTIFY_SOCKET`
- Solution: zmień na `Type=notify` w unit file

**C**: Container/chroot environment:
- Socket może nie być propagowany
- Solution: bind-mount socket lub disable watchdog

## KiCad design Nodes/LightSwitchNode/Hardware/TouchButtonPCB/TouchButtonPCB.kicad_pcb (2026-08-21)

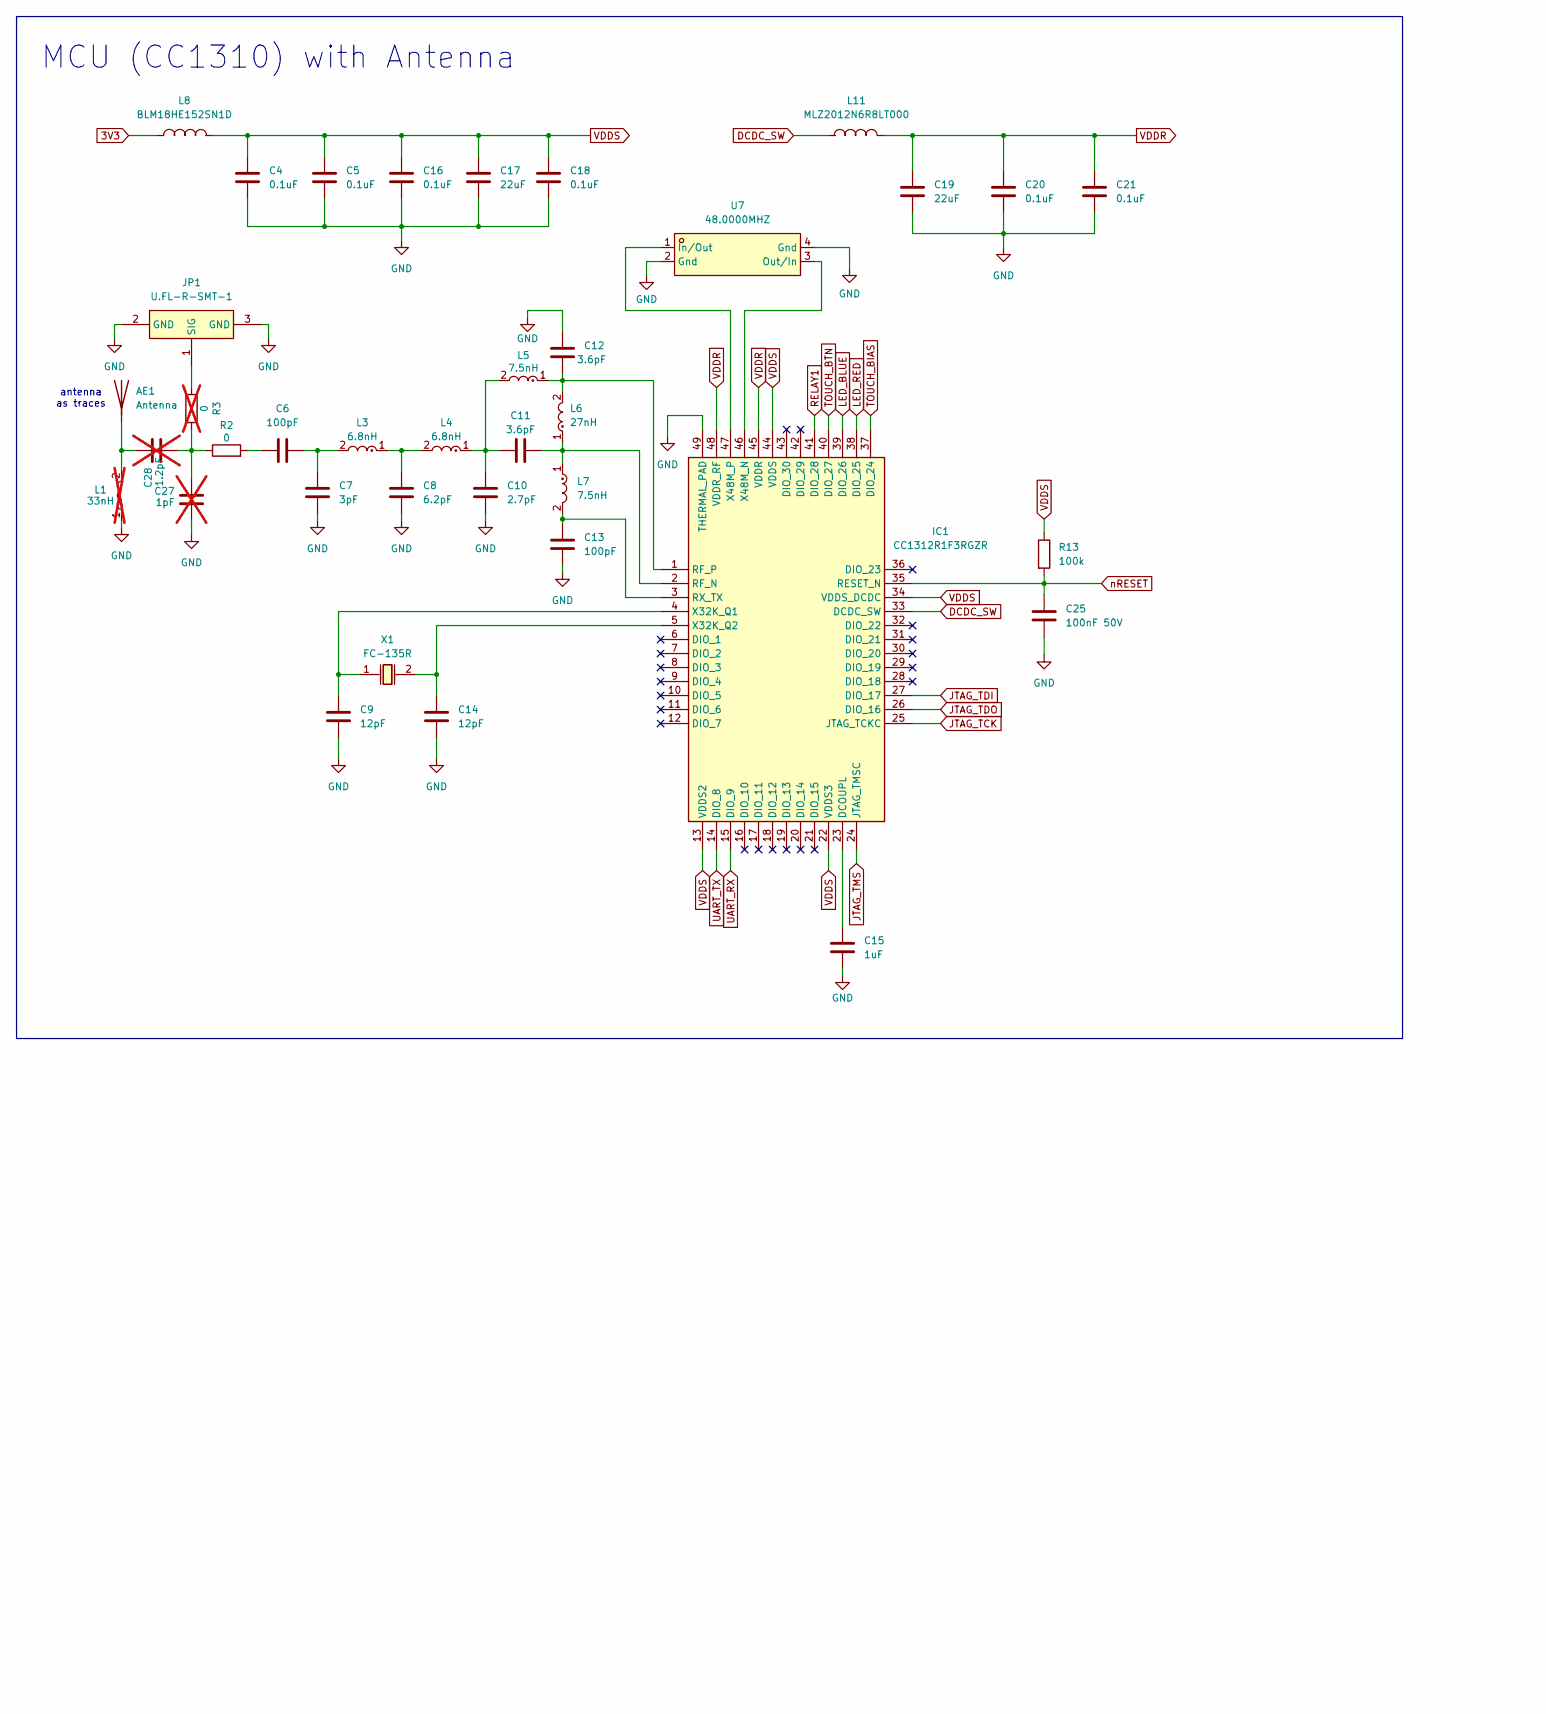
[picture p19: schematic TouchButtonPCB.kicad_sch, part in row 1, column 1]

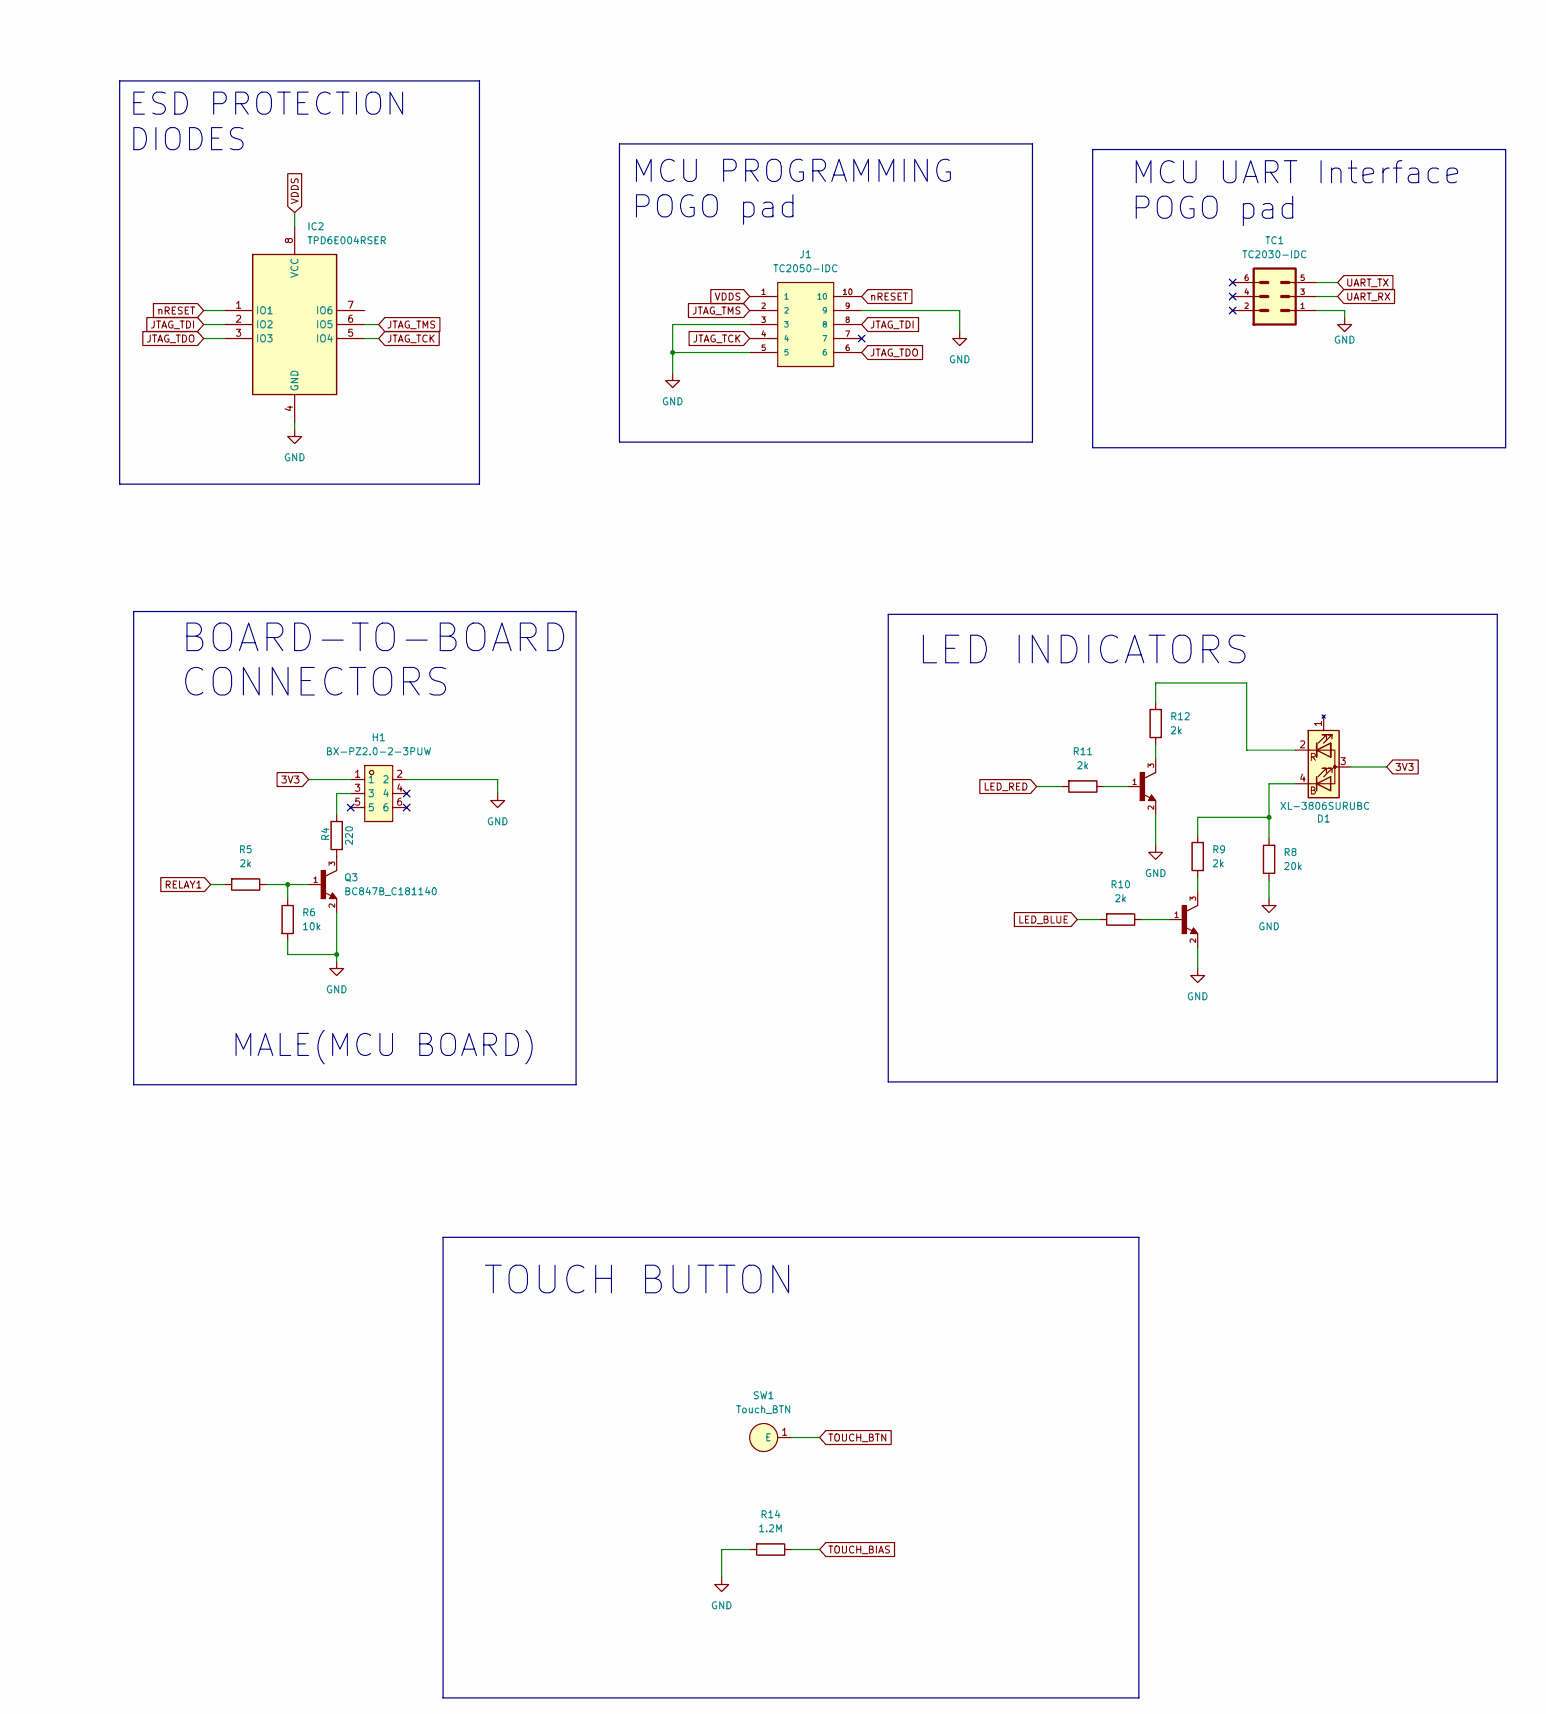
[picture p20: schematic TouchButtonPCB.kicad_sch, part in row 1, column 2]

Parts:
AE1: Antenna; ANT_IFA_868M
C4, C5, C16, C18, C20, C21: 0.1uF; C_0402; MPN CC0402KRX7R7BB104; Mouser GRM155R70J104KA01D
C6, C13: 100pF; C_0402; MPN GRM1555C1H101JA01D; Mouser GRM1555C1H101JA01D
C7: 3pF; C_0402; MPN GJM1555C1H3R0BB01D; Mouser GRM1555C1H3R0CA01J
C8: 6.2pF; C_0402; MPN 0402CG6R2C500NT; Mouser GRM1555C1H6R2CA01J
C9: 12pF; C_0402; MPN GRM1555C1H120JA01D; Mouser GRM1555C1H120JA01D
C10: 2.7pF; C_0402; MPN GRM1555C1H2R7CA01D; Mouser GRM1555C1H2R7CA01D
C11, C12: 3.6pF; C_0402; MPN GRM1555C1H3R6CA01D; Mouser GRM1555C1H3R6CA01D
C14: 12pF; C_0402; MPN GRM1555C1H120JA01D; Mouser GRM1555C1H150JA01D
C15: 1uF; C_0402; MPN CL05A105KO5NNNC; Mouser GRM155R61C105KA12D
C17, C19: 22uF; C_0603; MPN CL05A226MQ5QUNC; Mouser GRM188R60J226MEA0D
C25: 100nF 50V; C_0402; MPN CC0402KRX7R9BB222; Mouser C0805C222K5RACTU
C27: 1pF; C_0402; MPN GJM1555C1H3R0BB01D; Mouser GRM1555C1H3R0CA01J; not fitted
C28: 1.2pF; C_0402; MPN GJM1555C1H3R0BB01D; Mouser GRM1555C1H3R0CA01J; not fitted
D1: XL-3806SURUBC; LED-SMD_4P-L3.8-W1.0_XL-3806RGBC-4L; MPN XL-3806SURUBC; JLC_Type Extended
H1: BX-PZ2.0-2-3PUW; HDR-SMD_6P-P2.00-V-M-R2-C3-LS6.5; MPN BX-PZ2.0-2-3PUW; LCSC Part C49326165
IC1: CC1312R1F3RGZR; CC1310_VQFN-48; Mouser Part Number 595-CC1310F128RGZR
IC2: TPD6E004RSER; Mouser Part Number 595-TPD6E004RSER
J1: TC2050-IDC; TAG-CONNECT_TC2050-IDC; PARTREV A
JP1: U.FL-R-SMT-1; RF-SMD_FRF05002-JSS103M; MPN U.FL-R-SMT-1(80); LCSC Part C88374
L1: 33nH; L_Polarized_0402; MPN LQG15HS8N2J02D; Mouser LQG15HS8N2J02D; not fitted
L3, L4: 6.8nH; L_Polarized_0402; MPN LQG15HS6N8J02D; Mouser LQG15HS6N8J02D
L5, L7: 7.5nH; L_Polarized_0402; MPN LQG15HS7N5J02D; Mouser LQG15HS7N5J02D
L6: 27nH; L_Polarized_0402; Mouser Part Number 81-LQG15HZ27NJ02D
L8: BLM18HE152SN1D; L0603; MPN BLM18HE152SN1D; LCSC Part C82155
L11: MLZ2012N6R8LT000; IND-SMD_L2.0-W1.3; MPN MLZ2012N6R8LT000; LCSC Part C82157
Q1, Q2, Q3: BC847B_C181140; SOT-23-3_L2.9-W1.3-P1.90-LS2.4-TL; MPN BC847B; LCSC Part C181140
R2: 0; R_0402; LCSC Part C106231
R3: 0; R_0402; LCSC Part C106231; not fitted
R4: 220; R_0805
R5, R10, R11: 2k; R_0402; MPN RC0402FR-072K2L; JLC_Type Extended
R6: 10k; R_0402; MPN RC0402FR-0710KL; JLC_Type Extended
R8: 20k; R_0402; MPN RC0402FR-0720KL; JLC_Type Extended
R9, R12: 2k; R_0402; MPN RC0402FR-072KL; JLC_Type Extended
R13: 100k; R_0402; MPN 0402WGF4752TCE; Mouser CRCW060347K5FKEA
R14: 1.2M; R_0402; MPN RC0402FR-072K2L; JLC_Type Extended
SW1: Touch_BTN; Touch_BTN_D12mm
TC1: TC2030-IDC
U7: 48.0000MHZ; CRYSTAL-SMD_4P-L3.2-W2.5-BL; MPN ABM8W-48.0000MHZ-7-D1X-T3; LCSC Part C6732653
X1: FC-135R; OSC-SMD_L3.2-W1.5; MPN X1A0001410003; LCSC Part C94276

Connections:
3V3: D1.3 (A), H1.1, L8.1
DCDC_SW: IC1.33 (DCDC_SW), L11.1
GND: C4.2, C5.2, C7.2, C8.2, C9.2, C10.2, C12.1, C13.2, C14.2, C15.2, C16.2, C17.2, C18.2, C19.2, C20.2, C21.2, C25.2, C27.2, H1.2, IC1.49 (THERMAL_PAD), IC2.4 (GND), J1.3, J1.5, J1.9, JP1.2 (GND), JP1.3 (GND), L1.1, Q1.2, Q2.2, Q3.2, R6.2, R8.1, R14.2, TC1.1, U7.2 (Gnd), U7.4 (Gnd)
JTAG_TCK: IC1.25 (JTAG_TCKC), IC2.5 (IO4), J1.4
JTAG_TDI: IC1.27 (DIO_17), IC2.2 (IO2), J1.8
JTAG_TDO: IC1.26 (DIO_16), IC2.3 (IO3), J1.6
JTAG_TMS: IC1.24 (JTAG_TMSC), IC2.6 (IO5), J1.2
LED_BLUE: IC1.39 (DIO_26), R10.2
LED_RED: IC1.38 (DIO_25), R11.2
unnamed: C6.1, C7.1, L3.2
unnamed: C6.2, R2.2
unnamed: C8.1, L3.1, L4.2
unnamed: C10.1, C11.1, L4.1, L5.2
unnamed: D1.4 (BK), R8.2, R9.2
unnamed: D1.2 (RK), R12.2
unnamed: H1.3, R4.2
unnamed: C15.1, IC1.23 (DCOUPL)
unnamed: C11.2, IC1.2 (RF_N), L6.1, L7.1
unnamed: C12.2, IC1.1 (RF_P), L5.1, L6.2
unnamed: C13.1, IC1.3 (RX_TX), L7.2
unnamed: C9.1, IC1.4 (X32K_Q1), X1.1 (OSC1)
unnamed: C14.1, IC1.5 (X32K_Q2), X1.2 (OSC2)
unnamed: IC1.46 (X48M_N), U7.3 (Out/In)
unnamed: IC1.47 (X48M_P), U7.1 (In/Out)
unnamed: JP1.1 (SIG), R3.1
unnamed: Q1.1, R11.1
unnamed: Q1.3, R12.1
unnamed: Q2.1, R10.1
unnamed: Q2.3, R9.1
unnamed: Q3.1, R5.1, R6.1
unnamed: Q3.3, R4.1
RELAY1: IC1.41 (DIO_28), R5.2
TOUCH_BIAS: IC1.37 (DIO_24), R14.1
TOUCH_BTN: IC1.40 (DIO_27), SW1.1 (E_1)
UART_RX: IC1.15 (DIO_9), TC1.3
UART_TX: IC1.14 (DIO_8), TC1.5
VDDR: C19.1, C20.1, C21.1, IC1.45 (VDDR), IC1.48 (VDDR_RF), L11.2
VDDS: C4.1, C5.1, C16.1, C17.1, C18.1, IC1.13 (VDDS2), IC1.22 (VDDS3), IC1.34 (VDDS_DCDC), IC1.44 (VDDS), IC2.8 (VCC), J1.1, L8.2, R13.1
nRESET: C25.1, IC1.35 (RESET_N), IC2.1 (IO1), J1.10, R13.2

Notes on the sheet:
MALE(MCU BOARD)
MCU (CC1310) with Antenna
TOUCH BUTTON
LED INDICATORS
BOARD-TO-BOARD CONNECTORS
antenna as traces
MCU PROGRAMMING POGO pad
ESD PROTECTION DIODES
MCU UART Interface POGO pad

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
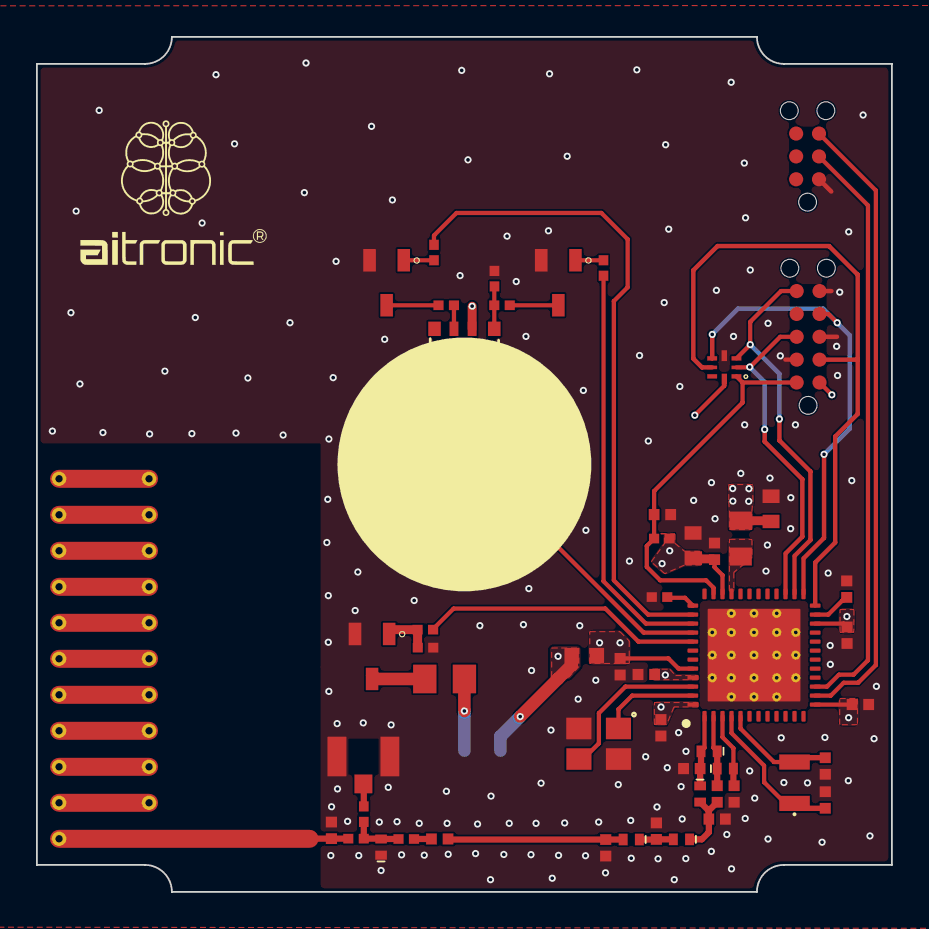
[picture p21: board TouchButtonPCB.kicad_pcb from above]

Board: 4 copper layers, 47.5 x 47.5 mm, 55 parts (1 on the bottom side), 41 nets.

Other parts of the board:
R1: 0; R_0402

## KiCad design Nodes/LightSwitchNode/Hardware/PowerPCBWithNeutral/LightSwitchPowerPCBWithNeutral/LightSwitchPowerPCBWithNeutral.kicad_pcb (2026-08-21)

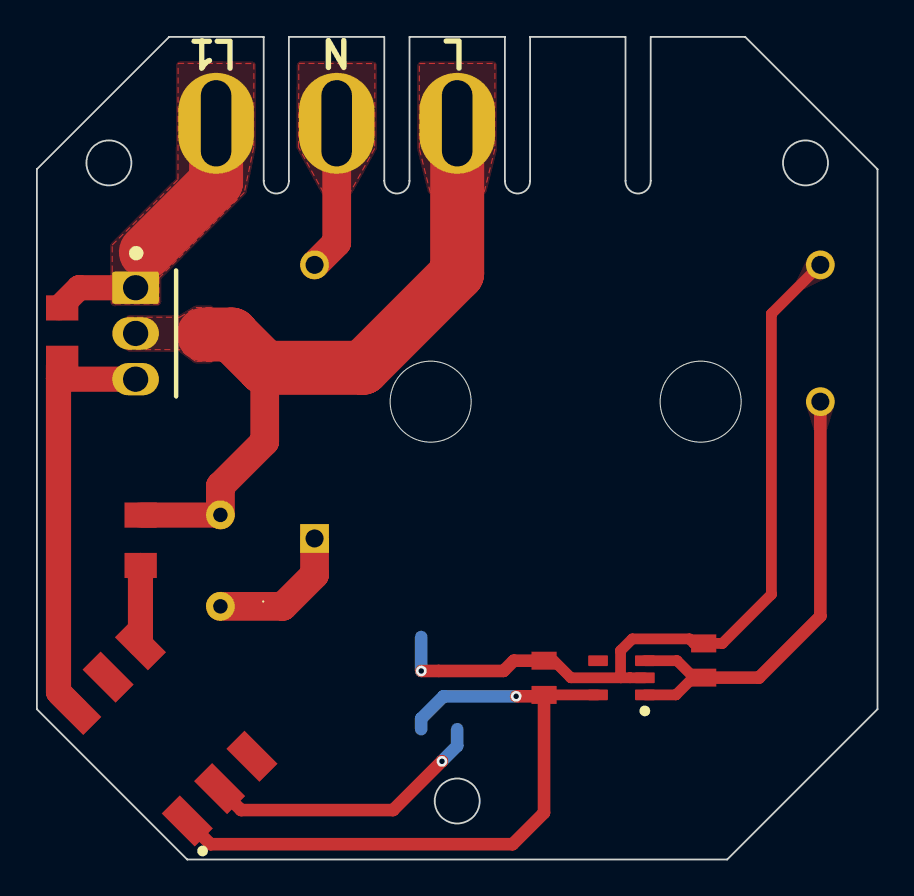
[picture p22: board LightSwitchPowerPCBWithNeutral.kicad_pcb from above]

Board: 2 copper layers, 46.7 x 45.7 mm, 13 parts (1 on the bottom side), 10 nets.

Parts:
C1, C2: 1uF; C0805
J1, J5, J6: Brass_Screw_Terminal_Pad
Q3: BTA16-800BWRG; TO-220-3_L10.0-W4.5-P2.54-L
R2, R3: 330; R1206
R4: 47R 1W; R_Axial_DIN0309_L9.0mm_D3.2mm_P5.08mm_Vertical
U1: TPS7A2033PDBVR; SOT-23-5_L2.9-W1.6-P0.95-LS2.8-BR
U2: IRM-01-5; PWRM-TH_L33.7-W22.2_IRM-01-12
U3: BX-PM2.0-2-3PUW; HDR-SMD_6P-P2.00-V-F-R2-C3-S6.5
U4: MOC3063S-TA1; SMD-6_L7.3-W6.5-P2.54-LS10.2-BL

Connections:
3V3: C2.1, U1.5 (OUT), U3.1, U4.1
GND: C1.2, C2.2, U1.2 (GND), U2.13 (-V), U3.2
L: J6.1 (Pin_1_1), Q3.2, R2.2, R4.1
L1: J1.1 (Pin_1_1), Q3.1, R3.1
N: J5.1 (Pin_1_1), U2.24 (AC/N)
unnamed: Q3.3, R3.2, U4.6
unnamed: R2.1, U4.4
unnamed: C1.1, U1.1 (IN), U1.3 (EN), U2.12 (+V)
unnamed: R4.2, U2.1 (AC/L)
RELAY1: U3.3, U4.2

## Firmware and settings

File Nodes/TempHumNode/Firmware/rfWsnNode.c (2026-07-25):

/*
 * rfWsnNode.c - gen2 battery T&H node (CC1310 + SHT35 + BQ35100).
 *
 * Power-cycled by a TPL5111 timer: it gates power (TPS22860 + TPS61291) on a
 * fixed (resistor-set) interval; the MCU cold-boots, takes a reading, sends it
 * to the gateway, then asserts DONE (DIO23) so the timer cuts power until the
 * next cycle. Firmware is linear: boot -> measure -> send -> DONE.
 *
 * Bring-up note: this board has NO UART pin (JTAG only), so debug goes to
 * System_printf (visible in CCS via ROV -> SysMin), and the key readings are
 * kept in volatile file-scope vars you can watch in the debugger.
 *
 * NODE_MODE_DONE:
 *   1 = real power-cycle (assert DONE, then halt; timer cuts power).
 *   0 = BENCH/JTAG loop: stay alive, measure+send every NODE_LOOP_S seconds
 *       (debugger stays attached, logs/repeats visible) - isolates firmware
 *       repeatability from the hardware power-cycle.
 */
#include <xdc/std.h>
#include <xdc/runtime/System.h>
#include <stdarg.h>
#include <stdbool.h>
#include <stdint.h>
#include <stdio.h>
#include <string.h>

#include <ti/sysbios/BIOS.h>
#include <ti/sysbios/knl/Task.h>
#include <ti/sysbios/knl/Clock.h>
#include <ti/sysbios/knl/Semaphore.h>
#include <ti/drivers/GPIO.h>
#include <ti/drivers/UART.h>
#include <ti/drivers/NVS.h>

#include "Board.h"
#include "sensors.h"
#include "radio.h"
#include "node_protocol.h"

#include <ti/devices/DeviceFamily.h>
#include DeviceFamily_constructPath(driverlib/ioc.h)
#include DeviceFamily_constructPath(driverlib/gpio.h)
#include DeviceFamily_constructPath(driverlib/prcm.h)
#include DeviceFamily_constructPath(inc/hw_types.h)
#include DeviceFamily_constructPath(inc/hw_memmap.h)
#include DeviceFamily_constructPath(inc/hw_fcfg1.h)
#include <ti/drivers/GPIO.h>

/* rev-2 bring-up SWEEP: 1 = drive each IOID 0..30 HIGH for 3 s in turn (skips JTAG
 * DIO16/17). Keep a multimeter on the pad in question (e.g. package pin 18 = UART_TX);
 * when it reads 3.3 V, HALT the debugger and read `g_sweep_ioid` = the real IOID on
 * that pad. Use it to fix the pin map (the KiCad symbol's DIO names are wrong). */
#define NODE_PIN_SWEEP_TEST   0

/* rev-2 bring-up pin check: 1 = toggle NODE_TOGGLE_IOID 2 s HIGH / 2 s LOW on pin 18. */
#define NODE_PIN_TOGGLE_TEST  0
/* <<< SET THIS to the g_sweep_ioid value that drove pin 18 to 3.3 V >>> */
#define NODE_TOGGLE_IOID      12

/* rev-2 bring-up: 1 = ONLY prove the UART talks (TX=DIO12), print a counter every
 * 1 s and loop forever - nothing else runs. Set 0 once UART is confirmed. */
#define NODE_UART_SMOKE_TEST  0

/* rev-2 bring-up: 1 = press JOIN (DIO26) -> send a JOIN_REQUEST to the gateway over
 * radio (factory_id from FCFG, capabilities=0), log to UART. */
#define NODE_JOIN_TEST        1

/* rev-2 low-power telemetry cadence (provisioned steady state). */
#define NODE_SLEEP_S     240u   /* deep-sleep (STANDBY ~1uA) between cycles = 4 min */
#define NODE_BATT_EVERY  5u     /* read MCP3421 battery every Nth cycle (SoC moves slowly) */
#define NODE_DEBUG_UART  1      /* 1 = per-cycle UART log (opened+closed each cycle so STANDBY still works); 0 = silent, lowest power */

/* JOIN provisioning window: after a button press the node stays AWAKE (radio in RX,
 * ~6 mA) up to NODE_JOIN_WINDOW_S waiting for JOIN_ACCEPT. You must approve in the app
 * within this window or the node sleeps again (press JOIN to retry). */
#define NODE_JOIN_WINDOW_S   90u

#define NODE_MODE_DONE   0          /* 1 = power-cycle (DONE); 0 = bench loop  */
#define NODE_LOOP_S      15         /* bench-loop interval (NODE_MODE_DONE==0) */
#define NODE_ADDRESS     0x1Au      /* fixed for now (provisioning later)      */
#define DONE_DIO         IOID_23    /* TPL5111 DONE feedback line              */

static Task_Struct nodeTaskStruct;
static uint8_t      nodeTaskStack[2048];

/* Watch these in the debugger (no UART on this board). */
static volatile float    g_temp = 0.0f, g_hum = 0.0f;
static volatile uint16_t g_batt_mv = 0;
static volatile uint8_t  g_soh = 0;
static volatile int32_t  g_acc_uah = 0;   /* cumulative used uAh (ACC mode) - consumption measurement */
static volatile bool     g_okTH = false, g_okBatt = false, g_okSoh = false, g_okAcc = false, g_acked = false;
static volatile uint32_t g_cycle = 0;
static volatile int      g_sweep_ioid = -1;   /* rev-2 sweep: IOID currently driven HIGH (WATCH this) */
static volatile bool     g_joinPressed = false;

/* JOIN button wake: the GPIO interrupt (AON) wakes the MCU from STANDBY and posts this,
 * so a press is handled immediately even mid-sleep (not only at the next 4-min cycle). */
static Semaphore_Struct  joinSemStruct;
static Semaphore_Handle  joinSem;

/* Read the chip's IEEE MAC from FCFG = the immutable factory id (8 B, little-endian). */
static void read_factory_id(uint8_t out[NODE_FACTORY_ID_LEN])
{
    uint32_t lo = HWREG(FCFG1_BASE + FCFG1_O_MAC_15_4_0);
    uint32_t hi = HWREG(FCFG1_BASE + FCFG1_O_MAC_15_4_1);
    out[0] = (uint8_t)(lo);       out[1] = (uint8_t)(lo >> 8);
    out[2] = (uint8_t)(lo >> 16); out[3] = (uint8_t)(lo >> 24);
    out[4] = (uint8_t)(hi);       out[5] = (uint8_t)(hi >> 8);
    out[6] = (uint8_t)(hi >> 16); out[7] = (uint8_t)(hi >> 24);
}

/* JOIN button ISR-context callback: flag it AND post the wake semaphore so the task
 * blocked in Semaphore_pend wakes from STANDBY and provisions right away. Semaphore_post
 * is ISR-safe in SYS/BIOS. */
static void joinButtonCb(uint_least8_t index)
{
    (void)index;
    g_joinPressed = true;
    Semaphore_post(joinSem);
}

/* ---- persisted RF address (internal-flash NVS, Board_NVSINTERNAL) ---- */
#define TH_IDENT_MAGIC  0x54484E31u   /* "THN1" - guards uninitialized flash */
typedef struct { uint32_t magic; uint8_t addr; uint8_t _pad[3]; } ThIdentRec;

/* Returns the persisted RF address, or ADDR_UNPROVISIONED (0xFF) if none/invalid. */
static uint8_t nvs_load_address(void)
{
    NVS_Params p;
    NVS_init();
    NVS_Params_init(&p);
    NVS_Handle h = NVS_open(Board_NVSINTERNAL, &p);
    if (h == NULL) return ADDR_UNPROVISIONED;

    ThIdentRec rec;
    uint8_t addr = ADDR_UNPROVISIONED;
    if (NVS_read(h, 0, &rec, sizeof(rec)) == NVS_STATUS_SUCCESS &&
        rec.magic == TH_IDENT_MAGIC &&
        rec.addr >= ADDR_POOL_FIRST && rec.addr <= ADDR_POOL_LAST) {
        addr = rec.addr;
    }
    NVS_close(h);
    return addr;
}

/* Persist the gateway-assigned RF address so a power-cycle skips re-JOIN. */
static bool nvs_save_address(uint8_t addr)
{
    NVS_Params p;
    NVS_init();
    NVS_Params_init(&p);
    NVS_Handle h = NVS_open(Board_NVSINTERNAL, &p);
    if (h == NULL) return false;

    ThIdentRec rec;
    memset(&rec, 0, sizeof(rec));
    rec.magic = TH_IDENT_MAGIC;
    rec.addr  = addr;
    int rc = NVS_write(h, 0, &rec, sizeof(rec), NVS_WRITE_ERASE | NVS_WRITE_POST_VERIFY);
    NVS_close(h);
    return (rc == NVS_STATUS_SUCCESS);
}

/* Open UART, printf ONE line, close it - releasing the UART power dependency so STANDBY
 * still works around it. NODE_DEBUG_UART 0 compiles this to a no-op (lowest power). */
#if NODE_DEBUG_UART
static void dbg_uart(const char *fmt, ...)
{
    UART_Params up;
    UART_Params_init(&up);
    up.baudRate      = 115200;
    up.writeDataMode = UART_DATA_BINARY;
    UART_Handle u = UART_open(Board_UART0, &up);
    if (u == NULL) return;

    char b[160];
    va_list ap;
    va_start(ap, fmt);
    int n = vsnprintf(b, sizeof(b), fmt, ap);
    va_end(ap);
    if (n > 0) UART_write(u, b, (size_t)n);
    UART_close(u);
}
#else
static inline void dbg_uart(const char *fmt, ...) { (void)fmt; }
#endif

/* JOIN button = Board_GPIO_BUTTON1 (rev-2: DIO26), active low. The interrupt wakes the
 * MCU from STANDBY (AON) and posts joinSem. Set up ONCE before streaming - and in BOTH
 * paths (fresh JOIN and NVS-provisioned), so a provisioned node can still re-JOIN. */
static void setup_join_button(void)
{
    GPIO_setConfig(Board_GPIO_BUTTON1, GPIO_CFG_IN_PU | GPIO_CFG_IN_INT_FALLING);
    GPIO_setCallback(Board_GPIO_BUTTON1, joinButtonCb);
    GPIO_enableInt(Board_GPIO_BUTTON1);
}

/* Send one JOIN_REQUEST and listen up to 60 s for JOIN_ACCEPT. On accept, persist the
 * gateway-assigned address to NVS and return it in *addrOut. Returns true ONLY on a real
 * accept: an already-active node is silenced by the gateway (returns false -> keep addr);
 * a removed/detached node surfaces in the app for re-pair. Reused for first JOIN + re-JOIN. */
static bool provision_join(const uint8_t *factoryId, uint8_t *addrOut)
{
    MessageStruct msg;
    memset(&msg, 0, sizeof(msg));
    msg.id   = ADDR_UNPROVISIONED;               /* 0xFF = unprovisioned source */
    msg.type = NODE_TH_SENSOR;
    msg.cmd  = CMD_JOIN_REQUEST;
    memcpy(msg.payload.joinData.factory_id, factoryId, NODE_FACTORY_ID_LEN);
    msg.payload.joinData.capabilities = 0;       /* sensor: no actions */
    msg.length = (uint8_t)(4 + sizeof(msg.payload.joinData));

    /* One JOIN, then listen the whole window for JOIN_ACCEPT. We listen even if the
     * JOIN wasn't RF-ACKed (the gateway may have received it but the ACK back was lost),
     * to maximise the chance of catching the accept. If none arrives, sleep; the user
     * presses JOIN again to retry. */
    bool acked = radio_send_message(&msg, ADDR_GATEWAY, NULL, NULL);  /* JOIN = legacy 'D' */
    dbg_uart("[node] JOIN sent -> gw 0x%02x acked=%d - %us window, approve on the phone...\r\n",
             ADDR_GATEWAY, acked, NODE_JOIN_WINDOW_S);

    uint8_t addr = 0;
    if (radio_wait_join_accept(factoryId, &addr, NODE_JOIN_WINDOW_S * 1000u)) {
        /* Node got the address AND radio_wait_join_accept RF-ACKed it to the gateway;
         * now persist to NVS. The gateway only marks us `active` once our FIRST telemetry
         * arrives under this address (MarkActive) - that is the real "provisioning done". */
        bool saved = nvs_save_address(addr);     /* persist so a reboot skips JOIN */
        *addrOut = addr;
        dbg_uart("[node] *** JOIN_ACCEPT *** addr 0x%02x saved=%d - streaming\r\n", addr, saved);
        return true;
    }
    dbg_uart("[node] no JOIN_ACCEPT in %us - back to sleep (press JOIN to retry)\r\n", NODE_JOIN_WINDOW_S);
    return false;
}

/* Provisioned steady state (low-power): each cycle powers the SHT35 rail (PERIPH_EN),
 * opens I2C, reads T/RH (+ battery every Nth), closes everything, sends telemetry, then
 * deep-sleeps NODE_SLEEP_S. All peripherals are released before the sleep so the CC1310
 * enters STANDBY (~1 uA) between cycles. The sleep is a Semaphore_pend, so a JOIN button
 * press wakes it EARLY (GPIO wake) and (re-)provisions on the spot.
 * Returns true if the gateway UNREGISTERED us (§14: a NACK on the telemetry ACK window) -
 * NVS is wiped and the caller drops back to the unprovisioned shelf; otherwise never returns. */
static bool stream_telemetry(uint8_t addr, const uint8_t *factoryId)
{
    uint16_t sBattMv  = 0;
    uint8_t  sBattCtr = 0;

    for (;;) {
        /* --- wake window: power sensors, measure, power down --- */
        GPIO_write(Board_PERIPH_EN, 1);              /* SHT35 rail + ADC divider on */
        Task_sleep((20000UL) / Clock_tickPeriod);    /* settle */
        sensors_init();                              /* I2C open */

        float t = 0.0f, h = 0.0f;
        bool okth = sensors_read_th(&t, &h);

        uint16_t mv = sBattMv;
        if (sBattCtr == 0) {                         /* battery only every Nth cycle */
            if (sensors_read_mcp3421_mv(&mv)) sBattMv = mv;
        }
        sBattCtr = (uint8_t)((sBattCtr + 1) % NODE_BATT_EVERY);

        sensors_close();                             /* I2C close -> release dependency */
        GPIO_write(Board_PERIPH_EN, 0);              /* rail + divider off */

        bool charging = (GPIO_read(Board_nCHRGSTAT) == 0);

        /* --- send (radio_send_message opens+closes RF itself) --- */
        MessageStruct tm;
        memset(&tm, 0, sizeof(tm));
        tm.id   = addr;
        tm.type = NODE_TH_SENSOR;
        tm.cmd  = CMD_SEND_DATA_TO_DB;
        tm.payload.thData.temperature = t;
        tm.payload.thData.humidity    = h;
        tm.payload.thData.batt_mv     = sBattMv;
        tm.length = (uint8_t)(4 + sizeof(tm.payload.thData));
        /* 'E' frame (factory_id) so the gateway can key its §14 pending-command table.
         * The gateway may reply with a NACK carrying a command instead of an ACK. */
        uint8_t nackCmd = 0;
        bool tacked = okth ? radio_send_message(&tm, ADDR_GATEWAY, factoryId, &nackCmd) : false;

        dbg_uart("[node] addr=0x%02x  T=%d.%02d C  H=%d.%02d %%  batt=%u mV chg=%d  sht=%d acked=%d  -> sleep %us (or JOIN)\r\n",
                 addr, (int)t, (int)((t - (int)t) * 100),
                 (int)h, (int)((h - (int)h) * 100), sBattMv, charging, okth, tacked, NODE_SLEEP_S);

        /* §14: gateway piggybacked UNREGISTERED/REMOVE on the ACK window = "clear your
         * identity, go silent". Obey: echo a best-effort confirm (cmd == delivered cmd, so
         * the CC1310 recognises it and drops the entry), wipe NVS, return -> caller re-enters
         * the unprovisioned shelf. Idempotent: if the confirm is lost we're silent anyway. */
        if (nackCmd == CMD_UNREGISTERED || nackCmd == CMD_REMOVE) {
            MessageStruct cf;
            memset(&cf, 0, sizeof(cf));
            cf.id     = addr;
            cf.type   = NODE_TH_SENSOR;
            cf.cmd    = nackCmd;                  /* echo the delivered command = the confirm */
            cf.length = 4u;                       /* header only */
            (void)radio_send_message(&cf, ADDR_GATEWAY, factoryId, NULL);
            (void)nvs_save_address(ADDR_UNPROVISIONED);   /* out of pool -> loads as unprovisioned */
            dbg_uart("[node] UNREGISTERED by gateway (cmd %u) - NVS cleared, going to shelf\r\n", nackCmd);
            return true;
        }

        /* --- deep sleep: STANDBY (~1 uA) until the next cycle (RTC) OR a JOIN press
         * (GPIO wake posts joinSem). On a press, (re-)provision: an accept switches to the
         * new address; no accept (already-active node silenced by gw) keeps the old one. --- */
        Semaphore_pend(joinSem, (NODE_SLEEP_S * 1000000UL) / Clock_tickPeriod);
        if (g_joinPressed) {
            g_joinPressed = false;
            uint8_t newAddr;
            if (provision_join(factoryId, &newAddr)) {
                addr = newAddr;                      /* re-provisioned (possibly new address) */
            }
        }
    }
}

static void done_init(void)
{
    /* Make sure the GPIO peripheral is clocked (belt + braces alongside
     * GPIO_init()), then hold DONE low so the timer doesn't see a false "done"
     * while we work. (The board also has a 10k pulldown on DONE.) */
    PRCMPeripheralRunEnable(PRCM_PERIPH_GPIO);
    PRCMLoadSet();
    while (!PRCMLoadGet()) {}
    IOCPinTypeGpioOutput(DONE_DIO);
    GPIO_writeDio(DONE_DIO, 0);
}

static void assert_done(void)
{
    /* TPL5111 DONE idles LOW; a short HIGH *pulse* signals "task complete" (per
     * datasheet) -> the timer deasserts DRV and cuts power. Holding it high is
     * NOT the documented pattern, so we pulse and return to idle low. */
    GPIO_writeDio(DONE_DIO, 0);
    Task_sleep(2000 / Clock_tickPeriod);   /* ~2 ms low baseline   */
    GPIO_writeDio(DONE_DIO, 1);
    Task_sleep(2000 / Clock_tickPeriod);   /* ~2 ms high pulse     */
    GPIO_writeDio(DONE_DIO, 0);            /* back to idle low     */
}

/* Read sensors + battery accumulator and send one telemetry frame. Assumes I2C
 * is open and a gauging session is already active (caller owns GAUGE_START/STOP). */
static void read_and_send(void)
{
    g_cycle++;
    g_okAcc  = sensors_read_used_uah((int32_t *)&g_acc_uah);  /* cumulative used uAh (continuous session) */
    sensors_read_opconfig((uint8_t *)&g_soh);                 /* DIAG: OpConfig A (GMSEL=bits[1:0]) -> soh_pct */
    g_okTH   = sensors_read_th((float *)&g_temp, (float *)&g_hum);
    g_okBatt = sensors_read_batt_mv((uint16_t *)&g_batt_mv);

    System_printf("[node] cycle %u  T=%d.%02d C  H=%d.%02d %%  batt=%u mV  usedUAh=%ld  opcfg=0x%02x  (th=%d b=%d a=%d)\n",
                  g_cycle,
                  (int)g_temp, (int)((g_temp - (int)g_temp) * 100),
                  (int)g_hum,  (int)((g_hum  - (int)g_hum)  * 100),
                  g_batt_mv, (long)g_acc_uah, g_soh, g_okTH, g_okBatt, g_okAcc);
    System_flush();

    if (g_okTH) {
        MessageStruct msg;
        memset(&msg, 0, sizeof(msg));
        msg.id   = NODE_ADDRESS;
        msg.type = NODE_TH_SENSOR;
        msg.cmd  = CMD_SEND_DATA_TO_DB;
        msg.payload.thData.temperature = g_temp;
        msg.payload.thData.humidity    = g_hum;
        msg.payload.thData.batt_mv     = g_okBatt ? g_batt_mv : 0;
        msg.payload.thData.soh_pct     = g_soh;                        /* DIAG: OpConfig A byte */
        msg.payload.thData.acc_uah     = g_okAcc ? g_acc_uah : 0;      /* cumulative used uAh */
        msg.length = 4 + sizeof(msg.payload.thData);

        g_acked = radio_send_message(&msg, ADDR_GATEWAY, NULL, NULL);  /* legacy bench path ('D') */
        System_printf("[node] RF -> gateway 0x%02x: acked=%d\n", ADDR_GATEWAY, g_acked);
        System_flush();
    }
}

static void nodeTaskFunction(UArg a0, UArg a1)
{
#if NODE_PIN_SWEEP_TEST
    /* --- rev-2 SWEEP: drive each IOID HIGH 3 s in turn; find which one reaches pin 18 ---
     * Keep the multimeter on pin 18; when it reads 3.3 V, HALT and read g_sweep_ioid. */
    PRCMPeripheralRunEnable(PRCM_PERIPH_GPIO);
    PRCMLoadSet();
    while (!PRCMLoadGet()) {}
    System_printf("[sweep] driving each IOID HIGH 3s - watch pin 18, halt when 3.3V, read g_sweep_ioid\n"); System_flush();
    for (;;) {
        int io;
        for (io = 0; io <= 30; io++) {
            if (io == 16 || io == 17) continue;        /* skip JTAG TDO/TDI (would drop the debugger) */
            g_sweep_ioid = io;
            System_printf("[sweep] IOID_%d HIGH\n", io); System_flush();
            IOCPinTypeGpioOutput((uint32_t)io);
            GPIO_writeDio((uint32_t)io, 1);
            Task_sleep((3000000UL) / Clock_tickPeriod);
            GPIO_writeDio((uint32_t)io, 0);
            IOCPinTypeGpioInput((uint32_t)io);         /* release before next */
        }
    }
#endif

#if NODE_PIN_TOGGLE_TEST
    /* --- rev-2 pin check: toggle NODE_TOGGLE_IOID 2 s HIGH / 2 s LOW, measure pin 18 ---
     * Power the GPIO peripheral FIRST (as done_init does). */
    PRCMPeripheralRunEnable(PRCM_PERIPH_GPIO);
    PRCMLoadSet();
    while (!PRCMLoadGet()) {}
    System_printf("[pin-test] toggling IOID_%d 2s/2s - measure pin 18\n", NODE_TOGGLE_IOID); System_flush();
    IOCPinTypeGpioOutput(NODE_TOGGLE_IOID);
    for (;;) {
        GPIO_writeDio(NODE_TOGGLE_IOID, 1);             /* pin 18 -> 3.3 V */
        Task_sleep((2000000UL) / Clock_tickPeriod);
        GPIO_writeDio(NODE_TOGGLE_IOID, 0);             /* pin 18 -> 0 V   */
        Task_sleep((2000000UL) / Clock_tickPeriod);
    }
#endif

#if NODE_UART_SMOKE_TEST
    /* --- rev-2 UART smoke test: prove TX on DIO12 ---
     * Diagnostics go to System_printf (SysMin) too, so you can tell CONFIG failure
     * from WIRING failure via the debugger (CCS: Tools -> ROV -> SysMin), which works
     * over JTAG regardless of the UART wire. */
    UART_Params up;
    UART_init();
    UART_Params_init(&up);
    up.baudRate      = 115200;
    up.writeDataMode = UART_DATA_BINARY;   /* we add \r\n ourselves */
    System_printf("[uart-test] opening UART0 (TX must be DIO12)...\n"); System_flush();
    UART_Handle uart = UART_open(Board_UART0, &up);
    System_printf("[uart-test] UART_open -> %s\n", uart ? "OK" : "NULL=FAILED"); System_flush();
    if (uart == NULL) {
        while (1) {}                       /* CONFIG problem - see SysMin line above  */
    }
    {
        const char banner[] =
            "\r\n===================================\r\n"
            " rev-2 T&H node - UART ALIVE @115200\r\n"
            " TX on DIO12 (pkg pin 18). Hello!\r\n"
            "===================================\r\n";
        UART_write(uart, banner, sizeof(banner) - 1);

        uint32_t i = 0;
        char buf[64];
        for (;;) {
            int n = snprintf(buf, sizeof(buf), "[rev2 T&H] uart tick #%lu  (jesli to widzisz - dziala!)\r\n",
                             (unsigned long)i++);
            if (n > 0) {
                UART_write(uart, buf, (size_t)n);          /* -> physical TX (DIO12)   */
            }
            Task_sleep((1000000UL) / Clock_tickPeriod);    /* ~1 s                     */
        }
    }
#endif
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
int main(void)
{
    Board_initGeneral();
    GPIO_init();                       /* powers the GPIO peripheral (DONE pin) */

    Task_Params params;
    Task_Params_init(&params);
    params.stackSize = sizeof(nodeTaskStack);
    params.priority  = 2;
    params.stack     = nodeTaskStack;
    Task_construct(&nodeTaskStruct, nodeTaskFunction, &params, NULL);

    BIOS_start();
    return (0);
}

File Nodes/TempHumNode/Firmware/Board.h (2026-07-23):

/*
 * Copyright (c) 2015-2019, Texas Instruments Incorporated
 * All rights reserved.
 *
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
 * *  Redistributions of source code must retain the above copyright
 *    notice, this list of conditions and the following disclaimer.
 *
 * *  Redistributions in binary form must reproduce the above copyright
 *    notice, this list of conditions and the following disclaimer in the
 *    documentation and/or other materials provided with the distribution.
 *
 * *  Neither the name of Texas Instruments Incorporated nor the names of
 *    its contributors may be used to endorse or promote products derived
 *    from this software without specific prior written permission.
 *
 * THIS SOFTWARE IS PROVIDED BY THE COPYRIGHT HOLDERS AND CONTRIBUTORS "AS IS"
 * AND ANY EXPRESS OR IMPLIED WARRANTIES, INCLUDING, BUT NOT LIMITED TO,
 * THE IMPLIED WARRANTIES OF MERCHANTABILITY AND FITNESS FOR A PARTICULAR
 * PURPOSE ARE DISCLAIMED. IN NO EVENT SHALL THE COPYRIGHT OWNER OR
 * CONTRIBUTORS BE LIABLE FOR ANY DIRECT, INDIRECT, INCIDENTAL, SPECIAL,
 * EXEMPLARY, OR CONSEQUENTIAL DAMAGES (INCLUDING, BUT NOT LIMITED TO,
 * PROCUREMENT OF SUBSTITUTE GOODS OR SERVICES; LOSS OF USE, DATA, OR PROFITS;
 * OR BUSINESS INTERRUPTION) HOWEVER CAUSED AND ON ANY THEORY OF LIABILITY,
 * WHETHER IN CONTRACT, STRICT LIABILITY, OR TORT (INCLUDING NEGLIGENCE OR
 * OTHERWISE) ARISING IN ANY WAY OUT OF THE USE OF THIS SOFTWARE,
 * EVEN IF ADVISED OF THE POSSIBILITY OF SUCH DAMAGE.
 */

#ifndef __BOARD_H
#define __BOARD_H

#define Board_CC1310_LAUNCHXL

#ifdef __cplusplus
extern "C" {
#endif

#include <ti/drivers/Board.h>

#define Board_initGeneral()     Board_init()  /* deprecated */

#include "CC1310_LAUNCHXL.h"

#define Board_shutDownExtFlash() CC1310_LAUNCHXL_shutDownExtFlash()
#define Board_wakeUpExtFlash() CC1310_LAUNCHXL_wakeUpExtFlash()

/* These #defines allow us to reuse TI-RTOS across other device families */

#define Board_ADC0              CC1310_LAUNCHXL_ADC0
#define Board_ADC1              CC1310_LAUNCHXL_ADC1

#define Board_ADCBUF0           CC1310_LAUNCHXL_ADCBUF0
#define Board_ADCBUF0CHANNEL0   CC1310_LAUNCHXL_ADCBUF0CHANNEL0
#define Board_ADCBUF0CHANNEL1   CC1310_LAUNCHXL_ADCBUF0CHANNEL1

#define Board_CRYPTO0           CC1310_LAUNCHXL_CRYPTO0
#define Board_AESCCM0           CC1310_LAUNCHXL_AESCCM0
#define Board_AESGCM0           CC1310_LAUNCHXL_AESGCM0
#define Board_AESCBC0           CC1310_LAUNCHXL_AESCBC0
#define Board_AESCTR0           CC1310_LAUNCHXL_AESCTR0
#define Board_AESECB0           CC1310_LAUNCHXL_AESECB0
#define Board_AESCTRDRBG0       CC1310_LAUNCHXL_AESCTRDRBG0
#define Board_TRNG0             CC1310_LAUNCHXL_TRNG0

#define Board_DIO0              CC1310_LAUNCHXL_DIO0
#define Board_DIO1              CC1310_LAUNCHXL_DIO1
#define Board_DIO12             CC1310_LAUNCHXL_DIO12
#define Board_DIO15             CC1310_LAUNCHXL_DIO15
#define Board_DIO16_TDO         CC1310_LAUNCHXL_DIO16_TDO
#define Board_DIO17_TDI         CC1310_LAUNCHXL_DIO17_TDI
#define Board_DIO21             CC1310_LAUNCHXL_DIO21
#define Board_DIO22             CC1310_LAUNCHXL_DIO22

#define Board_GPIO_BUTTON0      CC1310_LAUNCHXL_GPIO_S1
#define Board_GPIO_BUTTON1      CC1310_LAUNCHXL_GPIO_S2
#define Board_GPIO_BTN1         CC1310_LAUNCHXL_GPIO_S1
#define Board_GPIO_BTN2         CC1310_LAUNCHXL_GPIO_S2
#define Board_GPIO_LED0         CC1310_LAUNCHXL_GPIO_LED_RED
#define Board_GPIO_LED1         CC1310_LAUNCHXL_GPIO_LED_GREEN
#define Board_GPIO_RLED         CC1310_LAUNCHXL_GPIO_LED_RED
#define Board_GPIO_GLED         CC1310_LAUNCHXL_GPIO_LED_GREEN
#define Board_GPIO_LED_ON       CC1310_LAUNCHXL_GPIO_LED_ON
#define Board_GPIO_LED_OFF      CC1310_LAUNCHXL_GPIO_LED_OFF
#define Board_GPIO_TMP116_EN    CC1310_LAUNCHXL_GPIO_TMP116_EN
#define Board_PERIPH_EN         CC1310_LAUNCHXL_GPIO_PERIPH_EN   /* rev-2 T&H: DIO25 */
#define Board_nCHRGSTAT         CC1310_LAUNCHXL_GPIO_NCHRGSTAT   /* rev-2 T&H: DIO14 */

#define Board_GPTIMER0A         CC1310_LAUNCHXL_GPTIMER0A
#define Board_GPTIMER0B         CC1310_LAUNCHXL_GPTIMER0B
#define Board_GPTIMER1A         CC1310_LAUNCHXL_GPTIMER1A
#define Board_GPTIMER1B         CC1310_LAUNCHXL_GPTIMER1B
#define Board_GPTIMER2A         CC1310_LAUNCHXL_GPTIMER2A
#define Board_GPTIMER2B         CC1310_LAUNCHXL_GPTIMER2B
#define Board_GPTIMER3A         CC1310_LAUNCHXL_GPTIMER3A
#define Board_GPTIMER3B         CC1310_LAUNCHXL_GPTIMER3B

#define Board_I2C0              CC1310_LAUNCHXL_I2C0
#define Board_I2C_TMP           CC1310_LAUNCHXL_I2C0

#define Board_I2S0              CC1310_LAUNCHXL_I2S0
#define Board_I2S_ADO           CC1310_LAUNCHXL_I2S_ADO
#define Board_I2S_ADI           CC1310_LAUNCHXL_I2S_ADI
#define Board_I2S_BCLK          CC1310_LAUNCHXL_I2S_BCLK
#define Board_I2S_MCLK          CC1310_LAUNCHXL_I2S_MCLK
#define Board_I2S_WCLK          CC1310_LAUNCHXL_I2S_WCLK

#define Board_NVSINTERNAL       CC1310_LAUNCHXL_NVSCC26XX0
#define Board_NVSEXTERNAL       CC1310_LAUNCHXL_NVSSPI25X0
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

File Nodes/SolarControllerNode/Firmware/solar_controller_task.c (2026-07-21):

#include <stddef.h>
#include <stdbool.h>
#include <unistd.h>
#include <stdio.h>
#include <stdint.h>
#include <string.h>
#include <mqueue.h>
#include <stdlib.h>
#include <ti/drivers/timer/GPTimerCC26XX.h>
#include <ti/drivers/PWM.h>
#include <ti/drivers/Watchdog.h>

#include <ti/drivers/Power.h>
#include <ti/drivers/Board.h>
#include <ti/sysbios/BIOS.h>
#include <ti/drivers/GPIO.h>
#include <ti/drivers/SPI.h>
#include <ti/display/Display.h>
#include <ti/sysbios/knl/Task.h>
#include <ti/sysbios/knl/Event.h>
#include <ti/sysbios/knl/Clock.h>
#include <ti/devices/DeviceFamily.h>

#include "ads1256.h"
#include "Board.h"
#include "node_identity.h"   /* gNodeAddress, CMD_JOIN_ACCEPT/REMOVE/UNREGISTERED, identity_persist */


//#define MAX_MSG_SIZE          50
#define SOLAR_CONTROLLER_QUEUE_NAME      "/solarControllerQueue"
#define SOLAR_CONTROLLER_TASK_STACK_SIZE 1536
#define SOLAR_CONTROLLER_TASK_PRIORITY   2


#define EVENT_SEND_PACKET     (1 << 0)
#define EVENT_RECEIVE_CMD     (1 << 1)
#define EVENT_MEASURE_TEMPERATURE (1 << 2)
#define SPI_MSG_LENGTH  6

typedef enum
{
    SOLAR_CONTROLLER          = 0,
    BUFOR_CONTROLLER          = 1,
    CURTAINS_CONTROLLER       = 2,
    LIGHT_CONTROLLER          = 3,
    VENTILATION_CONTROLLER    = 4,
} nodeType;
typedef enum
{
    SEND_DATA_TO_DB           = 0,
    SEND_PUMP_STATUS          = 1,
    TURN_PUMP_ON_OFF          = 2,
} solarControllerCmd;

typedef struct {
    uint8_t id;
    uint8_t type;
    uint8_t cmd;
    uint8_t length;
    union {
        struct {
            float Tin;
            float Tout;
            float T4;
            float T3;
            float T2;
            float T1;
            float Tcol;
            int   energyGain;
            int   flowRate;
            uint8_t pumpState;
        } solarData;

        struct {
            uint8_t pumpState;
        } pumpData;

        struct {
            float sBuforTemp;
        } buforData;

        struct {
            char text[30];
        } textData;

        /* provisioning: node -> gw (CMD_JOIN_REQUEST). */
        struct {
            uint8_t  factory_id[NODE_FACTORY_ID_LEN];
            uint32_t capabilities;   /* NODE_CAP(ACTION_*) this node can execute */
        } joinData;

        /* provisioning: gw -> node (CMD_JOIN_ACCEPT). */
        struct {
            uint8_t factory_id[NODE_FACTORY_ID_LEN];
            uint8_t assigned_addr;
        } joinAcceptData;
    } payload;
} MessageStruct;

#define SOLAR_CONTROLLER_QUEUE_MAX_MSG_SIZE sizeof(MessageStruct)

extern mqd_t radioQueue;
extern Event_Handle radioEventHandle;

static GPTimerCC26XX_Handle hTimer;
static GPTimerCC26XX_Params tParams;

static Watchdog_Handle watchdogHandle;
static Watchdog_Params watchdogParams;
static uint32_t        reloadValue;

static PWM_Handle pwm1 = NULL;
static PWM_Params pwm1Params;
static uint16_t   pwm1Period = 1200;
static uint16_t   pwm1Duty = 0;

static float measuredTemp[] = {500.0f, 500.0f, 500.0f, 500.0f, 500.0f, 500.0f, 500.0f, 500.0f};
static float measuredTempPrev[] = {500.0f, 500.0f, 500.0f, 500.0f, 500.0f, 500.0f, 500.0f, 500.0f};
static uint16_t   flowValue = 0; // Przep�yw w procentach
static float      energyGainFloat = 0;
static int   energyGain = 0;
static int        updatePwm = 1;
static float      deltaT_float = 0;
int min3couter = 17;
int send_data_to_db_flag = 11;

static Task_Struct solarControllerTaskStruct;
static uint8_t solarControllerTaskStack[SOLAR_CONTROLLER_TASK_STACK_SIZE];

//SPI_Handle spiHandleMasterEpaper;
//SPI_Params      spiParams0;
//SPI_Params      spiParams1;

static Event_Struct solarControllerEventStruct;
Event_Handle solarControllerEventHandle;
extern Display_Handle display;
mqd_t solarControllerQueue;

static void watchdogCallback(uintptr_t watchdogHandle)
{
    //GPIO_write(CC1310_LAUNCHXL_GPIO_RELAY3, 0);
    while (1) {}
}
void timerCallback(GPTimerCC26XX_Handle handle, GPTimerCC26XX_IntMask interruptMask)
{
    Event_post(solarControllerEventHandle, EVENT_MEASURE_TEMPERATURE);
}

static void solarControllerTaskFunction(UArg arg0, UArg arg1)
{
    //Zmienna do event�w
    uint32_t events;

    MessageStruct solarMessage;

    // Konfiguracja przeka�nik�w
    GPIO_setConfig(CC1310_LAUNCHXL_GPIO_RELAY1, GPIO_CFG_OUT_STD | GPIO_CFG_OUT_LOW);
    GPIO_write(CC1310_LAUNCHXL_GPIO_RELAY1, 0);
    GPIO_setConfig(CC1310_LAUNCHXL_GPIO_RELAY2, GPIO_CFG_OUT_STD | GPIO_CFG_OUT_LOW);
    GPIO_write(CC1310_LAUNCHXL_GPIO_RELAY2, 0);
    GPIO_setConfig(CC1310_LAUNCHXL_GPIO_RELAY3, GPIO_CFG_OUT_STD | GPIO_CFG_OUT_LOW);
    GPIO_write(CC1310_LAUNCHXL_GPIO_RELAY3, 0);

    //Inicjalizacja przetwornika ADC
    ADS1256_HardwareInit(Board_SPI0);
    ADS1256_Init();

    //Konfiguracja timera sprzetowego
    GPTimerCC26XX_Params_init(&tParams);
    tParams.width = GPT_CONFIG_32BIT;
    tParams.mode = GPT_MODE_PERIODIC;
    tParams.debugStallMode = GPTimerCC26XX_DEBUG_STALL_OFF;
    hTimer = GPTimerCC26XX_open(Board_GPTIMER2A, &tParams);
    GPTimerCC26XX_setLoadValue(hTimer, 480000000);
    GPTimerCC26XX_registerInterrupt(hTimer, timerCallback,GPT_INT_TIMEOUT);

    Watchdog_Params_init(&watchdogParams);
    watchdogParams.callbackFxn = (Watchdog_Callback) watchdogCallback;
    watchdogParams.debugStallMode = Watchdog_DEBUG_STALL_ON;
    watchdogParams.resetMode = Watchdog_RESET_ON;

    watchdogHandle = Watchdog_open(Board_WATCHDOG0, &watchdogParams);
    if (watchdogHandle == NULL) {
         /* Error opening Watchdog */
        Display_printf(display, 0, 0, "Error opening Watchdog");
    }
    //GPIO_write(CC1310_LAUNCHXL_GPIO_RELAY3, 1);
  //  reloadValue = Watchdog_convertMsToTicks(watchdogHandle, WATCHDOG_TIMEOUT_MS);

  //  if (reloadValue != 0) {
  //      Watchdog_setReload(watchdogHandle, reloadValue);
 //   }

    PWM_Params_init(&pwm1Params);
    pwm1Params.dutyUnits = PWM_DUTY_US;
    pwm1Params.dutyValue = pwm1Duty;
    pwm1Params.periodUnits = PWM_PERIOD_US;
    pwm1Params.periodValue = pwm1Period;
    pwm1 = PWM_open(Board_PWM1, &pwm1Params);
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

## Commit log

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2026-06-14 v5: Watchdog stack - layers A (systemd) and D (HW)
    - Warstwa A: systemd watchdog dla Go service (notify + WatchdogSec)
    - sd_notify minimalna implementacja w systemd_notify.go
    - watchdogKicker goroutine kickujący co WATCHDOG_USEC/2
    - debugDisableWatchdog dla test mode hang
    - Test A (kill -9): auto-restart w 2-3s
    - Test B (hang): SIGABRT + auto-restart w 12s
    - Warstwa D: Linux HW watchdog (/dev/watchdog)
    - RuntimeWatchdogSec=30 w system.conf
    - systemd PID 1 klepie /dev/watchdog0 co 30s
    - HW timeout 60s
    - Test: kernel panic (sysrq c) -> full SoC reset w 60s -> auto-recovery
    - docs/WATCHDOG.md - dokumentacja stack'u
    - docs/TROUBLESHOOTING.md - lessons o nowayout
2026-06-15 Priorytet 1: drop M4F-initiated heartbeat, add Go HELLO retry
    M4F (option A): remove heartbeat initiation - sendHeartbeatPing(),
    doHeartbeatCheck(), globals gLastRxTimeUs/gPingInFlight/HEARTBEAT_IDLE_US,
    and the MSG_PING branch in processEventRetries. M4F keeps replying ACK to
    Linux PING (one-way heartbeat Linux->M4F; M4F cannot reset Linux yet).
    M4F bugfix: case MSG_PING replied deprecated MSG_PONG -> now sendAck().
    Go waits for MSG_ACK, so PONG risked a false PEER DEAD / restart loop.
    Go: add helloWithRetry() with exponential backoff (1/2/4/8s, 5 attempts)
    to catch the startup race; wired into runHelloTest.
    Sync m4f-firmware/protocol.h with shared/protocol.h. Update CLAUDE.md
    status + s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
    [ipc_rpmsg_echo.c]
2026-06-15 Wire HW watchdog (Warstwa D) into setup, fix broken orchestrator
    Add modules/05-watchdog.sh: idempotently set RuntimeWatchdogSec=30 in
    system.conf so systemd kicks /dev/watchdog0. Fresh image + setup left
    Layer D off, so a full freeze (M4F silent-hang wedging the kernel) had
    no last resort and needed a manual power cycle.
    Clean up setup.sh: remove duplicated half-edited module loop (with
    inline edit notes that broke parsing) and log_info use-before-def.
    Single module loop now runs via `bash` so a missing exec bit can't
    silently skip a module.
2026-06-15 Update CLAUDE.md: silent-hang result + watchdog/recovery priorities
    Record silent-hang outcome (detection OK, remoteproc-stop recovery
    wedges the SoC), the confirmed no-per-core-reset constraint, watchdog
    now wired into setup, and the new Priorytet 1 (Go clean-reboot recovery
    + verify Layer D + reconcile docs).
2026-06-15 Fix cold-boot startup race: wait for M4F rpmsg device
    After reboot, systemd started rpmsg-service before M4F announced its
    rpmsg_chrdev endpoint, so OpenTransport failed with "no M4F rpmsg_chrdev
    device found", exited, and hit StartLimitBurst (failed permanently).
    Add waitForM4FChrdev(): poll for /dev/rpmsg* every 500ms up to 20s
    (bounded under the unit's TimeoutStartSec=30s) instead of failing on the
    first miss. Verified: service comes up on its own after a cold reboot.
2026-06-15 Docs cleanup: reconcile watchdog/heartbeat/recovery state
    README + docs/WATCHDOG.md were stale: claimed Restart=always (it's
    on-failure), "smart heartbeat zrezygnowany" (it's one-way Linux->M4F
    and is the M4F-death detector), and Go 1.26.4 (it's 1.23.x).
    Update to reflect reality: Warstwa D configured via modules/05-watchdog.sh
    (was missing from setup, lost on re-flash), M4F death -> clean reboot
    (recoverByReboot; no per-core M4F reset on AM62, remoteproc stop wedges
    the SoC), cold-boot device wait. Add lesson: reliability config must live
    in an idempotent setup module, not ad-hoc.
    Remove redundant system/configure-watchdog.sh (module 05 supersedes it).
2026-06-16 P2: transport fast-fail on device-gone -> immediate peer-dead
    Transport exposes a DeviceGone() channel closed once when the rpmsg
    device disappears at runtime (broken pipe/not pollable/no such device).
    Protocol's deviceGoneWatcher bridges it to signalPeerDead, so a vanished
    M4F endpoint triggers the clean-reboot recovery immediately instead of
    waiting ~9s for the heartbeat to time out. Same end action.
    Verified on hardware: `echo stop > .../remoteproc0/state` on a healthy
    M4F -> reboot issued in ~3ms (heartbeat never fired).
    Also: drop industrial-SD TODO (prod runs on eMMC), refresh status/log.
2026-06-16 M4F: silence periodic tick log + disable test EVENT scaffolding
    doPeriodicTick no longer logs "[M4F] Tick #N" every second (it spammed
    the m4f-watch trace) and no longer fires the 10s test EVENT. That EVENT
    was scaffolding gated only on gLinuxEndpoint != 0, which stays set after
    first contact, so once the Linux service stopped/restarted the EVENTs
    got no ACK -> retries -> GIVEUP / "ACK for unknown" noise.
    sendEvent() is unchanged; real EVENTs must come from actual event
    sources, not a free-running timer. The demo block is left commented for
    easy re-enable during testing.
    Pending: sync into the CCS Theia project + rebuild + Deploy-M4F (M4F
    firmware builds from a separate source copy, not fr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
    [ipc_rpmsg_echo.c]
2026-06-16 m4f-reload: stop/start rpmsg-service around firmware swap
    After the P2 fast-fail change, the running rpmsg-service treats the
    'echo stop' on the M4F (during reload) as a vanished /dev/rpmsg ->
    PEER DEAD -> immediate gateway reboot, which broke firmware deploys
    mid-swap.
    m4f-reload now stops rpmsg-service before touching the M4F and restarts
    it afterwards via a trap (covers error paths too); it only restarts if
    the service was active. Pre-flight checks run before the stop, so a
    trivial error never bounces the service. Bonus: the freed device makes
    the M4F stop clean (no kill fallback needed).
    Logic lives in m4f-reload (repo, versioned) not Deploy-M4F (PowerShell,
    off-repo), so every caller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
2026-06-16 Add modules/06-kernel-panic.sh: panic_on_oops=1
    Closes the "oops without panic" recovery gap. By default a kernel oops
    (NULL deref, BUG()) kills the offending thread and limps on in an
    inconsistent state; systemd stays alive and keeps kicking the HW
    watchdog, so Warstwa D never fires and the gateway looks alive while
    being broken. Setting kernel.panic_on_oops=1 promotes every oops to a
    full panic, which the HW watchdog already recovers (verified earlier
    with `echo c`). Fail-fast, consistent with the rest of the design.
    Idempotent drop-in at /etc/sysctl.d/60-bramka-panic.conf, applied at
    runtime too. kernel.panic (auto-reboot delay) is left untouched on
    purpose -- recovery is verified on the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
2026-06-16 Add modules/07-boot-accounting.sh: reboot counter + cause attribution + alarm
    Records every boot with a persistent counter and a cause-attributed
    ledger, and raises an alarm on reboot storms.
    Attribution: controlled reboots leave a breadcrumb
    (/var/lib/bramka/reboot_reason) before going down -- Go's recoverByReboot
    now writes "go-peer-dead". A boot-time oneshot reads+clears it; with no
    breadcrumb it classifies the prior boot from journalctl -b -1 (kernel
    panic -> Warstwa D, clean-shutdown signature -> manual, else hard reset).
    Needs persistent journald, so this enables it (50M cap) -- which also
    gives cross-boot logs for diagnosing storms.
    Alarm is runtime-tunable in /etc/bramka/boot-accou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
2026-06-16 boot-accounting: fix "first boot" detection (journalctl header miscount)
    journalctl --list-boots includes a header line, so `wc -l` returned 2
    for a single boot and the "no previous boot" branch was skipped --
    classifying the first accounted boot (right after persistent journald is
    enabled, when only the current boot exists) as a hard reset instead of
    INFO. Gate on whether `journalctl -b -1` actually has an entry instead.
2026-06-16 boot-accounting: make journald actually persistent (volatile /var/log fix)
    /var/log is a symlink to tmpfs /var/volatile/log on this Arago image, so
    Storage=persistent had nowhere persistent to write -> journald stayed
    volatile and `journalctl -b -1` found nothing after a reboot. That also
    broke boot-accounting's non-breadcrumb cause classification (everything
    fell through to "no previous-boot log").
    Back the journal with /var/lib/journal (persistent) bind-mounted onto
    /var/log/journal via var-log-journal.mount. systemd-journal-flush's
    RequiresMountsFor=/var/log/journal auto-orders the flush after the bind,
    so journald switches to persistent reliably without racing its early
    start. Activated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
2026-06-16 boot-accounting: fix journal bind unit name (canonicalized path)
    The .mount unit must be named after the canonicalized Where= path.
    /var/log is a symlink to /var/volatile/log, so Where=/var/log/journal
    canonicalizes to /var/volatile/log/journal and the unit must be
    var-volatile-log-journal.mount. The previous var-log-journal.mount was
    ignored by systemd at boot (it only mounted because setup did a manual
    mount --bind), so persistence didn't survive a reboot. Rename unit +
    Where to the real path; clean up the old wrong-named unit.
2026-06-16 boot-accounting: classify via persistent clean-shutdown marker, not journal
    Persistent journald on this volatile-/var/log image is finicky (systemd
    mount-ordering hell), and cause classification shouldn't depend on it.
    Switch to a persistent marker in /var/lib (ext4):
    - boot-accounting.service ExecStop touches /var/lib/bramka/clean_shutdown,
    so it exists at next boot iff the last shutdown ran systemd's stop
    sequence (clean reboot/poweroff).
    - classify: breadcrumb -> CONTROLLED(go); else clean marker ->
    CONTROLLED(manual); else UNEXPECTED hard reset. Journal panic-detection
    kept as a best-effort refinement only.
    Persistent journal is now best-effort via a oneshot bind service
    (bramka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
2026-06-16 docs: add ARCHITECTURE-GEN2.md (engine port plan + SPI/RPMsg protocols)
    Full gen2 design grounded in the proven gen1 code: role split
    (CC1310 radio / M4F engine on RTOS / A53 Linux host), decision log,
    SPI link protocol (M4F master, CC1310 slave, 2-line MASTER_READY/
    SLAVE_READY handshake, 128B framed + CRC16 + pending burst-drain),
    RPMsg additions (MSG_RULE_BEGIN/ITEM/COMMIT chunked + atomic swap,
    MSG_NODE_CMD/TELEMETRY/STATE/RULE_FIRED), end-to-end flows, and the
    gen1->gen2 port mapping. JSON stays on Linux; M4F gets binary rules.
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2026-06-17 gen2 engine: M4F FreeRTOS automation engine + Go rule-push (verified live)
    Port the gen1 automation engine to the AM62 M4F and wire end-to-end rule
    upload from Linux. Verified on hardware 17.06: 3 rules pushed
    (BEGIN/ITEM*/COMMIT), COMMIT->ACK = count+CRC32 match -> atomic swap.
    M4F (m4f-firmware/):
    - engine.{c,h}: RTOS-agnostic core. evaluateAutomationRules port (~1:1, D6
    parity + solar guards), NodesData folding (coreTask port), atomic
    double-buffer ruleset swap (lock-free index + CRC32 IEEE). g_rules placed
    in a .bss.engine_rules section (DDR) - 39 KB doesn't fit 64 KB M4F DRAM.
    - engine_rpmsg.{c,h}: RPMsg glue. RULE_BEGIN/ITEM/COMMIT + NODE_CMD dispatch,
    reply(MSG_ACK|MSG_ERROR,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
    [ipc_rpmsg_echo.c]
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2026-06-19 gen2 M4F: real SLAVE_READY GPIO-IRQ + fix TIME double-fire at :00
    - spi_master.c: SLAVE_READY interrupt via WKUP_MCU_GPIOMUX introuter
    (Sciclient route OUTP 4-7, falling-edge bank ISR), poll kept as backstop.
    Earlier "RM-denied" conclusion was wrong - M4_0 owns OUTP 4-7; the r=-1
    was a wrong src_index (bank 0 vs bank 1; SLAVE_READY = MCU_GPIO0 pin 16).
    - engine.c: TIME dedup key biased +2s so a wake landing a few ms before :00
    (FreeRTOS tick vs ClockP phase skew) no longer double-fires the boundary.
    [spi_master.c]
2026-06-19 gen2 remote-access Phase 1: phone -> pump E2E over HTTPS
    - nodecmd.go: SendPump builds the gen1 node command (SOLAR_CONTROLLER /
    TURN_PUMP_ON_OFF / pumpState), NOT a raw SMARTPHONE text - the node only
    acts on the translated form (matches gen1 coreTask.c).
    - httpapi.go: phone-facing HTTPS server on :9443, token auth, gen1 routing
    (PUMP_ON/OFF now live; getrules/setrules stubbed for Phase 2). App pins the
    same cert; key/cert served from /etc/bramka/tls (gitignored).
    - main.go: -test serve mode (HELLO -> NTP time-sync -> push ruleset on connect
    -> drain events -> HTTPS API). Pushing rules on connect clears stale engine
    state; early event drain avoids reconnect-backlog overflow.
    Ve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
2026-06-19 gen2 M4F: fix remoteproc "won't stop" - send shutdown ACK before driver teardown
    Trace showed doShutdown hung in Drivers_close()/System_deinit() while the
    SHUTDOWN_ACK was sent only AFTER them, so it never reached Linux -> remoteproc
    stop timed out ("M4F won't stop"). Root cause was ordering, not the IRQ teardown.
    - ipc_rpmsg_echo.c doShutdown: spi_master_shutdown() (stop SPI task + tear down
    the SLAVE_READY GPIO-IRQ: bank intr disable + HwiP_destruct + Sciclient route
    release, bounded) -> send ACK -> WFI. Drivers_close()/System_deinit() dropped:
    on AM62 with the introuter route they can block, and the core is reset on the
    next load anyway.
    - spi_master.{c,h}: gSpiStopped flag + spi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
    [ipc_rpmsg_echo.c, spi_master.c]
2026-06-19 gen2 engine: drop solar sBuforTemp guard + 4s tick-time snap (TIME rules fire on the minute)
    Two fixes verified live (phone time-rule schedules the pump to the exact minute):
    - Removed the gen1 "skip solar SET_RELAY while sBuforTemp < 0" guard (kept,
    commented, with a note to restore once the buffer node streams telemetry).
    sBuforTemp inits to -20, so with only the pump node connected the guard blocked
    every pump rule. The pumpState dedup (level-trigger feedback) stays.
    - evaluateTimeCondition read raw wall_now; a tick can wake a few ms/s before :00
    (FreeRTOS-tick vs ClockP skew) so floor() read the previous minute -> a window
    starting on the boundary fired one minute late (OFF se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
2026-06-21 gen2 provisioning Phase 0: temp/humidity node type (NODE_TH_SENSOR=6) E2E
    Add a new node type end-to-end: node_protocol.h gets type 6 + thData
    {temperature,humidity} (union, MessageStruct stays 44B); telemetry.go decodes
    it; store.go seeds its param_def. Fix M4F (ipc_rpmsg_echo.c): forward raw
    NODE_TELEMETRY to Linux for EVERY node type, not only engine-recognised ones
    (was gated on engine_update_node()), so a T/H sensor reaches the DB. Verified
    live: node 243 type 6 -> node_param (temp/humidity), alongside solar+bufor.
    [ipc_rpmsg_echo.c, node_protocol.h]
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2026-06-21 gen2 provisioning Phase 1 (steps 1-3): JOIN uplink E2E
    Node button -> JOIN_REQUEST (factory id from CC1310 FCFG, src 0xFF) -> gateway ->
    M4F -> Go demux -> pending-join registry. node_protocol.h gains CMD_JOIN_REQUEST/
    ACCEPT + join payloads + address scheme (gateway 0xF0 legacy, 0xFF unprovisioned,
    pool 0x10-0xEF). Node sends src from msg.id; gateway radio_task TX dest from
    msg.id (was hardcoded 0xF1). New join.go registry; telemetry.go decodes JOIN;
    main.go routes it.
    Fix (pre-existing reliability bug): reset theirLastSeq on HELLO_ACK. The M4F
    resets its outgoing seq on reconnect, so after a large pre-connect backlog live
    events (lower seq) were dropped as duplicates before EventRx -- tel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
    [node_protocol.h, radio_task.c, rfEchoTx.c]
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2026-06-22 gen2 provisioning: graceful remove + status lifecycle + listnodes
    Two-phase commissioning with node read-back confirmation, verified live
    (add / remove-online / remove-offline / re-add reuses freed address):
    - node.status lifecycle: pending_join | active | pending_remove. Address
    reserved while the row exists; the row is deleted (address freed) only
    when the node confirms. allocAddr = lowest-free (reuse) - safe given the
    confirm invariant (a monotonic watermark was tried then dropped).
    - ADD: approve -> pending_join; node persists+reads-back the assigned addr
    and sends an immediate confirm; gateway flips active on first telemetry.
    - REMOVE (graceful): removenode marks pending_remove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
    [node_protocol.h]
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2026-06-26 gen2: real battery T&H node (CC1310+SHT35+BQ35100) E2E + batt_mv telemetry
    First physical battery-powered gen2 node, verified live on battery:
    TPL5111 power-cycles it (~3 min); each cold boot reads SHT35 + BQ35100,
    sends to the gateway, pulses DONE (DIO23) -> timer cuts power. DB shows
    node 26 type 6 with temperature/humidity/batt_mv (2875 mV on a CR123A).
    - Telemetry: thData gains batt_mv (shared/node_protocol.h); telemetry.go
    decodes it; store.go param_def for type 6. MessageStruct still 44B;
    M4F forwards raw (no reflash).
    - Mirror cc1310-th-hw-firmware/ (rfWsnNode.c, radio.c/h, sensors.c/h,
    README). Off-repo CCS project TemperatureHumidityNode_CC1310; radio
    swapped from EasyLink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
    [node_protocol.h, rfWsnNode.c, sensors.c]
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2026-06-29 gateway: CC1310 gateway CCS project into repo (Gateway/Firmware/CC1310)
    - real CCS project moved in (rfWsnConcentrator + radio_task + spi_slave_task +
    smartrf_settings + board/ccfg/linker + build config); retires the mirror
    - spi_frame.h consolidated to Shared/Protocol (drifted local copy removed -
    canonical has the _Static_assert) + include path -> Shared/Protocol
    - project renamed -> gateway_cc1310
    - .gitignore: **/Release/, .launches/, overview.rov.json
    [Board.h, CC1310_LAUNCHXL.c, CC1310_LAUNCHXL.h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]
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2026-07-03 hw(temphum-node): attach CC1310 3D model + fix orientation
    Add TI CC1310F128RGZR STEP model to 3dmodels and point both the
    library footprint and the board instance at it (was a bare, missing
    .stp path). Rotate -90deg X so it sits flat. Ignore KiCad autosave.
    [CC1310F128RGZR.step, temphum_node.kicad_pcb]
2026-07-03 hw(temphum-node): add SHT35 (custom symbol layout) + schematic/board progress
    Import SHT35-DIS-B (LCSC C90161) footprint + 3D model, and swap the
    symbol graphics for the user's custom pin arrangement from the
    temperatureSensorSubGHz project (keeps footprint link + LCSC/BOM
    fields). Plus in-progress schematic/board work.
    [DFN-8_L2.5-W2.5-H1.0-P0.50.step, temphum_node.kicad_pcb, temphum_node.kicad_sch]
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2026-07-05 hw(temphum-node): wire MCP3421 battery-SoC ADC + gated divider
    MCP3421 (0x68) on 3V3_SW, VIN-=GND, VIN+=1M/1M 0.1% divider tap (Ctap
    10nF). Divider high-side gated by a 2nd TPS22860 (BAT+->BAT+_SW, ON=
    PERIPH_EN, VBIAS=VIN=BAT+): ~18nA guaranteed leakage, tap collapses to
    ~0 in sleep so VIN+ can't back-leak into the off ADC. Chosen over a
    complementary MOSFET pair (uncertain 1uA IDSS max).
    [temphum_node.kicad_sch]
2026-07-05 hw(temphum-node): CC1310 support parts - pogo/ESD 3D, crystal swaps
    Add TC2030-IDC UART pogo (SnapEDA, both footprints + 3D, symbol made
    SmartHome-native). Attach TPD6E004 ESD 3D model + merge its symbol into
    SmartHome. Add in-stock crystal replacements: ECS-240-9-33B (24MHz 9pF,
    capless HF) and Epson FC-135R (32.768kHz 12.5pF, 2x12pF caps) - both CL/
    ESR-matched drop-ins. Plus CC1310 schematic GPIO/pogo wiring.
    [CRYSTAL-SMD_4P-L3.2-W2.5-BL.step, OSC-SMD_L3.2-W1.5-H0.8.step, TC2030-IDC.step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]
2026-07-05 hw(temphum-node): passive footprints/3D, ferrite/inductor/LED/0805 parts
    Add ferrite bead BLM18HE152 (L0603), DCDC inductor MLZ2012N6R8 (IND-
    SMD), 0805 cap footprint, red LED XL-1608SURC (LED0603). Attach 3D
    models to the perfected passive footprints (C_0402, C_0603, R_0603,
    L_Polarized_0402) - library + all placed board instances; R_0603 model
    orientation fixed (rotate 0 0 -90). Node schematic essentially
    complete; only the battery connector remains before layout.
    [C0402_L1.0-W0.5-H0.5.step, C0603_L1.6-W0.8-H0.8.step, C0805-SMD_L2.0-W1.25.step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]
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2026-07-10 hw(temphum): rev2 node schematic + PCB layout + KiCad lib parts
    Full rev-2 T&H node hardware: wired schematic, 4-layer PCB layout
    (RF-first placement, GND stitching, DRC-clean). Library additions:
    JST XH 2.5mm connector (C158012), R_0402, and imported/perfected
    footprints. USB-C center holes fixed to NPTH (annular-ring clean).
    [R0402_L1.0-W0.5-H0.4.step, XH2.5-2A.step, temphum_node.kicad_pcb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]
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2026-07-19 m4f: fix the SPI-collision silent hang (full-duplex CC1310 transfer)
    The long-standing intermittent M4F silent hang (Go heartbeat times out ->
    clean reboot) is a downlink<->uplink SPI collision. The M4F<->CC1310 link
    was half-duplex with two independent initiators: the master drives a
    downlink cmd (MASTER_READY) while the slave drives an uplink reading
    (SLAVE_READY). When both fire at once the slave armed with DATA but its
    SEND_DATA path never route_rx_frame'd the master's cmd, and the desynced
    transfer wedged the SPI ISR -> TOTAL starve (no [MON], no [DIAG], no
    timeout: even the monitor task was starved).
    Reproduced deterministically: a pump-command flood (downlink) over live
    telemetry (up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
    [ipc_rpmsg_echo.c, spi_master.c, spi_slave_task.c]
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2026-07-21 automation: per-node rework across protocol/engine/Go + capabilities-at-JOIN
    Replace the gen1 type-based automation model (single global node state,
    device-type-keyed rules) with a per-node model addressed by RF address,
    resolved from the stable node_id at push time.
    Layer 1 (protocol, automation.h/node_protocol.h):
    - rules key nodes by RF address (nodeAddr in conditions/action), not
    device-type codes; RuleAction value is a float (extensible actions:
    relay on/off, future pump-speed %). ABI sizes unchanged.
    - extend PARAM_* (Tcol/energyGain/flowRate/pumpState/temperature/humidity/
    batt_mv); ACTION_* + NODE_CAP(action) capability bit.
    - joinData carries a capabilities bitmask the node d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
    [automation.h, ipc_rpmsg_echo.c, node_protocol.h]
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2026-07-23 node(temphum): rev-2 board bring-up E2E — RF JOIN + SHT35 + MCP3421 + charging + NVS
    The custom rev-2 T&H PCB works end to end (project: Nodes/TempHumNode/Firmware,
    rfWsnNode.c). Boot -> NVS address? stream : wait for JOIN. Verified live: phone
    popup, JOIN_ACCEPT (addr 0x11), live temp/humidity in the app (RSSI -22).
    - Pin map (confirmed by a GPIO sweep; KiCad symbol names pins by DIO=IOID, pkg pin
    differs, e.g. pin18=IOID_12): UART TX/RX=DIO12/13, I2C SCL/SDA=DIO9/10, JOIN=DIO26,
    PERIPH_EN=DIO25, nCHRGSTAT=DIO14. Board files reworked (UART/I2C defines, GPIO enum +
    PERIPH_EN/nCHRGSTAT, button->DIO26, stale PIN_BTN1/2 removed from the PIN table).
    - RF: JOIN uplink via the rev-1 'D' f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
    [Board.h, CC1310_LAUNCHXL.c, CC1310_LAUNCHXL.h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]
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2026-07-25 §14: NACK downlink to sleeping nodes + M4F RX ring — verified E2E
    Deliver a command (unregister now, config later) to a node that isn't
    listening by holding a {factory_id->cmd} table on the CC1310 and sending
    it in a NACK in the RF ACK window of the node's next uplink. The CC1310
    ACKs autonomously on RF, so the ACK-vs-NACK decision lives there, not in
    Go. Node executes + confirms -> entry dropped; keyed by factory_id (not
    the reusable address). Two-tier: CC1310 table = volatile cache (armed
    proactively at removal), Go's SQLite registry = durable truth that
    re-arms reactively on any unbound uplink (survives a gateway reboot).
    At removal Go now sends BOTH a direct UNREGISTERED (always-on no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
    [ipc_rpmsg_echo.c, node_protocol.h, radio_task.c]
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
